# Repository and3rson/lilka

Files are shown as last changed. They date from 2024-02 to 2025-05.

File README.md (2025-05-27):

# Лілка






[][discord]

DIY-консоль, яку можна зібрати з дешевих готових модулів.

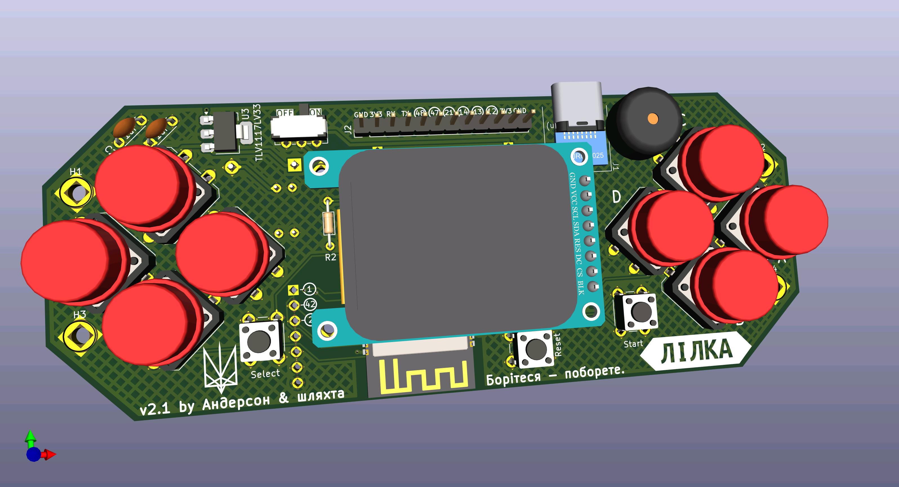
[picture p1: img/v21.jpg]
Лілка v2


## Де її можна купити?

Всі посилання та інструкції доступні [ось тут](https://lilka.dev/shop/)!

## Демо

Новини про проєкт Лілка V2:

Новини про проєкт "Лілка (https://www.youtube.com/watch?v=Xh49N__p2jE)

Перша версія Лілки:

Проєкт "Лілка" (https://www.youtube.com/watch?v=6Tz70vqRrs0)

## Документація

Повна документація проєкту буде доступна ось тут: <https://docs.lilka.dev>

## Спільнота

Приєднуйтесь до [нашого сервера в Discord][discord]!

## Я хочу допомогти писати код!

Ми будемо тільки раді! Є декілька варіантів:

- Хочете написати гру, програму, документацію чи щось таке? Звісно! Документація є [тут (C++)](https://docs.lilka.dev/uk/latest/keira/custom_apps/) і [тут (Lua)](https://docs.lilka.dev/uk/latest/keira/lua/intro/).
- Хочете допомогти з вдосконаленням коду? Виконайте команду `make todo` - вона відобразить всі TODO з коду, де потрібна допомога.
- Хочете допомогти ідейно? Знайшли баг або маєте ідею щодо покращення архітектури? Створіть новий тікет або пишіть в наш [Discord][discord] в форум `#лілка`.

[discord]: https://discord.gg/HU68TaKCu6

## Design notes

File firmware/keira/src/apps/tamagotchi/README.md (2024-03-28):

# ArduinoGotchi - A real Tamagotchi emulator for Arduino UNO

## Synopsis

**ArduinoGotchi** is a real [Tamagotchi P1](https://tamagotchi.fandom.com/wiki/Tamagotchi_(1996_Pet)) emulator running in Arduino UNO hardware. The emulation core is based on [TamaLib](https://github.com/jcrona/tamalib) with intensive optimization to make it fit into UNO's hardware that only comes with 32K Flash 2K RAM.

Tamagotchi P1 Actual Devices

## Fork notice

I did following changes after forking [original repo](https://github.com/GaryZ88/ArduinoGotchi)
- Created platformio project, so it is easy to target multiple platforms
- Created ports for ESP8266 and ESP32, mainly because speed on 8-bit AVR is just too slow
- Added long click on "back" button - if you press it for 5 seconds, it will reset memory back to egg state
- Added inverted Speaker connection setting. Mainly because Piezo modules that I have are active on Low. Another reason is mention below.

I personally assembled ESP8266 version with Wemos D1 Mini on perfboard, using built-in LED together with speaker, so when it sounds, led is blinking as well.

### Demo
Demo #1
Demo #2
Demo #3

## How to build and run

Use Platformio. Run `build` task to build for all platforms. Next run `Upload` task for specific platoform

### Additional notes
- To activate your pet, you have to configure the clock by pressing the middle button. Otherwise, your pet will not alive.
- The emulator will save the game status for every 5 mintues. You can change that by changing AUTO_SAVE_MINUTES setting
- The speed of the emulator is a bit slower than the actual Tamagotchi device on AVR, still, it is fun. On ESPs it runs smooth.
- There are a few consts in the `platformio.ini` that you can adjust to fit your need:
```
  -D DISPLAY_I2C_ADDRESS=0x3C
  -D SCREEN_WIDTH=128
  -D SCREEN_HEIGHT=64
  -D ENABLE_TAMA_SOUND
  -D ENABLE_TAMA_SOUND_ACTIVE_LOW
  -D ENABLE_AUTO_SAVE_STATUS
  -D ENABLE_LOAD_STATE_FROM_EEPROM
```

### Circuit Diagram
Circuit Diagram

### Wemos D1 Mini






### License
ArduinoGotchi is distributed under the GPLv2 license. See the LICENSE file for more information.

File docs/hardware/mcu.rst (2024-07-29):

.. _mcu:

Мікроконтролер
==============

Лілка використовує :term:`мікроконтролер` ``ESP32-S3-WROOM-1-N16R8``.
На відміну від ``ESP32-S3``, "WROOM" - це модуль, який містить в собі не лише сам мікроконтролер ``ESP32-S3``, а й флеш-пам'ять, додаткову оперативну пам'ять, кристал, антену та інші компоненти, необхідні для повноцінної роботи мікроконтролера.
Це дозволяє значно спростити розробку плати, оскільки вся "обв'язка" мікроконтролера вже виконана на модулі, а також полегшити збір, оскільки модуль можна встановити на плату за допомогою простого :term:`SMD`-монтажу звичайним паяльником.

.. list-table::
   :header-rows: 1
   :align: center

   * - ESP32-S3
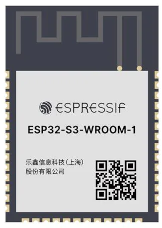
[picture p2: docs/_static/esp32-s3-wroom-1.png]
ESP32-S3-WROOM-1
     - 
   * - ESP32-S3
     - ESP32-S3-WROOM-1

Характеристики ESP32-S3 наступні:

- **Частота процесора: 240 МГц**
- **Кількість ядер: 2**
- **Оперативна пам'ять: 512 КБ**
- **Вбудований Wi-Fi (802.11 b/g/n)**
- **Вбудований Bluetooth (BLE)**
- **45 пінів** :term:`GPIO`
- ROM: 384 КБ (використовується внутрішньо, не доступний для користувача)
- 4 шини SPI (2 з них доступні для користувача)
- 2 шини I2S
- 2 шини I2C
- 3 шини UART
- 8-канальний :term:`ШІМ`-контролер
- 2 10-канальні 12-бітні :term:`АЦП`
- Апаратний криптографічний прискорювач (AES, RSA, RNG, HMAC)
- USB-контролер (з підтримкою USB-OTG та CDC, що дозволяє програмувати мікроконтролер через USB без додаткового UART-перетворювача)

Модуль ``ESP32-S3-WROOM-1-N16R8`` містить в собі деякі додаткові компоненти:

- Суфікс ``N16`` означає наявність **16 MB Flash-пам'яті типу NOR** (для зберігання прошивки та вбудованої файлової системи SPIFFS).
- Суфікс ``R8`` означає наявність **8 MB PSRAM** (додаткова оперативна пам'ять).
- **36 пінів** :term:`GPIO` (5 з них використовуються для USB та внутрішньої пам'яті)
- Кристал, необхідний для роботи мікроконтролера
- Антена
- Конденсатори та інші компоненти

.. tip:: Відмінною властивістю ESP32-S3 є наявність вбудованого мультиплексора GPIO, який дозволяє використовувати апаратний SPI, I2C, I2S, UART та інші шини на будь-яких GPIO-пінах.

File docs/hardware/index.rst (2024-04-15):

:octicon:`cpu` Технічні дані
============================

.. toctree::
    :maxdepth: 2
    :caption: Зміст

    mcu
    schematics

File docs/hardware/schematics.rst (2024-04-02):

Креслення (V2)
==============

Електронна схема (v2)
---------------------

  * Завантажити PDF: :download:`PDF <../_gen/v2_schematic.pdf>`
  * `Онлайн-перегляд схеми <https://kicanvas.org/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>`_

Креслення PCB (v2)
------------------

  * Завантажити PDF: :download:`PDF <../_gen/v2_pcb.pdf>`
  * `Онлайн-перегляд друкованої плати <https://kicanvas.org/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>`_

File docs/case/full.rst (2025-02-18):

Моделі корпусів
===============

    .. warning:: 

        Уважно читайте інструкцію до кожної моделі, перш ніж розпочинати її друк! Кожен корпус має свої особливості та розрахований на різні моделі акумуляторів. 
        Також збірка плати для конкретного корпусу може дещо відрізнятися від тієї, що описана в документації.

**Корпус з кришечкою на пінах, для легкого доступу до них**  

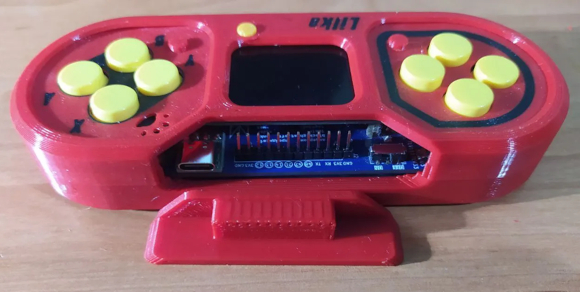
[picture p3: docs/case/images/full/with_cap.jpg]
З_кришечкою

   
Посилання:
https://www.printables.com/model/1173882-slim-case-for-lilka

**Мінімалістичний корпус без додаткових вставних частин**

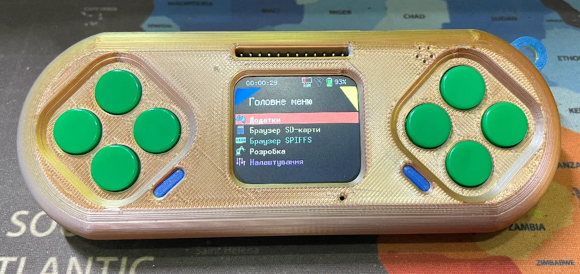
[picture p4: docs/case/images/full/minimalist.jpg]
Мінімалістичний


Посилання:
https://www.printables.com/model/1120079-lilcase  

**Корпус в стилі "Quadratisch.Praktisch.Gut"**

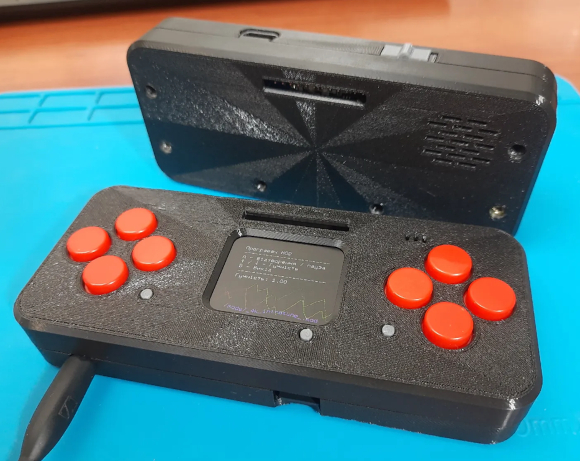
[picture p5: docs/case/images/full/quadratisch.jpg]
Квадратіш


Посилання:
https://www.printables.com/model/1181426-low-profile-case-for-lilka-dev-board

**Мінімалістичний корпус без заглиблень під кнопки**

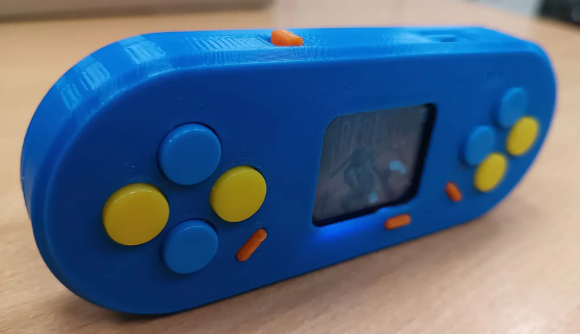
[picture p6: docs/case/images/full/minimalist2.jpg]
Мінімалістичний2


Посилання:
https://www.printables.com/model/1189054-case-for-lilka-dev-board

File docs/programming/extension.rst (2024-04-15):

.. _extension:

Роз'єм розширення
=================

.. contents:: Зміст
    :local:
    :depth: 1

Загальна інформація
-------------------

Роз'єм розширення (англ. *extension header*) - це роз'єм, який дозволяє підключати до основної плати додаткові модулі, наприклад датчики, дисплеї, сервоприводи тощо.

Лілка має 12-контактний роз'єм розширення.

Ці піни можна використовувати для будь-якої цілі. Саме тому вони і називаються GPIO (General Purpose Input/Output) - вхід/вихід загального призначення.



На роз'єм розширення Лілки виведені наступні піни:

- ``3.3V`` - живлення 3.3 Вольти
- ``GND`` - земля
- ``12``, ``13``, ``14``, ``21``, ``47``, ``48`` - GPIO
- ``TX``, ``RX`` - додатковий UART. Ці піни можна використати для з'єднання Лілки з комп'ютером через перетворювач USB-UART та навіть прошивати її через цей порт. Але ви також можете без проблем використовувати ці піни для будь-яких інших цілей в додачу до перелічених вище пінів, а для прошивання використовувати USB-порт Лілки.

Вони не використовуються Лілкою для жодних внутрішніх потреб, тому ви можете використовувати їх для будь-яких цілей.

Завдяки вбудованому мультиплексору, кожен пін можна використовувати для шин I2C, SPI, UART, або просто як вхід/вихід.

Крім того, піни ``12``, ``13`` та ``14`` під'єднані до АЦП (аналого-цифрового перетворювача, ADC):

- ``12`` - ADC2, канал 1
- ``13`` - ADC2, канал 2
- ``14`` - ADC2, канал 3

Приклад використання GPIO
-------------------------

Найпростіший приклад використання GPIO - це підключити до роз'єму розширення світлодіод та резистор, щоб світлодіод світився, коли на пін подаватиметься напруга.

Наприклад, пін ``12`` можна підключити до анода світлодіода (довший вивід), а катод світлодіода (коротший вивід) - через резистор до землі (наприклад, 100 Ом).

Обчислити значення резистора для світлодіода можна за `цим посиланням <https://www.digikey.com/en/resources/conversion-calculators/conversion-calculator-led-series-resistor>`_.



Після цього можна використати наступний код для того, щоб світлодіод блимав:

.. code-block:: cpp

    #include <lilka.h>

    void setup() {
        lilka::begin();
    }

    void loop() {
        digitalWrite(12, HIGH);
        delay(500);
        digitalWrite(12, LOW);
        delay(5000);
    }

Використання GPIO для шини I2C
------------------------------

Щоб використати піни розширення для шини I2C, використайте наступний код:

.. code-block:: cpp

    #include <lilka.h>
    #include <Wire.h>

    #define SDA_PIN 13
    #define SCL_PIN 14

    void setup() {
        lilka::begin();
        Wire.begin(SDA_PIN, SCL_PIN);
    }

    void loop() {
        // Почати передачу на адресу 0x42
        Wire.beginTransmission(0x42);
        // Надіслати байт 66
        Wire.write(0x42);
        // Завершити передачу
        Wire.endTransmission();
        delay(1000);
    }

Використання GPIO для шини SPI
------------------------------

Щоб використати піни розширення для шини SPI, використайте наступний код:

.. code-block:: cpp

    #include <lilka.h>

    #define SCK_PIN 12
    #define MISO_PIN 13
    #define MOSI_PIN 14
    #define SS_PIN 21

    void setup() {
        lilka::begin();

        // Ми використовуємо SPI2, тому що SPI1 використовується для внутрішніх потреб Лілки (для дисплея та SD-картки)
        lilka::SPI2.begin(SCK_PIN, MISO_PIN, MOSI_PIN, SS_PIN);
    }

    void loop() {
        // Починаємо транзакцію: швидкість - 1 МГц, порядок байтів - MSB, режим SPI - 0
        lilka::SPI2.beginTransaction(SPISettings(1000000, MSBFIRST, SPI_MODE0));
        // Активуємо пристрій
        digitalWrite(SS_PIN, LOW);
        // Надсилаємо байт 66
        lilka::SPI2.transfer(0x42);
        // Деактивуємо пристрій
        digitalWrite(SS_PIN, HIGH);
        // Завершуємо транзакцію
        lilka::SPI2.endTransaction();
        delay(1000);
    }

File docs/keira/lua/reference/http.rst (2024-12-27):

``http`` - Робота з HTTP запитами
---------------------------------

Функції для виконання HTTP запитів.

Приклад:

.. code-block:: lua
    :linenos:

    -- збереження результату в файл
    local request = {
        url = "https://a.tile.openstreetmap.org/12/2395/1381.png",
        file = "/12/2395/1381.png"
    }
    local response = http.execute(request)
    console.print("Result:", response.code)

    -- повернення результату у вигляді рядка
    request = {
        url = "https://api.appstoreconnect.apple.com/v1/devices"
    }
    local response = http.execute(request)
    console.print(response.code, response.response)

.. lua:autoclass:: http

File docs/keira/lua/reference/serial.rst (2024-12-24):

``serial`` - Робота з UART1
-------------------------------

Функції для читання/запису даних з UART1
Підключення до UART1 здійснюється через піни RX 47 та TX 48, які знаходяться на роз'ємі розширення.

Приклад:

.. code-block:: lua
    :linenos:

    local buffer = 'a'
    local up, down = false, false

    function lilka.init()
        serial.begin(115200);
    end

    function lilka.update(delta)
        while serial.available() > 0 do
            buffer = buffer .. serial.read(serial.available())
            if string.len(buffer) > 40 then
                console.print(buffer)
                buffer = 'a'
            end
        end

        local keyboard = controller.get_state()
        if keyboard.up.pressed or keyboard.down.pressed then
            serial.print("button: ")
            if keyboard.up.pressed then
                serial.println("up")
            elseif keyboard.down.pressed then
                serial.println("down")
            end
        end
        if keyboard.b.pressed then
            util.exit()
        end
    end

    function lilka.draw()
        display.fill_screen(display.color565(0, 0, 0))
        display.set_cursor(20, 20)
        display.print(buffer)
    end

.. lua:autoclass:: serial

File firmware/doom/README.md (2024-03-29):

# Doom для Лілки!

Це - порт Doom для Лілки.

[lib/doomgeneric](./lib/doomgeneric) містить модифікований код рушія Doom Generic для запуску на ESP32-S3.
Я додав динамічну алокацію пам'яті для деяких "товстих" масивів, щоб використовувати PSRAM. Таким чином весь основний код Doom тепер спокійно поміщається в 400 КБ основної RAM. Крім цього, є ще деякі зміни (див. [README](./lib/doomgeneric)).

[src/main.cpp](./src/main.cpp) містить код, специфічний для Лілки (малювання екрана, ініціалізація, etc).

Решта файлів в `src` - це звукові драйвери для I2S (з простим міксуванням звуку) та п'єзодинаміка.

Звісно, для того, щоб пограти в Doom, вам додатково потрібно мати файл `doom.wad`. Його можна купити або завантажити в інтернеті. Його потрібно покласти в корінь SD-карти.

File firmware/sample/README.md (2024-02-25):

Зразок прошивки для Лілки
=========================

Це - мінімальний зразок програми, яку ви можете використати як шаблон для створення власної прошивки для Лілки.

Вона використовує PlatformIO.

Інструкцію з прошивання Лілки з використанням Visual Studio та PlatformIO можна прочитати [ось тут](https://docs.lilka.dev/uk/latest/manual/environment.html).

Крім того, цю прошивку можна зібрати та записати в Лілку за допомогою консолі:

```sh
pio run -t upload
```

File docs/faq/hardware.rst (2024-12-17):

Апаратна частина
================

.. contents:: Зміст
   :local:

Я не можу завантажити прошивку на свій пристрій. Що робити?
-----------------------------------------------------------

Переконайтеся, що ви використовуєте саме так званий "data" кабель, а не "power" кабель. "Power" кабель призначений лише для заряджання пристрою, а "data" кабель - і для передачі даних, і для заряджання.

.. warning:: Зверніть увагу: Лілка не підтримує USB 3.0, тому ви не зможете прошивати її через кабель Type C - Type C. Використовуйте кабель Type C - Type A.

Чому Лілка не розпізнає карту пам’яті? Чому карта пам’яті працює нестабільно?
-----------------------------------------------------------------------------
Причин цьому може бути багато. Ось найпоширеніші із них:

1. У вас встановлено неактуальну версію платформи "Espressif 32". Видаліть та завантажте заново "Espressif 32" у менеджері платформ "Platformio". Після цього перекомпілюйте прошивку для Лілки.  

2. Карту пам’яті не було коректно форматовано перед використанням. Відформатуйте SD-карту на ПК у файлову систему FAT32. Якщо у вас немає картридера, для форматування можна використати Android-смартфон зі встановленим додатком "File Manager +" або будь-яким іншим, що має таку функцію. Також коректно форматувати карту можуть деякі кнопкові телефони з підтримкою microSD.  

3. Живлення плати Лілки нестабільне. Можливо, у вас на плату потрапляють електромагнітні завади або підключені модулі споживають більше струму, ніж може стабільно видавати лінійний стабілізатор напруги, що входить в комплект до плати. Спробуйте замінити С2 та С3 на платі на конденсатори з більшою ємністю. Наприклад, по 5 мкФ+.

4. Карта пам’яті працює нестабільно. Зазвичай таке буває, якщо вам не пощастило придбати дуже специфічну підробку. Спробуйте використати карту пам’яті від іншого виробника.

5. Неякісна пайка компонентів. Можливо, під час збірки ви погано припаяли мікроконтролер/роз’єм карти пам’яті або замкнули лінії, по яких карта керується.

6. Дефектний роз’єм microSD або проблеми з виводами мікроконтролера, які керують картою пам’яті. Якщо ви перевірили декілька карт пам’яті на своїй платі Лілки і жоден із перелічених пунктів вам не допоміг, варто задуматися про заміну роз’єму або модуля ESP32-S3.

.. warning::
    Лілка не підтримує функцію гарячої заміни карти пам'яті, тобто карта повинна бути встановлена в роз'єм до увімкнення пристрою.

Що це за цифри в кружечках на платі Лілки?
------------------------------------------

Цифри в кружечках на платі Лілки - це номери GPIO-пінів мікроконтролера, які позначають, до якого GPIO підключений той чи інший компонент Лілки.

.. warning::

    Не плутайте номери GPIO з номерами пінів! Наприклад, GPIO8 - це пін 12, а не 8. Радимо вам завжди користуватися номерами GPIO, а не номерами пінів - як в коді, так і в документації.

    Детальніше про піни ESP32-S3-WROOM-1 можна дізнатися в `офіційній документації ESP32-S3-WROOM-1 <https://www.espressif.com/sites/default/files/documentation/esp32-s3-wroom-1_wroom-1u_datasheet_en.pdf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>`_.

Якщо ви хочете підключити до Лілки якийсь сторонній модуль, ми рекомендуємо використовувати для цього :ref:`extension`, де жоден пін не зайнятий внутрішніми компонентами Лілки.

Але оскільки Лілка - це відкрита :term:`DIY`-консоль, ніхто не забороняє вам використовувати будь-які піни з нестандартною метою.
Проте майте на увазі, що в такому випадку :ref:`lilka-lib` не працюватиме належним чином, оскільки вона очікує, що до цих пінів будуть підключені конкретні відомі їй компоненти.
Тому вам доведеться самостійно писати власний код для роботи з цими пінами.

Моя програма взаємодіє одночасно з SD-картою та дисплеєм, але вона працює дуже повільно!
----------------------------------------------------------------------------------------

Для роботи з SD-картою та дисплеєм Лілка використовує одну шину SPI.

Це означає, що в будь-який момент часу шина може бути зайнятою або SD-картою, або дисплеєм, і спроба взаємодії з одним пристроєм, коли інший пристрій використовує шину, призведе до затримок і,
як наслідок, до зниження частоти кадрів та швидкості читання/запису файлів.

Для цього є декілька причин:

- Це дозволяє зменшити кількість пінів, задіяних для підключення SD-карти та дисплею.
- ESP32-S3 має всього дві шини SPI, тому використання однієї шини для обох пристроїв дозволяє звільнити іншу шину для потреб користувача (наприклад, для підключення зовнішньої камери чи акселерометра).

Щоб уникнути цих затримок, потрібно уникати роботи з SD-картою та дисплеєм одночасно.
Найпростіший спосіб - це читати дані з SD-карти в пам'ять PSRAM (в ESP32-S3 її достатньо багато - аж 8 МБ), і надалі працювати з цими даними, не взаємодіючи з SD-картою.

Враховуючи, що (станом на момент написання цього документу) SD-карта працює на частоті 25 МГц, читання файлу розміром 1 МБ з SD-карти за ідеальних умов займе менше однієї секунди!

Тому, якщо ви пишете гру, яка завантажує текстури чи звуки з SD-карти, просто завантажте їх у пам'ять PSRAM один раз при запуску гри і надалі працюйте з ними вже з пам'яті, не взаємодіючи з SD-картою.

Чому ви не вивели `GPIO35`, `GPIO36` та `GPIO37` на роз'єм розширення?
----------------------------------------------------------------------

Ці піни можна використовувати лише в деяких (менш потужних) варіантах ESP32-S3-WROOM.

В ESP32-S3-WROOM-N16R8, який використовується в Лілці, ці піни використовуються для внутрішіх потреб (а точніше - для спілкування мікроконтролера ESP32-S3 з пам'яттю PSRAM).

Тому використовувати їх для будь-яких інших цілей заборонено.

Чому ви не вивели `GPIO45` на роз'єм розширення?
------------------------------------------------

`GPIO45` - це один з так званих "strapping" пінів, які використовуються для вибору режиму завантаження мікроконтролера та інших налаштувань.

Використання цього піна небезпечне, оскільки він встановлює режим напруги SPI-шини. Тому ми вирішили не виводити його на роз'єм розширення, щоб уникнути можливих проблем та потенційних пошкоджень пристрою.

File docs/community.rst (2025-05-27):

:octicon:`people` Спільнота
===========================

``Rustilka``: Rust для Лілки
----------------------------

Автор: **imbir**

Rustilka - це мініпроєкт підтримки мови Rust для Лілки, який має таку саму мету, як і сама консоль - "полегшити" розробку.

Також цей проєкт чисто технічно незалежний від оригінального SDK: при наявності можливостей ми могли б мати IDF версію, але, на думку автора Rustilka, це не має сенсу.

`Хочете писати код для Лілки на Rust? Тоді вам сюди! <https://rust.lilka.dev>`_

``MeowUI``: Альтернативний UI-фреймворк для Лілки
-------------------------------------------------

Автор: **kolodieiev**

MeowUI - набір бібліотек, що спрощують створення графічного інтерфейсу користувача для електронних пристроїв на базі esp32 та esp32s3.

З самого початку даний проєкт створювався, як шаблон, для швидкої побудови багаторівневого графічного інтерфейсу в стилі “Quadratisch. Praktisch. Gut”.
Мета - управління різноманітними датчиками за допомогою мікроконтролера ESP32.

Після знайомства з проєктом "Лілка", автором MeowUI було прийнято рішення про розширення та доопрацювання функціоналу MeowUI.

`Детальніше про проєкт можна дізнатися тут. <https://github.com/Kolodieiev/MeowUI>`_

Спілкування
-----------

- Весь код проєкту доступний на `GitHub <https://github.com/lilka-dev/lilka>`_.
- Приєднуйтесь до нашого `Discord-сервера <https://discord.gg/HU68TaKCu6>`_!

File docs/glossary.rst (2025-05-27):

:octicon:`database` Словник термінів
====================================

.. glossary::

   DIY
    "Do It Yourself", тобто "зроби сам". Спосіб виготовлення чи збору різних речей своїми руками.

   Мікроконтролер
    Електронний пристрій, який містить в собі процесор, пам'ять та виводи для підключення до різних пристроїв.

    Використовується для автоматизації різних процесів, включаючи керування іншими пристроями, збір та обробку даних тощо.

   Прошивка
    Скомпільована програма, яка виконується на мікроконтролері.

    Переважно є бінарним файлом з розширенням ``.bin``, який записується в пам'ять мікроконтролера, але також може бути завантажена в мікроконтролер WiFi, SD-карту тощо.

    Компіляція та завантаження прошивки в мікроконтролер зазвичай виконується за допомогою спеціальних програм, наприклад, :term:`PlatformIO`.

   Прошивання
    Процес запису прошивки в пам'ять мікроконтролера. Переважно здійснюється через такі інтерфейси, як USB або WiFi.

   OTA
    "Over-The-Air", тобто "через мережу": прошивання без кабельного підключення до комп'ютера. Процес прошивання через мережу або з SD-карти.

   PlatformIO
    Крос-платформене середовище для розробки програмного забезпечення для вбудованих систем, яке базується на відкритому коді та підтримується спільнотою.

    Включає в себе відладчик, засоби для роботи з прошивками, бібліотеками, платами тощо.

   Visual Studio Code
    Відкритий та безкоштовний крос-платформений редактор коду.

    Має велику кількість розширень, які дозволяють розширити його функціонал, зокрема підтримку :term:`PlatformIO`.

   Git
    Система керування версіями файлів та спільної роботи над ними.

    Дозволяє зберігати кілька версій файлів, відслідковувати зміни, відновлювати втрачені версії тощо.

    Весь код Лілки та Doom, всі креслення та навіть вся ця документація зберігаються саме в Git в `репозиторії на GitHub <https://github.com/lilka-dev/lilka>`_ і доступні для всіх бажаючих абсолютно безкоштовно.

   Lua
    Легка скриптова мова програмування, яка використовується для написання скриптів та програм для вбудованих систем.

    Вона чудово підходить для :ref:`написання ігор <lua-intro>`!

   PCB
    "Printed Circuit Board", тобто "друкована плата". Плата, на якій розміщені електронні компоненти.

   THT
    "Through-Hole Technology", тобто "технологія з монтажем через отвори". Технологія монтажу електронних компонентів на плату через отвори.

   SMD
    "Surface-Mount Device", тобто "прилади з монтажем на поверхню". Технологія монтажу електронних компонентів на поверхню плати.

   GPIO
    "General Purpose Input/Output", тобто "вхід/вихід загального призначення". Виводи мікроконтролера, які можуть використовуватися як вхід або вихід.

   ЦАП
    Цифро-аналоговий перетворювач ("Digital-to-Analog Converter", або "DAC"). Електронний пристрій, який перетворює цифрові сигнали (конкретні числа) в аналогові (тобто напругу).

    Найчастіше використовується для відтворення звуку.

    **Розрядність (resolution)** визначає кількість можливих значень аналогового сигналу. Наприклад, ЦАП 8-бітний має розрядність 8 біт, тобто може відтворювати 2^8 = 256 різних значень.

   АЦП
    Аналого-цифровий перетворювач ("Analog-to-Digital Converter", або "ADC"). Електронний пристрій, який перетворює аналогові сигнали (тобто напругу) в цифрові (конкретні числа).

    Найчастіше використовується для зчитування значень з датчиків, потенціометрів та акумуляторів.

    **Розрядність** визначається так само, як і в :term:`ЦАП`.

   ШІМ
    Широтно-імпульсна модуляція ("Pulse-Width Modulation", або "PWM"). Підхід керування напругою або струмом, при якому відсутній постійний струм або напруга, але є швидкі зміни напруги або струму.

    Найчастіше використовується для керування яскравістю світлодіодів та обертання сервоприводів.

    Наприклад, щоб керувати яскравістю світлодіода, можна використовувати ШІМ: якщо швидко вмикати-вимикати світлодіод (наприклад, вмикати на 25% часу, а вимикати на 75% часу), то він буде світитись з яскравістю, яка відповідає 25% максимальної.

    **Частота (frequency)** визначається частотою вмикання-вимикання. Наприклад, якщо вмикати та вимикати світлодіод 1000 разів на секунду, то частота ШІМ буде 1000 Гц, або 1 кГц.

    **Прогальність (duty cycle)** визначається часом вмикання відносно часу вимикання. Наприклад, якщо вмикати світлодіод 25% часу, а решту часу - вимикати, то прогальність дорівнюватиме 25%.

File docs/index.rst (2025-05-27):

.. Lilka documentation master file, created by
   sphinx-quickstart on Tue Feb 20 21:34:30 2024.
   You can adapt this file completely to your liking, but it should at least
   contain the root `toctree` directive.

Вітаємо вас у документації проєкту Lilka!
=========================================

.. toctree::
    :maxdepth: 2
    :caption: Зміст:

    about/index
    hardware/index
    assembly/index
    programming/index
    keira/index
    library/index
    case/index
    faq/index
    glossary
    community
    contributing/index

.. .. sidebar-links::
..     :caption: Посилання:
..     :github:

.. toctree::
    :caption: Посилання

    GitHub <https://github.com/lilka-dev/lilka>
    Discord <https://discord.gg/HU68TaKCu6>

.. toctree::
    :caption: Проєкти нашої спільноти

    "Rustilka": Rust для Лілки <https://rust.lilka.dev>
    "Meowui": альтернативний UI для Лілки <https://github.com/Kolodieiev/lilka_v2_meowui>

Indices and tables
==================

* :ref:`genindex`

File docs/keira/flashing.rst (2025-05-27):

.. _keira-flashing:

Запуск
======

Лілка постачається з готовою прошивкою Keira, яка вміє багато різних речей. Ця прошивка використовується для :ref:`демонстрації можливостей Лілки, а також як приклад для розробки власних програм <keira-firmware-features>`.

В цьому розділі ми розглянемо, як завантажити операційну систему Keira в Лілку.

Клонування репозиторію та побудова прошивки
-------------------------------------------

1. Перейдіть на вкладку **Source Control** (``Ctrl`` + ``Shift`` + ``G``) та клонуйте репозиторій `Lilka <https://github.com/lilka-dev/lilka>`_:

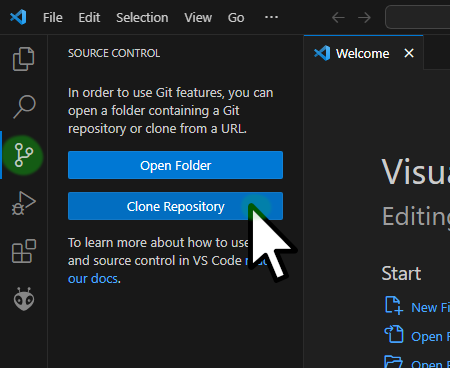
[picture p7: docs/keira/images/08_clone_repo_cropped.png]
   

   Для цього натисніть "**Clone Repository**" та введіть адресу репозиторію:

   ``https://github.com/lilka-dev/lilka``

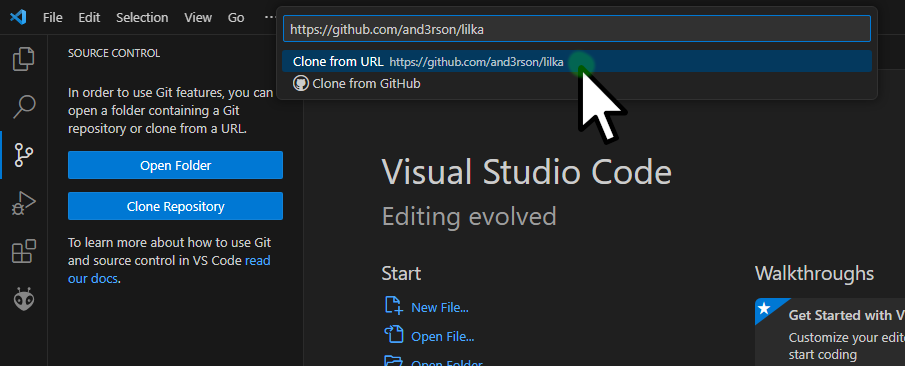
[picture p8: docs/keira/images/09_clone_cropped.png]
   

2. Після клонування репозиторію перейдіть на вкладку **PlatformIO** та імпортуйте проєкт прошивки Keira для Лілки. Для цього натисніть "**Open Project**" та виберіть директорію ``lilka/firmware/keira``.

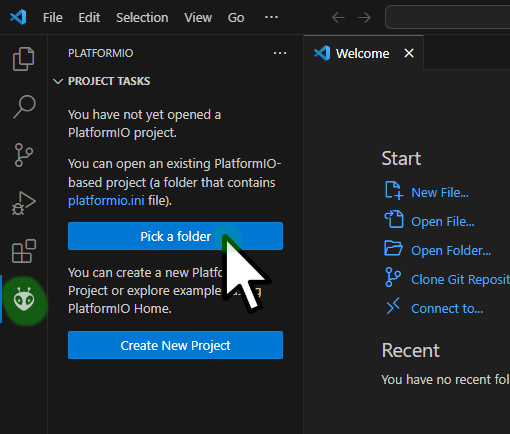
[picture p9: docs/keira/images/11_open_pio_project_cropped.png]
   

3. Тепер нам потрібно дочекатися налаштування середовища розробки.

   **PlatformIO** автоматично встановить необхідні залежності, такі як компілятори, бібліотеки та інші інструменти, що необхідні для написання програм для Лілки.

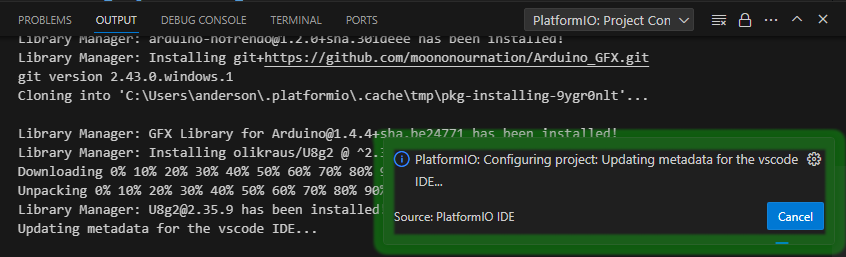
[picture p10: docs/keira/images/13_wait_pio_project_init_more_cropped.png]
   

4. Після налаштування середовища розробки перейдіть на вкладку **PlatformIO** та виберіть ``v2`` в якості цільової платформи. Потім натисніть "**Build**".

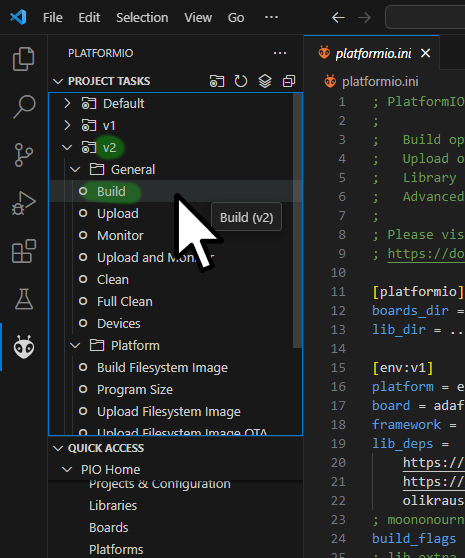
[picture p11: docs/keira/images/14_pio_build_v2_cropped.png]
   

   Тепер потрібно дочекатися завершення збірки. Перша збірка може зайняти деякий час.

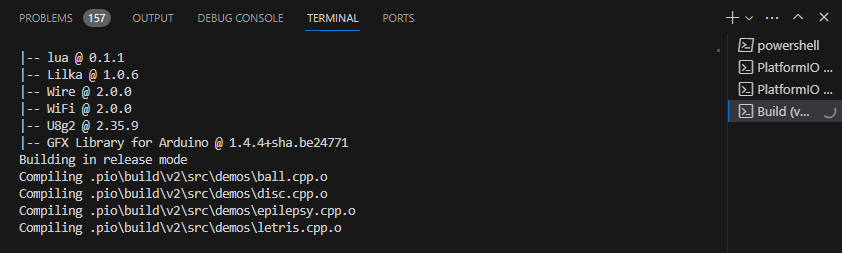
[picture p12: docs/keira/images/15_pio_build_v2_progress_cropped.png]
   

   Щойно збірка завершиться, ви побачите повідомлення про успішне завершення збірки:

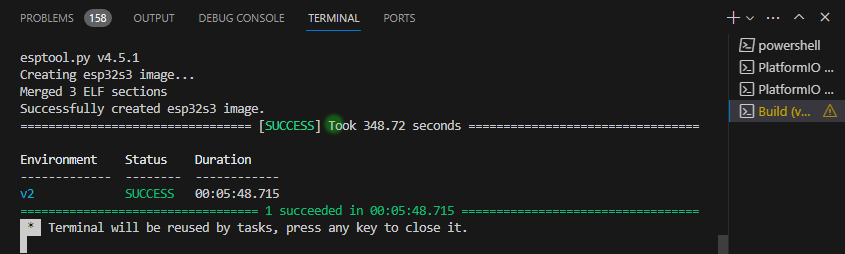
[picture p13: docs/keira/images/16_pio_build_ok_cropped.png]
   

Завантаження прошивки в Лілку
-----------------------------

1. Підключіть Лілку до комп'ютера за допомогою USB-кабеля та увімкніть її.

   .. warning:: Зверніть увагу: Лілка не підтримує USB 3.0, тому ви не зможете прошивати її через кабель Type C - Type C. Використовуйте кабель Type C - Type A.

   Windows може вимагати встановлення драйверів для Лілки. Якщо вам буде запропоновано встановити драйвери, встановіть їх.

   Після цього вимкніть Лілку.

   Тепер вам потрібно натиснути та утримувати кнопку ``SELECT`` і увімкнути Лілку. Після цього можна відпустити кнопку ``SELECT``.
   Це переведе Лілку в **режим завантаження** (**bootloader mode**): в цьому режимі ви можете завантажити в неї нову прошику.

2. Тепер перейдіть на вкладку **PlatformIO** та виберіть ``v2`` в якості цільової платформи. Потім натисніть "**Upload**".

   Спершу **PlatformIO** виконає підготовчі дії, а потім розпочне завантаження нашої свіжозібраної прошивки в Лілку.

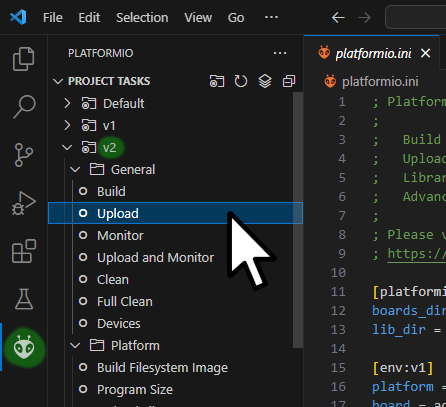
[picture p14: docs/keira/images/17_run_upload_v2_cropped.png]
   

   Початок завантаження виглядатиме ось так:

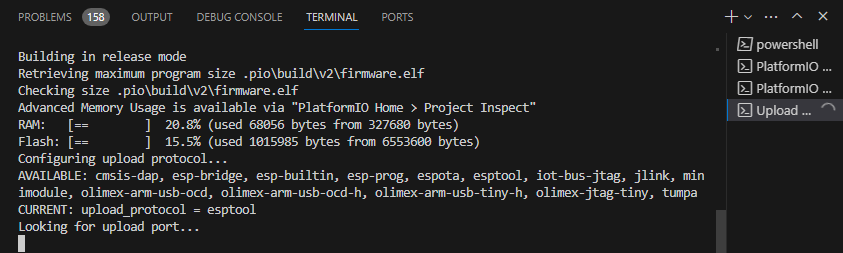
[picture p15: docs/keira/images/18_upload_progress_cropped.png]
   

   Тепер потрібно дочекатися завершення завантаження. Щойно завантаження завершиться, ви побачите повідомлення про успішне завершення завантаження:

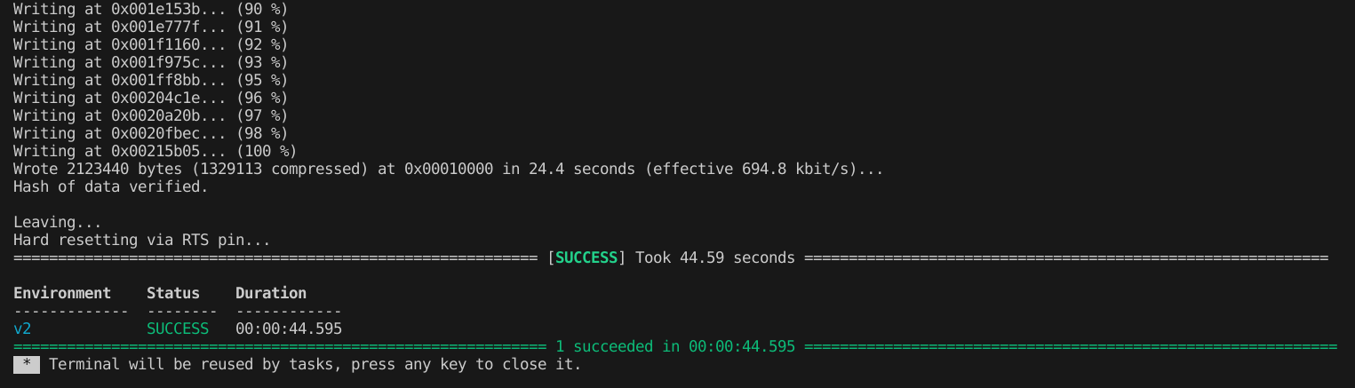
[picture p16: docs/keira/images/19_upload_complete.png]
   

3. Коли завантаження завершиться, натисніть кнопку ``RESET`` на Лілці та насолоджуйтесь новою прошивкою!

   .. tip::

        **Тепер вам не потрібно щоразу вручну переводити Лілку в режим завантаження, щоб завантажити нову прошивку!**

        Крім прошивки Keira, ви щойно завантажили в Лілку ще й програму-завантажувач (bootloader). Тепер ви можете завантажувати нові прошивки в Лілку безпосередньо з **PlatformIO**.

        Просто натисніть кнопку ``Upload`` в **PlatformIO** і вона автоматично переведе Лілку в режим завантаження та завантажить нову прошивку!

Вітаємо!
--------

Вітаємо, ви успішно налаштували середовище розробки та завантажили Keira в Лілку!

Ви можете потицяти Лілку та переконатися, що вона працює і спробувати різні демо. Також ви можете перейти на вкладку **Explorer** (``Ctrl`` + ``Shift`` + ``E``), відкрити файл ``src/main.cpp`` та поглянути, як виглядає код прошивки, яку ми щойно зібрали і запустили на Лілці.

Також ви можете запускати готові прошивки прямо з SD-карти, а також писати власні програми на Lua та запускати їх з SD-карти. Детальніше - в наступній частині документації: :doc:`features`.

**Лілка - це відкрита платформа**, тому ви можете змінювати код прошивки, додавати нові функції та вдосконалювати Лілку, або навіть створювати власні прошивки для неї. **Але перш ніж приступати до цього**, рекомендуємо ознайомитися з документацією бібліотеки ``lilka``, яка спрощує роботу з Лілкою, за :doc:`цим посиланням </library/index>`.

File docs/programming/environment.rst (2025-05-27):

Налаштування середовища розробки
================================

Отже, ви зібрали Лілку. Чи, можливо, якийсь інший пристрій на базі мікроконтролера ESP32. І ви хочете написати для нього програмне забезпечення. З чого почати?
(Саме так: багато що з цього документу може бути корисним і для інших пристроїв на базі ESP32, але ми будемо говорити здебільшого саме про Лілку.)

Для розробки програмного забезпечення для Лілки ми використовуємо середовище :term:`PlatformIO`, і дуже рекомендуємо вам теж спробувати його. До речі, **PlatformIO** - це український проект, і ми пишаємося тим, що він став таким популярним у всьому світі! 🇺🇦

**PlatformIO** - це набір інструментів для розробки вбудованого програмного забезпечення, який автоматизує процес збірки, завантаження та налагодження програмного забезпечення для мікроконтролерів.
Якщо ви колись працювали з Arduino IDE, то ви знаєте, що воно хоч і зручне, але має свої обмеження. **PlatformIO** - це таке собі "Arduino для дорослих".

**PlatformIO** автоматично встановлює необхідні залежності, такі як компілятори, бібліотеки та інші інструменти, що необхідні для написання програм.

В цьому документі описано процес налаштування середовища розробки для Лілки з використанням **PlatformIO** та **Visual Studio Code** для **ОС Windows**.

Якщо ви використовуєте **MacOS**, процес буде схожим, але можуть бути деякі відмінності в налаштуваннях. А якщо ви використовуєте **GNU/Linux**, то ви, скоріш за все, вже й так знаєте, що робити, і цей документ вам не потрібен. ;)

1. Встановіть **Visual Studio Code** з офіційного сайту: https://code.visualstudio.com/

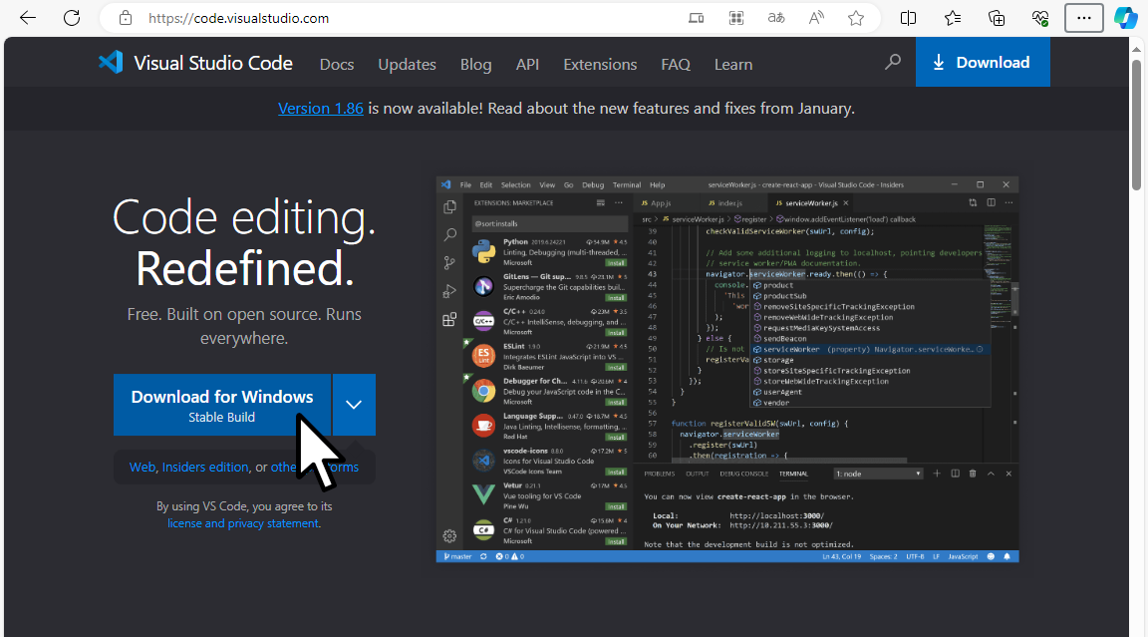
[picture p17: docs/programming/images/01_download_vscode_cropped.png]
   

2. Запустіть **Visual Studio Code** та встановіть плагін **PlatformIO IDE**.

   Для цього відкрийте вкладку **Extensions** (``Ctrl`` + ``Shift`` + ``X``), введіть "**PlatformIO**" в поле пошуку та встановіть плагін.

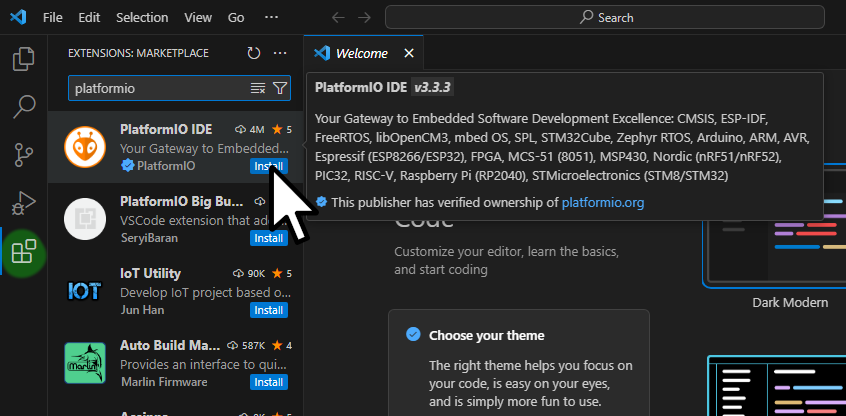
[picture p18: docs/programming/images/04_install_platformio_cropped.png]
   

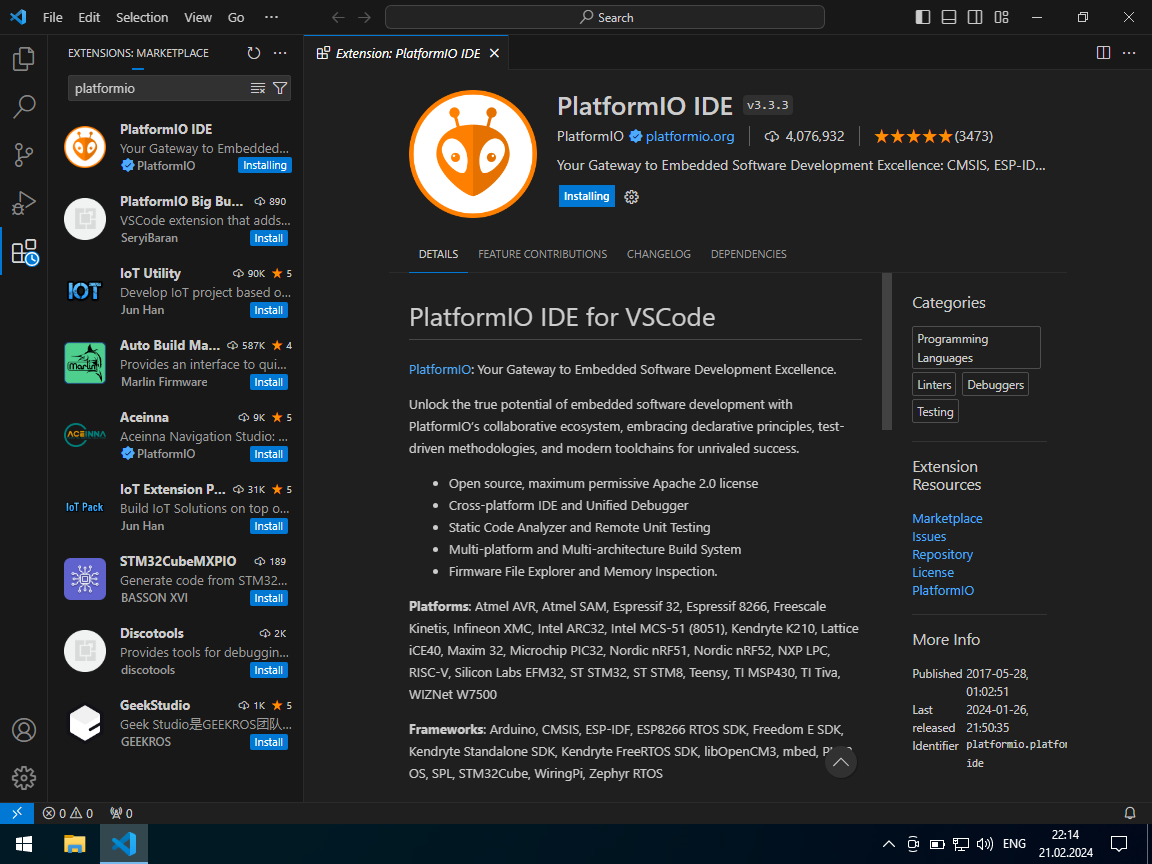
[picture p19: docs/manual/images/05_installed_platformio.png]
   .. 
   ..     :width: 80%

3. Тепер нам потрібно встановити **Git**.

   **Git** - це система керування версіями, яка дозволяє ділитися кодом з іншими розробниками та використовувати код з відкритих репозиторіїв.

   Весь код для Лілки, а також бібліотеки, які використовуються в проєкті, знаходяться на `GitHub <https://github.com/lilka-dev/lilka>`_, тому нам потрібно встановити **Git**, щоб здійснювати роботу з репозиторіями.

   Для встановлення **Git** перейдіть на вкладку **Source Control** (``Ctrl`` + ``Shift`` + ``G``) та натисніть "**Download Git for Windows**".

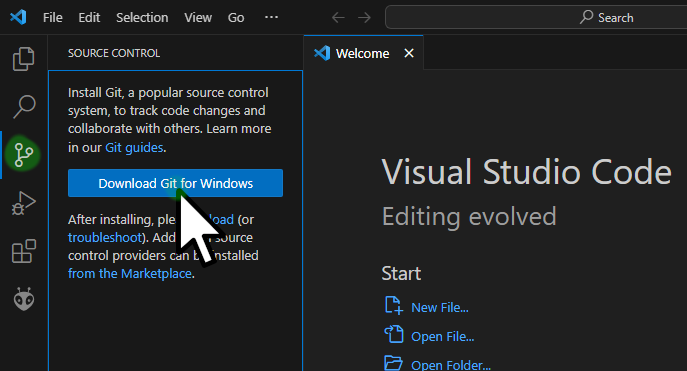
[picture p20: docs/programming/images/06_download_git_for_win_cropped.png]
   

   В процесі встановлення не змінюйте жодних параметрів, залиште все так, як є за замовчуванням, окрім кроку "**Choosing the default editor used by Git**".

   На цьому кроці виберіть "**Use Visual Studio Code as Git's default editor**".

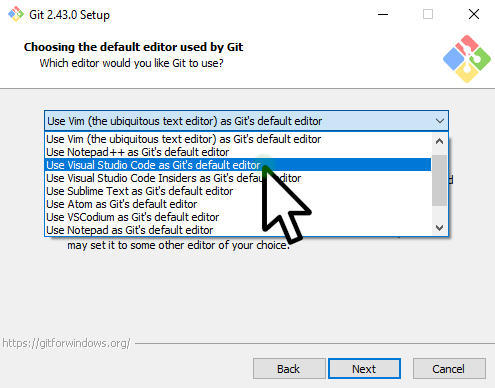
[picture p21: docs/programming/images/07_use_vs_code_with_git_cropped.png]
   

4. Після встановлення **Git** перезапустіть **Visual Studio Code**.

Тепер ви можете компілювати та завантажувати програми для Лілки, а також працювати з репозиторіями на **GitHub**.

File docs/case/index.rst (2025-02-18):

:octicon:`container` Виготовлення корпусу
=========================================

Наразі немає можливості придбати готовий корпус до Лілки в магазині. Тож, якщо ви хочете перетворити плату у повноцінний кишеньковий пристрій, 
вам доведеться самостійно надрукувати або замовити друк корпусу по 3D моделі.  

В цьому розділі зібрані посилання на моделі корпусів та компонентів до них, які розроблені учасниками спільноти. 
Ви можете безкоштовно використовувати та модифікувати їх для своїх потреб, але пам'ятайте про правила ліцензування!  
  
Поставити запитання щодо того чи іншого корпусу можна на Discord-каналі спільноти за посиланням: https://discord.com/channels/1202315568846213172/1209287458789793802.

.. toctree::
    :maxdepth: 1

    full
    parts

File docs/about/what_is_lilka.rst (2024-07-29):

Що таке Лілка?
--------------

Лілка - це консоль на базі :term:`мікроконтролера<Мікроконтролер>` ESP32-S3-WROOM-1-N16R8.

Її головна особливість - це те, що її можна легко зібрати з готових модулів, які продаються в магазинах.

Інший важливий фактор - це ціна: сумарна вартість всіх компонентів базового набору Лілки в Україні - близько 500-600 гривень.

Лілка

Мета цього пристрою - це насамперед навчання. Зібравши її, в вас в руках опиниться проста, але повноцінна залізяка з купою цікавих можливостей:

- :ref:`Емулятор NES <sd-card-feature>`, який дозволить вам грати в нінтендівські ігри
- Можливість :ref:`запускати DOOM <sd-card-feature>` з непоганим FPS
- Вбудований WiFi- та Bluetooth-передавач
- :ref:`Роз'єм розширення <extension>` для під'єднання власних модулів
- :ref:`Підтримка Lua <lua-intro>` для легкого створення власних ігор та програм
- Можливість запуску програм з SD-карти

.. warning::

   Слід зауважити, що Лілка не позиціонується як ігрова консоль.

   Вона - це :term:`DIY`-набір, який буде дуже легко зібрати навіть недосвідченим початківцям, і її мета - дати вам дешевий набір заліза, з яким можна погратись,
   а також готову бібліотеку взаємодії з дисплеєм, SD-картою, кнопками, звуком, батареєю та іншими компонентами.

   Звісно ж, ви зможете грати на ній в ігри! Але ігри - це не основне її призначення.

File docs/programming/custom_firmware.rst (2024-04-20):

Створення власної прошивки
==========================

1. Відкрийте Visual Studio Code, перейдіть на вкладку ``PlatformIO`` та виберіть ``Create New Project``.

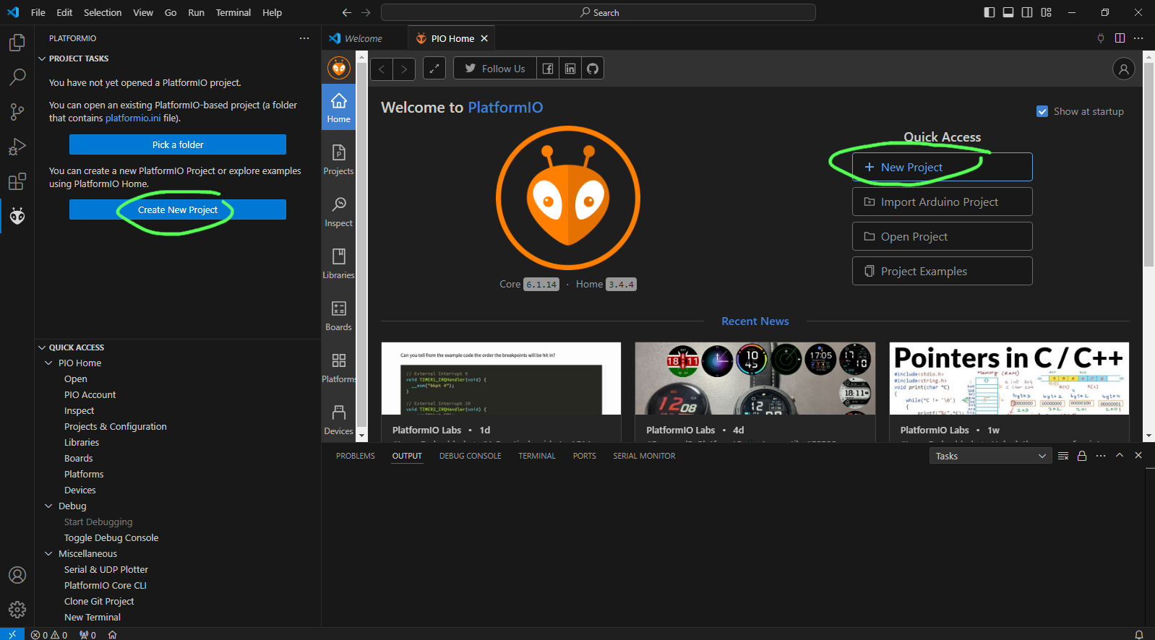
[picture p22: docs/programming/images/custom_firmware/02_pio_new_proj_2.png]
   

   У вікні, що відкриється, натисніть на кнопку ``New Project``.

2. Придумайте назву свого проєкту - наприклад, ``first_project``.

   У переліку boards оберіть ``Lilka v2 (Anderson & friends)``.

   У переліку frameworks оберіть ``Arduino``.

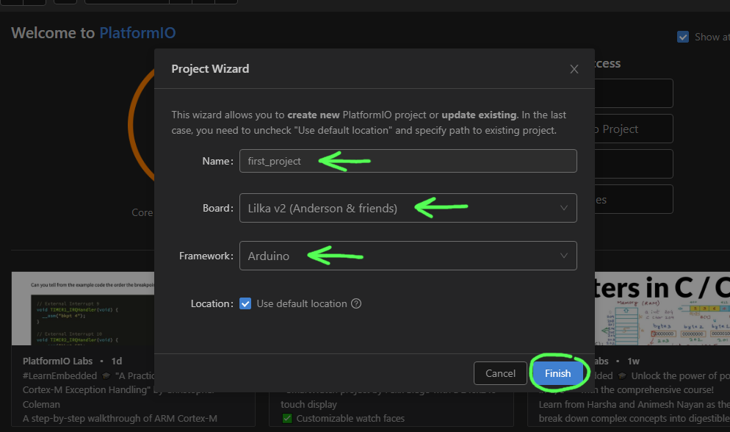
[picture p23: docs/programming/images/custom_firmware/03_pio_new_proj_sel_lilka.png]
   

   Після цього натисніть на кнопку ``Finish``.

   .. note::

      Якщо ви не бачите в переліку ``Lilka v2 (Anderson & friends)`` або у вас виникає помилка при створенні проєкту, вам потрібно оновити пакети PlatformIO.

      Для цього виконайте команду ``pio pkg update -g -p espressif32`` в терміналі Visual Studio Code.

      Щоб відкрити термінал, в панелі ``Quick Access`` виберіть ``Miscellaneous`` і тоді натисніть на ``PlatformIO Core CLI``.
      Консоль відкриється внизу вікна Visual Studio Code.

      Після цього вам слід перезапустити Visual Studio Code.

3. Ваш новий проєкт відкриється у новому вікні Visual Studio Code, і ви побачите файл ``platformio.ini``.

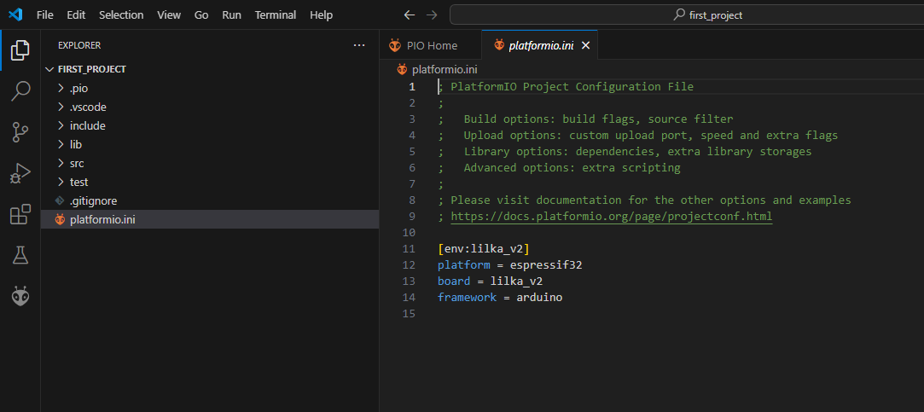
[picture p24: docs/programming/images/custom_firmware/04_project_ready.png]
   

   Це - конфігураційний файл проєкту, в якому вказані всі налаштування проєкту: платформа, фреймворк, бібліотеки тощо.

   Ми можете редагувати його вручну, а можете використовувати графічний інтерфейс PlatformIO.

4. Давайте додамо до проєкту бібліотеку :ref:`lilka <lilka-lib>`. Для цього відкрийте вкладку ``PlatformIO`` та в панелі ``Quick Access`` виберіть ``Libraries``.

   Після цього введіть у поле пошуку ``lilka``:

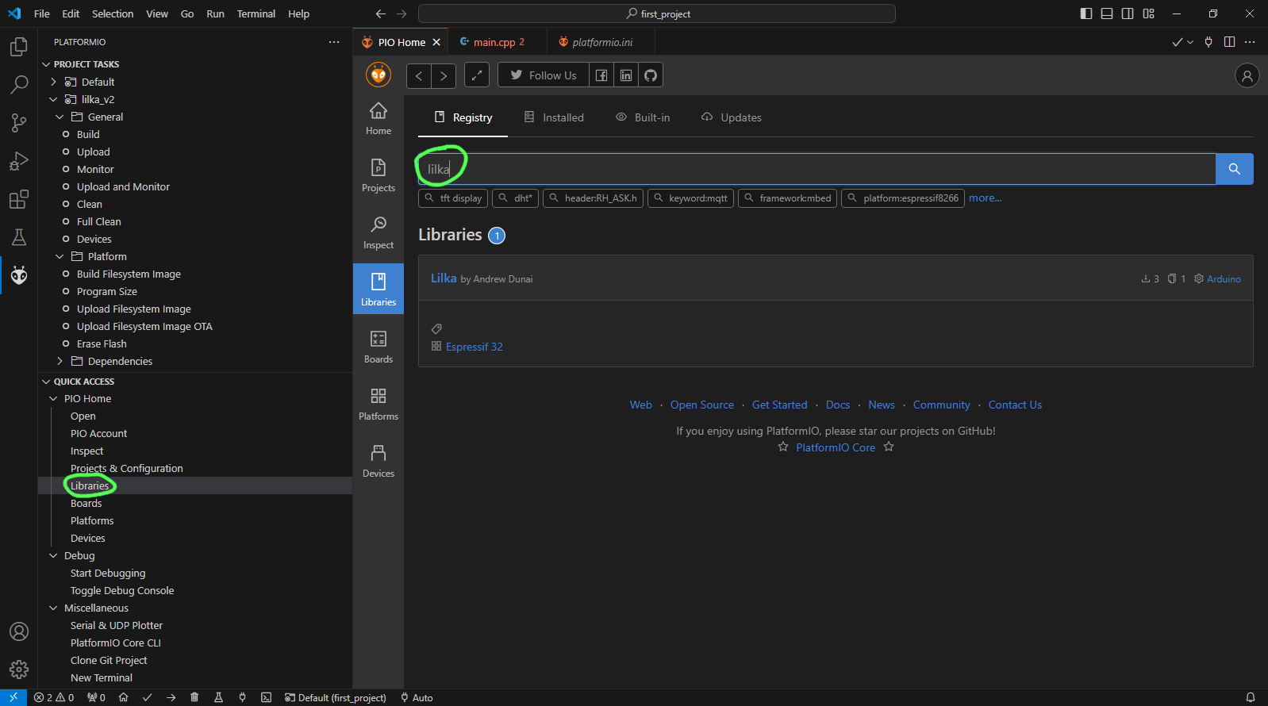
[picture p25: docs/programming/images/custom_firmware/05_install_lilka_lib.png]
   

   Тепер натисніть на кнопку ``Add to Project``.

   

   Після завершення завантаження бібліотеки ви побачите, що вона з'явилась у полі ``lib_deps`` файлу ``platformio.ini``.

   

   Це поле вказує на те, які бібліотеки використовуються у проєкті. PlatformIO автоматично завантажує та встановлює всі бібліотеки, вказані у цьому полі, а також їх залежності.

   Встановлення бібліотеки ``lilka`` автоматично встановлює різні бібліотеки для роботи з Лілкою, наприклад ``Arduino-GFX``, яка використовується для роботи з дисплеєм Лілки.

5. Напишемо простий код нашої прошивки. Відкрийте файл ``src/main.cpp`` та напишіть наступний код:

   .. code-block:: cpp

      #include <lilka.h>

      void setup() {
        // Ця функція виконається один раз при увімкненні

        // Ініціалізуємо дисплей, карту пам'яті, звук, кнопки і все на світі
        lilka::begin();

        // Заповнюємо екран білим кольором
        lilka::display.fillScreen(lilka::colors::White);
      }

      void loop() {
        // Ця функція буде виконуватись по колу

        // Читаємо стан кнопок
        lilka::State state = lilka::controller.getState();

        if (state.a.justPressed) {
          // Кнопка A щойно була натиснена
          lilka::display.fillScreen(lilka::colors::Red);
          lilka::buzzer.play(lilka::NOTE_C4);
        } else if (state.a.justReleased) {
          // Кнопка A щойно буда відпущена
          lilka::display.fillScreen(lilka::colors::Green);
          lilka::buzzer.stop();
        }  
      }

   Це - проста програма, яка при натисканні на кнопку A змінює колір екрану на червоний та відтворює звук, а при відпусканні - заповнює екран зеленим кольором та зупиняє звук.

   

6. Тепер ми можемо скомпілювати нашу прошивку та завантажити її в Лілку.

   Для цього під'єднайте Лілку до комп'ютера за допомогою USB-кабеля, відкрийте вкладку ``PlatformIO`` та натисніть на дію ``Upload``.

   

   Після завершення компіляції та завантаження прошивки ви побачите, як Лілка виконує вашу програму. Спробуйте натиснути та відпустити кнопку A та переконайтеся, що все працює!

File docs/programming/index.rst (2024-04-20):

.. _programming:

:octicon:`book` Програмування
=============================

Отже, ви зібрали Лілку!

В цьому розділі ви знайдете інструкції, як налаштувати робоче середовище, як її запрограмувати, як розширити функціонал, а також як розробляти власні розширення.

.. toctree::
    :maxdepth: 1

    environment
    keira
    custom_firmware
    extension

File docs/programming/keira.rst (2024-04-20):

Keira OS
========

Ми написали для Лілки власну прошивку, яка називається **"Keira OS"** (**Операційна Система "Кіра"**) і включає в себе основні функції для демонстрації можливостей пристрою.

**Keira** - це операційна система, що базується на проєкті FreeRTOS. Вона підтримує мультизадачність, мережу, запуск Lua-програм та сторонніх прошивок з SD-карти та багато іншого.

Більше інформації про **Keira OS** - на сторінці :ref:`keira-firmware-features`.

Якщо вам кортить якнайшвидше спробувати **Keira OS**, переходьте на сторінку :ref:`keira-flashing`.

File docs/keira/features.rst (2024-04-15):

.. _keira-firmware-features:

Можливості
==========

.. contents::
   :local:
   :depth: 2

.. _sd-card-feature:

Запуск прошивок з SD-картки
---------------------------

Keira підтримує запуск другорядних прошивок з SD-картки. Такі файли мають розширення ``.bin``. Це дозволяє вам скомпілювати (або завантажити з інтернету) нестандартну прошивку, скопіювати її на SD-картку, і запустити її на Лілці.

Це має деякі великі переваги:

- Ви можете використовувати більше пам'яті, ніж доступно в Keira.
- Вам не потрібно щоразу перепрошивати Лілку, щоб випробувати другорядні прошивки: просто скопіюйте їх на SD-картку.
- Ви можете ділитися своїми скомпільованими прошивками (у вигляді ``.bin``-файлів) з іншими користувачами Лілки, без необхідності відправляти їм весь код вашої власної прошивки.

Найяскравіший приклад використання цієї функції - запуск Doom. Достатньо скопіювати на SD-карту файли ``doom.bin`` і ``doom.wad`` (або ``doom1.wad``), і ви зможете грати в Doom!

.. note:: Щоб отримати ``doom.bin``, вам потрібно скомпілювати прошивку, що знаходиться в папці ``firmware/doom``, і тоді скопіювати файл ``doom.bin`` на SD-картку.

.. note::

    Щоб отримати ``doom.wad``, ви можете завантажити безкоштовну shareware-версію Doom `за цим посиланням <https://distro.ibiblio.org/slitaz/sources/packages/d/doom1.wad>`_,
    або ж мати повну ліцензійну копію Doom і витягти з неї файл ``doom.wad``.

Тепер ви можете вставити SD-картку в Лілку і вибрати ``doom.bin`` у браузері SD-картки. Лілка перезавантажиться, і ви зможете зіграти в Doom!

Після перезавантаження Лілки ви повернетеся до Keira.

.. _nes-emulator-feature:

Запуск ігор NES з SD-картки
---------------------------

Keira має вбудовану підтримку запуску ігор `NES <https://uk.wikipedia.org/wiki/Nintendo_Entertainment_System>`_ з SD-картки. Це означає, що ви можете скопіювати файли ігор NES (`.rom` або `.nes`) на SD-картку, і грати в них на Лілці.

Для емуляції NES Лілка використовує емулятор `Nofrendo <https://github.com/moononournation/arduino-nofrendo>`_. Він може мати деякі обмеження, але, наприклад, Super Mario Bros працює бездоганно.

.. _lua-scripting-feature:

Запуск Lua-скриптів з SD-картки
-------------------------------

Keira має вбудовану підтримку запуску `Lua <https://uk.wikipedia.org/wiki/Lua>`_-скриптів з SD-картки. Це означає, що ви можете скопіювати файли Lua (`.lua`) на SD-картку, і виконувати їх на Лілці.

Для виконання Lua-скриптів Лілка використовує вбудований інтерпретатор Lua, який базується на `Lua 5.4.6 <https://www.lua.org/manual/5.4/manual.html>`_.

Написати власний Lua-скрипт для Лілки дуже просто. Для цього вам потрібно знати основи Lua, а також використовувати Lua API  Лілки. Детальніше про це - в розділі :ref:`lua-intro`.

Детальніше про те, як писати Lua-скрипти для Лілки, ви можете прочитати в розділі :ref:`lua-intro`.

Запуск mJS-скриптів з SD-картки
-------------------------------

mJS - це `мінімалістичний двигун JavaScript <https://github.com/cesanta/mjs>`_, який використовується в Лілці для виконання скриптів.
Keira має вбудовану підтримку запуску mJS-скриптів з SD-картки. Це означає, що ви можете скопіювати файли, написані діалектом mJS (з розширенням ``.js``) на SD-картку і виконувати їх на Лілці.

Я не впевнений, наскільки корисною буде ця функція, і ми рекомендуємо використовувати для цього Lua, яка має значно більше можливостей, ніж mJS.
Проте така опція є і ви можете спробувати її, якщо вам цікаво.

.. warning::

    mJS - це діалект JavaScript, який має свої особливості. Наприклад, він не підтримує класи і має свої власні функції для роботи з рядками, масивами, об'єктами тощо.
    Тому, якщо ви вирішили використовувати mJS, будьте готові до того, що:

    * **Вам доведеться вивчати новий діалект JavaScript**.
    * **Ви не зможете використовувати майже жодну з бібліотек, які ви використовуєте в звичайному JavaScript**.
    * **Ми не володіємо жодною інформацією про стабільність проєкту mJS загалом**.

Додати mJS до Лілки було дуже просто і це дозволяє нам хизуватися тим, що "для Лілки можна писати код на JavaScript!" :)

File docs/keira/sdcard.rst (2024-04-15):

.. _sdcard:

Карта microSD
=============

Keira підтримує карти пам'яті microSD для запуску програм та зберігання даних.

Перш ніж використовувати карту пам'яті, вона повинна бути відформатована в файлову систему FAT32.
Це можна зробити за допомогою програми форматування в операційній системі Windows або за допомогою команди ``mkfs.vfat`` в операційній системі GNU/Linux.

Форматування карти пам'яті в GNU/Linux
--------------------------------------

.. code-block:: bash

    # Визначаємо пристрій, який відповідає карті пам'яті (наприклад, /dev/sdX)
    lsblk
    # Створюємо нову таблицю розділів MBR та один розділ FAT32, який займає всю карту пам'яті
    parted /dev/sdX --script -- mklabel msdos mkpart primary fat32 1MiB 100%
    # Форматуємо розділ FAT32 з міткою LILKA
    mkfs.vfat -F 32 -n LILKA /dev/sdX1

Форматування карти пам'яті в Windows
------------------------------------

1. Підключіть карту пам'яті до комп'ютера.

2. Відкрийте провідник Windows та знайдіть карту пам'яті в списку пристроїв.

3. Клацніть правою кнопкою миші на карті пам'яті та виберіть "Форматувати".

4. Виберіть файлову систему FAT32 та натисніть кнопку "Почати".

5. Після завершення форматування виберіть "Закрити".

Наповнення карти пам'яті демонстраційними програмами
----------------------------------------------------

Перш ніж використовувати карту пам'яті з Keira, ви можете записати на неї демонстраційні програми.

Вони знаходяться в директорії ``firmware/keira/sdcard`` в репозиторії проєкту на GitHub.

Підключіть карту пам'яті до комп'ютера та скопіюйте файли з директорії ``firmware/keira/sdcard`` на карту пам'яті. Після цього відключіть карту пам'яті від комп'ютера та вставте її в Лілку.

Коли Лілка запуститься, виберіть пункт "Браузер SD-карти" в головному меню і спробуйте запустити одну з Lua-програм! (Вони мають розширення ``.lua`` і синю іконку.

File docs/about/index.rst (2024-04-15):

:octicon:`package` Про проєкт
=============================

.. include:: what_is_lilka.rst

.. .. toctree::
..     :maxdepth: 2
..
..     what_is_lilka

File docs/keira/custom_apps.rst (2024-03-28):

Написання програм на C++
========================

.. contents:: Зміст
    :local:

Що таке програма в Keira?
-------------------------

Keira написана на C++, і вона містить ряд вбудованих програм. Програма в Keira - це клас, який наслідує клас :cpp:class:`App` та визначає метод :cpp:func:`App::run`. Цей метод викликається при запуску програми.

Всі програми є вбудованими, тобто вони мають бути частиною Keira. Це означає, що ви не можете додати свою програму до Keira, якщо не зміните код Keira і не перепрошиєте Лілку новим кодом.

Ви можете використовувати будь-які функції з :ref:`бібліотеки Lilka <lilka-lib>`.

.. note::

    *Чи можу я написати свою програму на C++ окремо від Keira, якось скомпілювати її і запустити в Keira з SD-карти?*

    Ні. Динамічне завантаження програм у вбудованих системах - це дуже складний процес. Keira наразі не підтримує цю функцію. Але це може змінитись в майбутньому.

    Якщо ви хочете писати програми, не перепрошиваючи Лілку, ми радимо спробувати вам Lua: :ref:`lua-intro`.

Клас :cpp:class:`App`
---------------------

Для створення власної програми вам потрібно наслідувати клас :cpp:class:`App` та визначити метод :cpp:func:`App::run`. Цей метод буде викликатися при запуску програми.

Ось перелік важливих методів та властивостей класу :cpp:class:`App`:

.. doxygenclass:: App
    :members:
    :protected-members:
    :private-members:

Приклад програми
----------------

Давайте створимо просту програму, яка буде малювати круг на екрані, який можна переміщувати за допомогою кнопок.

Для цього створіть два нові файли в директорії ``firmware/keira/src/apps``:

.. code-block:: cpp
    :caption: myapp.h

    #include <lilka.h>
    #include "app.h"

    class MyApp : public App {
    public:
        MyApp();
    private:
        void run() override;
    };

.. code-block:: cpp
    :caption: myapp.cpp

    #include "myapp.h"

    MyApp::MyApp() : App("Моя програма") {
    }

    void MyApp::run() {
        int16_t x = canvas->width() / 2;
        int16_t y = canvas->height() / 2;
        while (true) {
            // читаємо стан кнопок
            lilka::State state = lilka::controller.getState();

            if (state.up.pressed) {
                y--;
            } else if (state.down.pressed) {
                y++;
            }
            if (state.left.pressed) {
                x--;
            } else if (state.right.pressed) {
                x++;
            }
            if (state.a.pressed) {
                // Завершуємо програму
                return;
            }

            // заповнюємо екран чорним кольором
            canvas->fillScreen(canvas->color565(0, 0, 0));
            // малюємо білий круг
            canvas->fillCircle(x, y, 10, canvas->color565(255, 255, 255));

            // повідомляємо Keira, що буфер змінився і його потрібно перемалювати
            queueDraw();
        }
    }

Давайте розберемося з кодом.

1. Ми створили клас ``MyApp``, який наслідує клас ``App``.

    ``App`` містить в собі віртуальний метод ``run``, який викликається при запуску програми.

    Також ``App`` автоматично створює об'єкт ``canvas``, який представляє собою буфер для малювання. Ви повинні малювати саме на ньому, а не на екрані. Детальніше про це - згодом.

2. Весь код нашої програми знаходиться в методі ``run``. Він автоматично викликається при запуску програми.

    Програма виконується в циклі ``while (true)``. Це означає, що вона буде виконуватися постійно, поки ви не викличете ``return``.

3. Ми читаємо стан кнопок за допомогою ``lilka::controller.getState()``. Це повертає об'єкт ``lilka::State``, який містить в собі стан кожної кнопки.

    Наприклад, ``state.up.pressed`` - це ``true``, якщо кнопка ``up`` натиснута.

4. Ми щоразу заповнюємо екран чорним кольором, малюємо білий круг, а потім викликаємо ``queueDraw()``.

    Цей метод повідомляє Keira, що буфер змінився і його потрібно перемалювати.

    .. note::

        *Чому ми не малюємо безпосередньо на екрані, і чому щоразу заповнюємо його чорним кольором? І що таке** ``queueDraw()``?

        Це все пов'язано з тим, що Keira - це мультизадачна операційна система, і різні програми можуть намагатись одночасно малювати щось на екрані.

        Щоб уникнути конфліктів, Keira використовує `подвійну буферизацію <https://uk.wikipedia.org/wiki/%D0%91%D0%B0%D0%B3%D0%B0%D1%82%D0%BE%D0%BA%D1%80%D0%B0%D1%82%D0%BD%D0%B0_%D0%B1%D1%83%D1%84%D0%B5%D1%80%D0%B8%D0%B7%D0%B0%D1%86%D1%96%D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'%D1%8E%D1%82%D0%B5%D1%80%D0%BD%D1%96%D0%B9_%D0%B3%D1%80%D0%B0%D1%84%D1%96%D1%86%D1%96>`_.
        Це означає, що кожна програма має два власні буфери: один ("передній") для малювання, а інший ("задній") - для відображення на екрані.

        - ``canvas`` - це передній буфер. Саме на ньому ваша програма малює все, що ви хочете побачити на екрані.
        - ``backCanvas`` - це задній буфер. Вам не потрібно ним керувати.

        Коли ви викликаєте метод ``queueDraw()``, Keira міняє місцями передній і задній буфери і через деякий час починає малювати задній буфер на екрані в фоновому режимі.
        Таким чином ваша програма ніколи не малює безпосередньо на екрані: це робить Keira, а конкретніше - клас ``AppManager``.

        ``canvas`` завжди вказує на передній буфер, тому ви повинні малювати саме на ньому.
        Але оскільки ці буфери постійно міняються місцями, ваша програма не повинна робити жодних припущень про те, що було намальовано в попередній ітерації.

        Тому після кожного виклику ``queueDraw()`` кожна програма повинна знову малювати все, що ви хочете побачити на екрані,
        оскільки ``canvas`` буде містити "сміття", а не те, що ви малювали в попередній ітерації,
        і завжди відставатиме на одну ітерацію від того, що відображається на екрані.

        Це дає можливість не лише здійснювати конкурентне малювання на екрані з декількох програм, але й використовувати для цього обидва ядра процесора:
        одне ядро виконує вашу програму, а інше - перемальовує екран.
        Це збільшує FPS (кількість кадрів в секунду) і дозволяє досягнути максимальної утилізації процесора.

        Майте на увазі, що виклик ``queueDraw()`` може заблокувати вашу програму на деякий час.
        Це ставатиметься в ситуаціях, коли Кіра ще не завершила малювати на екрані попередній буфер, а ви вже викликаєте ``queueDraw()`` знову.
        Це - не проблема, але варто про це пам'ятати.

        В середньому, малювання займає близько 1/30 секунди. Це означає, що ви можете викликати ``queueDraw()`` близько 30 разів в секунду без блокування вашої програми.

Реєстрація програми в меню програм
----------------------------------

Основна програма, що запускається при завантаженні Кіри, називається ``Launcher``. Вона відповідає за відображення меню програм, налаштувань, інформації, а такоє запуск програм.

Щоб програма з'явилася в меню програм, вам потрібно зареєструвати її в одному з меню ``Launcher``. Найпростіший спосіб - це додати вашу програму в меню додатків.
Для цього знайдіть наступний код у файлі ``launcher.cpp`` та додайте вашу програму в список програм:

.. code-block:: cpp
    :linenos:
    :emphasize-lines: 1, 27
    :caption: launcher.cpp

    #include "myapp.h"  // <--- підключаємо вашу програму

    // ...

    ITEM_LIST app_items = {
        ITEM_SUBMENU(
            "Демо",
            {
                ITEM_APP("Лінії", DemoLines),
                ITEM_APP("Диск", DiskApp),
                ITEM_APP("Перетворення", TransformApp),
                ITEM_APP("М'ячик", BallApp),
                ITEM_APP("Куб", CubeApp),
                ITEM_APP("Епілепсія", EpilepsyApp),
            }
        ),
        ITEM_SUBMENU(
            "Тести",
            {
                ITEM_APP("Клавіатура", KeyboardApp),
                ITEM_APP("Тест SPI", UserSPIApp),
                ITEM_APP("I2C-сканер", ScanI2CApp),
            },
        ),
        ITEM_APP("Летріс", LetrisApp),
        ITEM_APP("Тамагочі", TamagotchiApp),
        ITEM_APP("Моя програма", MyApp),  // <--- додаємо вашу програму
    };

Після цього перепрошийте Лілку, і ваша програма з'явиться в меню програм.

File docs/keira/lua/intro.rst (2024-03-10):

.. _lua-intro:

Написання програм на Lua
========================

Keira має вбудовану віртуальну машину мови програмування Lua. Це дозволяє писати та виконувати програми на Lua прямо з SD-картки, без необхідності компіляції чи перепрошивання Лілки.

.. warning:: Якщо ви не знайомі з мовою Lua, рекомендуємо прочитати туторіал з Lua перед тим, як продовжувати: https://www.lua.org/pil/1.html

.. contents::
    :local:
    :depth: 1

.. _lua-example:

Приклад програми
----------------

Оскільки Lua сама по собі - це універсальна мова програмування, вона не має вбудованих функцій для роботи з дисплеєм, звуком тощо.
Тому для роботи з цими пристроями на Лілці в Keira доступні спеціальні вбудовані модулі, які надають доступ до функцій пристроїв.

Модулі завантажуються автоматично - не потрібно писати жодних ``require(...)``. Ось приклад простої програми на Lua, яка виводить текст "Hello, world!" на екран:

.. code-block:: lua
    :linenos:

    function lilka::update()
        if controller.get_state().a.just_pressed then
            -- Завершуємо програму при натисканні кнопки "A"
            util.exit()
        end
    end

    function lilka::draw()
        -- Заповнюємо екран чорним кольором:
        display.fill_screen(display.color565(0, 0, 0))

        -- Виводимо текст "Hello, world!" на екран:
        display.set_cursor(0, 32)
        display.print("Hello, world!")
    end

Ви можете зберегти цей код у файл з розширенням ``.lua`` на SD-картці, а потім виконати його, обравши його в браузері SD-картки.

Повний перелік доступних модулів та їх функцій можна знайти в розділі :doc:`reference/index`.

.. _lua-games:

``init``, ``update``, ``draw``
------------------------------

В іграх важливо, щоб гра була плавною та виконувалася з певною стабільною кількістю кадрів на секунду.

Імовірно, ви знайомі з функцією ``delay(...)`` з фреймворка Arduino, яка затримує виконання програми на певну кількість мілісекунд.
Це зручно для простих програм, що не використовують дисплей, але для ігор це не підходить, оскільки такі функції заблокують виконання програми на певну кількість мілісекунд,
незалежно від швидкості виконання програми, а також не дозволяють вам взаємодіяти з грою під час затримки.

Для цього існує можливість визначити функції :lua:func:`lilka.init()`, :lua:func:`lilka.update()` і :lua:func:`lilka.draw()`.
Якщо при запуску вашої програми Keira знайде цю функції, вона буде викликати їх автоматично.

* :lua:func:`lilka.init()` викликається один раз при запуску програми.

* :lua:func:`lilka.update()` викликається 30 разів на секунду, тому ви можете використовувати його для оновлення стану гри та обробки введення користувача.

* :lua:func:`lilka.draw()` викликається після :lua:func:`lilka.update()` та використовується для малювання графіки на екрані.

.. warning::
    Програма на Lua буде виконуватись доти, доки не буде викликано функцію :lua:func:`util.exit()`. Інакше для виходу вам доведеться перезавантажити Лілку.

.. warning::
    Не варто використовувати :lua:func:`util.sleep` всередині ваших функцій :lua:func:`lilka.update()` та :lua:func:`lilka.draw()`, оскільки це призведе до заповільнення виконання програми.

    Намагайтесь писати код, який не блокує виконання програми, а використовує функцію :lua:func:`lilka.update()` для оновлення стану гри та обробки введення користувача.

:lua:func:`lilka.update()` також отримує необов'язковий аргумент ``delta``, який вказує (в секундах), скільки часу пройшло з початку її попереднього виклику.
Це дозволяє вам робити рухи та анімації, які будуть відбуватись з однаковою швидкістю незалежно від швидкості виконання програми.

За ідеальних обставин, ``delta`` буде дорівнювати 1/30, або приблизно 0.0333 секунди, але якщо код гри дуже складний і його виконання займає більше часу, ніж 1/30 мекунди, то значення ``delta`` буде більшим.
Ваша програма може використовувати ``delta`` для того, щоб, наприклад, рухати об'єкти на екрані залежно від часу, а не від кількості кадрів на секунду.

Ці три функції повинні бути визначені у головному файлі програми, наприклад:

.. code-block:: lua
    :linenos:

    local ball_x
    local ball_y

    -- Завантажуємо зображення м'яча, яке знаходиться в корені SD-картки:
    local ball = resources.load_image("ball.bmp", display.color565(255, 255, 255))

    function lilka.init()
        -- Ця функція викликається один раз при запуску програми.
        -- Цей код можна було б виконати в глобальному контексті (поза цією функцією), як ми це зробили з "ball",
        -- але ініціалізація гри буде очевиднішою, якщо вона відбувається тут.
        ball_x = display.width / 2
        ball_y = display.height / 2
    end

    function lilka.update(delta)
        local dir_x = 0
        local dir_y = 0

        -- Обробляємо введення користувача:
        local state = controller.get_state()
        if state.up.pressed then
            dir_y = -1
        elseif state.down.pressed then
            dir_y = 1
        end
        if state.left.pressed then
            dir_x = -1
        elseif state.right.pressed then
            dir_x = 1
        end
        if state.a.pressed then
            -- Вихід з програми:
            util.exit()
        end

        -- Переміщуємо м'яч зі швидкістю 50 пікселів на секунду
        ball_x = ball_x + dir_x * 50 * delta
        ball_y = ball_y + dir_y * 50 * delta
    end

    function lilka.draw()
        -- Малюємо графіку:
        display.fill_screen(display.color565(0, 0, 0))
        display.draw_image(ball, ball_x, ball_y)

        -- Після виконання цієї функції Лілка автоматично відобразить все, що ми намалювали на екрані.
        -- Не потрібно викликати display.queue_draw() чи щось подібне.
    end

    -- Інші функції:
    -- ...

Цей код створить просту програму, в якій ви можете керувати м'ячем за допомогою стрілок на контролері.
Кожен кадр гри м'яч переміщується на певну відстань залежно від натиснутих кнопок, а потім малюється на екрані.

Завдяки аргументу ``delta`` м'яч завжди рухатиметься з однаковою швидкістю незалежно від того, як швидко виконується програма - чи це 30 кадрів на секунду, чи 10, чи 1000.

.. warning::

    Ваш код всередині функції ``lilka.draw()`` не повинен робити жодних припущень щодо того, що вже було намальовано раніше. Кожен кадр гри потрібно малювати повністю.

    Це потрібно тому, що Keira використовує
    `подвійну буферизацію <https://uk.wikipedia.org/wiki/%D0%91%D0%B0%D0%B3%D0%B0%D1%82%D0%BE%D0%BA%D1%80%D0%B0%D1%82%D0%BD%D0%B0_%D0%B1%D1%83%D1%84%D0%B5%D1%80%D0%B8%D0%B7%D0%B0%D1%86%D1%96%D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'%D1%8E%D1%82%D0%B5%D1%80%D0%BD%D1%96%D0%B9_%D0%B3%D1%80%D0%B0%D1%84%D1%96%D1%86%D1%96>`_
    екрану, тобто ваша гра малює на **передньому буфері**, а в цей час Keira відображає **задній буфер** на екрані.

    Тому радимо починати кожен кадр гри з виклику ``display.fill_screen(display.color565(0, 0, 0))``, щоб очистити передній буфер перед малюванням нового кадру,
    оскільки він може бути забруднений попереднім кадром.

.. _lua-fast-testing:

Швидке тестування програм
-------------------------

Звісно, ви можете зберегти вашу програму на SD-картці, а потім вибрати її в браузері SD-картки, але це може бути доволі незручно, особливо якщо ви працюєте над програмою, яка вимагає багато ітерацій.
Щоразу, коли ви зберігаєте програму на SD-картці, ви повинні виймати її з Лілки, вставляти в комп'ютер, зберігати файл, виймати з комп'ютера, вставляти в Лілку, вибирати файл в браузері SD-картки, запускати програму, перевіряти, 
в͟и̛п͜р͢а̵в̀л͟я̕т̴и͜ ̢п͟о̨м͘и̴л͢к͡и́,͝ ̕з́б͠е͞р͠і͞г͏а̢т͞и̧ ͘з̶н̛о̶в͢у̢,͡ ͡О НІ! Це - нестерпно і в нас немає часу на це!

Саме тому Keira має функцію, яка називається **Live Lua**. Вона дозволяє вам запускати Lua-код на Лілці через USB-кабель прямо з вашого комп'ютера, без необхідності зберігати його на SD-картці.

.. warning::

    Якщо ваша Lua-програма завантажує додаткові ресурси з SD-картки - наприклад, зображення, звуки тощо - ви спершу повинні вручну скопіювати ці ресурси на SD-картку,
    оскільки **Live Lua** не підтримує завантаження файлів на SD-картку через USB-кабель. Вона надсилає на Лілку лише код Lua.

.. warning::

    **Live Lua** підтримує запуск програм, які складаються лише з одного файлу. Якщо ваша програма складається з декількох файлів, які завантажуються через ``require()``,
    вам потрібно спершу скопіювати всі модулі на SD-картку, а потім використовувати **Live Lua** для запуску головного файлу програми.

Щоб використовувати **Live Lua**, вам потрібно встановити розширення для :term:`Visual Studio Code`, яке називається `Serial Monitor <https://marketplace.visualstudio.com/items?itemName=ms-vscode.vscode-serial-monitor>`_:



Після цього підключіть Лілку до комп'ютера за допомогою USB-кабеля та перейдіть в меню "Розробка" -> "Live Lua". Лілка перейде в режим "Live Lua" та очікуватиме код Lua через USB-порт.

Далі створіть новий файл з розширенням ``.lua`` - наприклад, ``test.lua``. Напишіть в ньому якийсь код:

.. code-block:: lua
    :linenos:

    display.fill_screen(display.color565(255, 0, 0))
    display.set_cursor(50, 50)
    display.print('Привіт, Лілка!')
    display.queue_draw() -- Потрібно викликати цю функцію, щоб відобразити зміни на екрані, оскільки цей код знаходиться поза функцією lilka.draw
    util.sleep(1)

Тепер перейдіть на вкладку "Serial Monitor" у VS Code, оберіть COM-порт, на якому підключена Лілка, та натисніть "Start Monitoring":



Після цього натисніть правою кнопкою будь-де в коді на вкладці з вашим файлом ``test.lua`` та оберіть "Send to Serial Monitor" -> "Send Entire File":



Вжух - і код миттєво запуститься на Лілці! Якщо ви зробите зміни в коді, ви можете просто натиснути "Send to Serial Monitor" -> "Send Entire File" знову, і новий код запуститься на Лілці. Слід лише переконатись, що попередня версія вашої програми завершилася, перш ніж ви надсилати нову версію.

.. _lua-repl:

Інтерактивна консоль Lua (REPL)
-------------------------------

`REPL <https://uk.wikipedia.org/wiki/REPL>`_ означає "Read-Eval-Print Loop".
Це - інтерактивне середовище, яка дозволяє вам друкувати код на клавіатурі та виконувати його на Лілці прямо з вашого комп'ютера через USB-кабель, по одному рядку коду за раз.

Це зручно для тестування функцій, вивчення API, відлагодження тощо.

Для запуску Lua REPL вам потрібно відкрити на Лілці меню "Розробка" -> "Lua REPL". Лілка перейде в режим "Lua REPL" та очікуватиме команди через USB-порт.

Для цього відкрийте вкладку "Serial Monitor" у VS Code, оберіть COM-порт, на якому підключена Лілка, натисніть "Start Monitoring" і почніть вводити код Lua.
Після кожної команди тисніть Enter. Вона виконається на Лілці, і ви побачите результат в консолі Visual Studio Code.

Спробуйте ввести, наприклад, ось такий код:

.. code-block:: lua
    :linenos:

    print(3 + 4)

Після введення цього рядка ви маєте побачити в консолі результат виразу 3 + 4, тобто число 7.

Тепер спробуйте ввести цей код:

.. code-block:: lua
    :linenos:

    display.fill_screen(display.color565(255, 0, 0))

Після введення другого рядка та натиску на клавішу ``Enter``, екран Лілки має забарвитися червоним кольором.

Щоб вийти з режиму REPL, натисніть на Лілці кнопку ``A``.

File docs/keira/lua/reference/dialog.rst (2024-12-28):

``UIs``: Діалоги
--------------------

Функції для створення та управління діалогами.

Приклад:

.. code-block:: lua
    :linenos:
    -- Створення діалогу для введення тексту
    local keyboard_test = keyboardUI("Скажи моє ім'я") 
    keyboard_test:setValue("TEST")
    while true do      
        keyboard_test:draw()      
        keyboard_test:update()  
        if keyboard_test:isFinished() then
            break
        end
    end

    -- Створення сповіщення
    local alert_test = alertUI("Хто ти?", keyboard_test:getValue()) 
    alert_test:draw()      
    while true do      
        alert_test:update()     
        if alert_test:isFinished() then
            break
        end
    end

    alert_test:setTitle("НІ!!! Ти є:")
    alert_test:setMessage("НАЙКРАЩИЙ У СВІТІ")

    -- Створення діалогу з кнопками
    local alert_test = alertUI("Бажаєш пограти?", "[A]ТАК\n[B]НІ") 
    alert_test:addActivationButton("a")
    alert_test:addActivationButton("b")
    alert_test:draw()      
    while true do   
        alert_test:update()     
        if alert_test:isFinished() then
            break
        end
    end

    which_key = alert_test:getButton()

    if which_key == "a" then
        alert_test:setTitle("ГАРАЗД")
        alert_test:setMessage("ПОГРАЙМО")
    elseif which_key == "b" then
        alert_test:setTitle("Добре")
        alert_test:setMessage("...")
    end

    -- Створення діалогу прогресу
    local progress_test = progressUI("Ракета", "Запуск") 
    for i = 0, 100 do
        progress_test:setProgress(i)
        progress_test:draw()
    end
.. lua:autoclass:: keyboardUI
.. lua:autoclass:: alertUI
.. lua:autoclass:: progressUI

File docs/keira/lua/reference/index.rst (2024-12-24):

Lua API
=======

Документація всіх функцій, які доступні при :ref:`написанні програм для Лілки мовою Lua <lua-intro>`.

.. toctree::
    :maxdepth: 5

    lilka
    display
    transform
    controller
    resources
    math
    geometry
    gpio
    util
    buzzer
    sdcard
    state
    wifi
    serial
    http

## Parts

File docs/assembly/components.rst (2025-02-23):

Перелік деталей
===============

.. contents:: Зміст







.. raw:: html

    <script>
    function calculateTotal(el, colNumber) {
        var tbody = el.closest('tbody');
        var total = Array.prototype.slice.call(tbody.querySelectorAll('td:nth-child(' + colNumber + ')')).slice(0, -1).map(x => (parseFloat(x.innerText) || 0)).reduce((a, b) => a + b, 0);
        el.innerText = total;
    }
    </script>

.. _base:

Базовий комплект
----------------

.. list-table:: Базовий комплект
   :widths: 5 10 15 10 15 10 10 10 15 1
   :header-rows: 1

   * - К-сть
     - ID
     - Значення
     - Назва
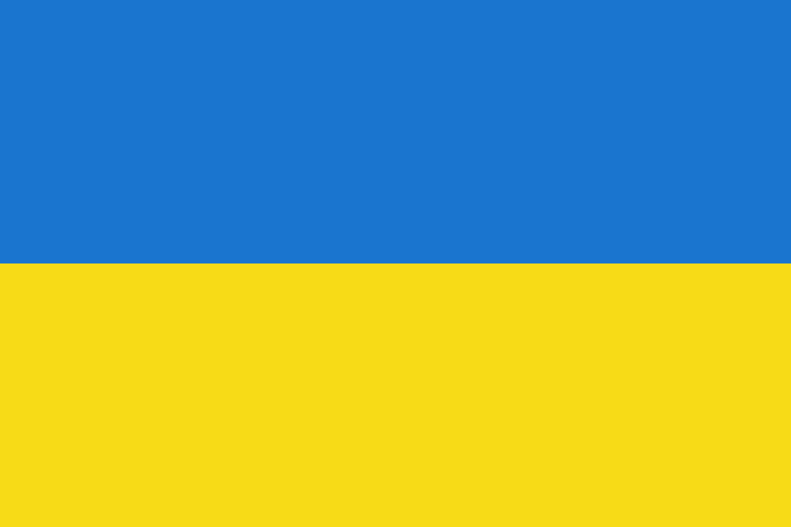
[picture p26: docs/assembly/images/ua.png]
Україна
     -  В Україні
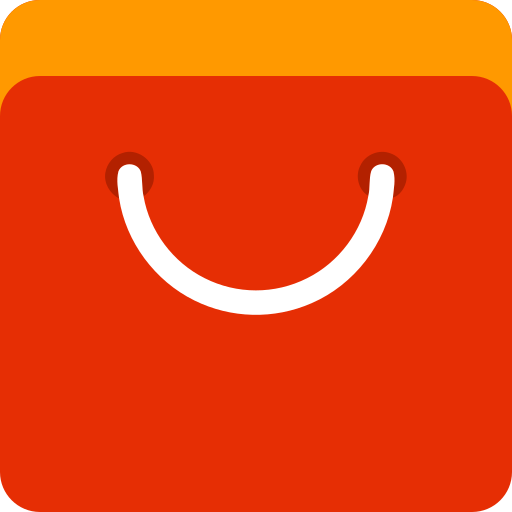
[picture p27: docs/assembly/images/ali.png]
AliExpress
     -  AliExpress
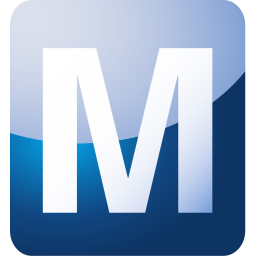
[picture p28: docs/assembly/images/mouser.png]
Mouser
     -  Mouser
     - Ціна в Україна
     - Примітка
     - Зображення

   * - 1
     - BZ1
     - Buzzer (2.54-7.62mm між контактами)
     - Passive Buzzer 
     - `mini-tech.com.ua <https://www.mini-tech.com.ua/ua/passivnyj-zummer>`__
     - `Посилання <https://www.aliexpress.com/item/1005005626151673.html>`__
     -
     - 5
     -
     - .. thumbnail:: ./images/parts/buzzer.jpg
          :group: base

   * - 1
     - C1
     - 1uF
     - 1uF Capacitor 
     - `m-teh.com.ua <https://m-teh.com.ua/kondensator-ct4-1uf-50v-x7r-10/>`__
     - `Посилання <https://www.aliexpress.com/item/1005004787479555.html>`__
     -
     - 9
     - Можна комплектувати `з цього набору <https://arduino.ua/prod2798-nabor-mnogosloinih-keramicheskih-kondensatorov-180-sht>`__
     - .. thumbnail:: ./images/parts/cap.jpg
          :group: base

   * - 2
     - C2, C3
     - 1uF-10uF
     - 1uF-10uF Capacitor 
     - `prom.ua <https://prom.ua/ua/p2221701868-kondensator-106-10uf.html/>`__
     - `Посилання <https://www.aliexpress.com/item/32973259342.html>`__
     -
     - 9
     -
     - .. thumbnail:: ./images/parts/cap.jpg
          :group: base

   * - 1
     - J1
     - ~
     - USB Type-C to DIP Adapter 
     - `arduino.ua <https://arduino.ua/prod2783-plata-perehodnik-usb-type-c-na-dip-2-54>`__
     - `Посилання <https://www.aliexpress.com/item/1005006023156245.html>`__
     -
     - 12
     -
     - .. thumbnail:: ./images/parts/usb.jpg
          :group: base

   * - 1
     - J2
     - Ext
     - Pin Header
     - `arduino.ua <https://arduino.ua/prod332-konnektor-40-pin-papa>`__
     - `Посилання <https://www.aliexpress.com/item/4000873858801.html>`__
     -
     - 5
     - Варіант з AliExpress містить пари тато+мама, тому задовольняє ``J2`` та ``U2J1``
     - .. thumbnail:: ./images/parts/header.jpg
          :group: base

   * - 1
     - J3
     - uSD
     - SD Card Interface Module
     - `prom.ua <https://prom.ua/ua/p2148810072-modul-plata-mini.html>`__
     - `Посилання <https://www.aliexpress.com/item/1005005302035188.html>`__
     -
     - 24
     -
     - .. thumbnail:: ./images/parts/sd.jpg
          :group: base

   * - 1
     - R1
     - 10K
     - 10K Resistor
     - `arduino.ua <https://arduino.ua/prod1970-rezistor-10-kom-5-shtyk>`__
     - `Посилання <https://www.aliexpress.com/item/1005001627995396.html>`__
     -
     - 3
     -
     - .. thumbnail:: ./images/parts/r10k.jpg
          :group: base

   * - 1
     - R2
     - 100K
     - 100K Resistor
     - `arduino.ua <https://arduino.ua/prod1549-rezistor-100-kom-5-shtyk>`__
     - `Посилання <https://www.aliexpress.com/item/1005001627995396.html>`__
     -
     - 2
     -
     - .. thumbnail:: ./images/parts/r100k.jpg
          :group: base

   * - 8
     - SW1-SW8
     - Arrows + A/B/C/D
     - Button Kit (12mm)
     - - `arduino.ua <https://arduino.ua/prod2506-komplekt-knopok-12mm-s-kolpachkom-5-cvetov>`__
       - `imrad.com.ua (кнопки) <https://imrad.com.ua/ua/kfc-012-7-3f-9>`__
       - `imrad.com.ua (ковпачки) <https://imrad.com.ua/ua/mec12pr-9>`__
     - `Посилання <https://www.aliexpress.com/item/1005005315348507.html>`__
     -
     - 36
     - В комплекті від arduino.ua лише 6 шт
     - .. thumbnail:: ./images/parts/12mm.jpg
          :group: base

   * - 3
     - SW9, SW10, SW12
     - Select/Start/Reset
     - SMD Tactile Button
     - `imrad.com.ua <https://imrad.com.ua/ua/kfc-a06-6-knopka-taktovaya-6x6x6-6>`__
     - `Посилання <https://www.aliexpress.com/item/32912263133.html>`__
     -
     - 6
     -
     - .. thumbnail:: ./images/parts/6mm.jpg
          :group: base

   * - 1
     - SW11
     - Power
     - Toggle Switch
     - `imrad.com.ua <https://imrad.com.ua/ua/msk-05g2-0-6>`__
     - `Посилання <https://www.aliexpress.com/item/4000030382277.html>`__
     -
     - 10
     - Кнопка має бути кутова
     - .. thumbnail:: ./images/parts/toggle.jpg
          :group: base

   * - 1
     - U1
     - ESP32-S3-WROOM-1-N16R8
     - Мікроконтролер
     - - `prom.ua <https://prom.ua/ua/p2051994816-esp32-dualcore-240mhz.html>`__
       - `rcscomponents.kiev.ua (проблеми з постачанням) <https://www.rcscomponents.kiev.ua/product/esp32-s3-wroom-1-n16r8_184448.html>`__
     - `Посилання <https://www.aliexpress.com/item/32901557709.html>`__
     - `Посилання <https://eu.mouser.com/ProductDetail/Espressif-Systems/ESP32-S3-WROOM-1-N16R8>`__
     - 200
     -
     - .. thumbnail:: ./images/parts/mcu.jpg
          :group: base

   * - 1
     - U2
     - 280x240 1.69\" TFT
     - 1.7\" IPS TFT Display (ST7789)
     - `arduino.ua <https://arduino.ua/prod6568-tft-displei-1-7-spi-240x280-rgb>`__
     - `Посилання <https://www.aliexpress.com/item/1005005933484586.html>`__
     -
     - 176
     -
     - .. thumbnail:: ./images/parts/display.jpg
          :group: base

   * - 1
     - U2J1
     - TFT_Socket
     - 40-pin Connector
     - `arduino.ua <https://arduino.ua/prod315-konnektor-40-pin-mama>`__
     - `Посилання <https://www.aliexpress.com/item/4000873858801.html>`__
     -
     - 7
     - Варіант з AliExpress містить пари тато+мама, тому задовольняє ``J2`` та ``U2J1``
     - .. thumbnail:: ./images/parts/socket.jpg
          :group: base

   * - 1
     - U3
     - TLV1117LV33DCYR (не плутати з TLV1117-33!)
     - TLV1117LV33DCYR Voltage Regulator
     - `kosmodrom.ua <https://kosmodrom.ua/ru/stabilizator-napryazheniya/tlv1117lv33dcyr.html>`__
     - `Посилання <https://www.aliexpress.com/item/1005006197085527.html>`__
     - `Посилання <https://eu.mouser.com/ProductDetail/Texas-Instruments/TLV1117LV33DCYR>`__
     - 26
     -
     - .. thumbnail:: ./images/parts/reg.jpg
          :group: base

   * - Разом
     -
     -
     -
     -
     -
     -
     - .. raw:: html

            <script>calculateTotal(document.querySelector('#total-base'), 8);
            </script>
     -
     -

.. _battery:

Компоненти для батареї
----------------------

.. list-table:: Компоненти для батареї
   :widths: 5 10 15 10 15 10 10 10 15 1
   :header-rows: 1

   * - К-сть
     - ID
     - Значення
     - Назва
     - Україна В Україні
     - AliExpress AliExpress
     - Mouser Mouser
     - Ціна в Україна
     - Примітка
     - Зображення

   * - 1
     - D1
     - 1N4001
     - 1N4001 Diode
     - `voron.ua <https://voron.ua/uk/catalog/029199--diod_1n4001_v_lente_mic_master_instrument_corporation_do41_do41>`__
     - `Посилання <https://www.aliexpress.com/item/1005005945645677.html>`__
     -
     - 6
     -
     - .. thumbnail:: ./images/parts/1n4001.jpg
          :group: battery

   * - 1
     - J4
     - TP4056
     - TP4056 Charging Module
     - `arduino.ua <https://arduino.ua/prod1486-zaryadnii-modyl-tp4056-micro-usb-s-fynkciei-zashhiti-akkymylyatora>`__
     - `Посилання <https://www.aliexpress.com/item/4001196732254.html>`__
     -
     - 16
     - Бажано брати варіант з micro USB (займає менше місця, а гніздо USB Type-C вже є на платі Лілки)
     - .. thumbnail:: ./images/parts/tp4056.jpg
          :group: battery

   * - 1
     - Q1
     - IRLML6401 (SOT-23)
     - IRLML6401 MOSFET
     - - `rcscomponents.kiev.ua <https://www.rcscomponents.kiev.ua/product/irlml6401trpbf_34344.html>`__
       - `imrad.com.ua <https://imrad.com.ua/ua/irlml6401trpbf-1>`__
     - `Посилання <https://www.aliexpress.com/item/1005003078624760.html>`__
     - `Посилання <https://eu.mouser.com/ProductDetail/Infineon-Technologies/IRLML6401TRPBF>`__
     - 4
     -
     - .. thumbnail:: ./images/parts/irlml6401.jpg
          :group: battery

   * - 1
     - R3
     - 100K
     - 100K Resistor
     - `arduino.ua <https://arduino.ua/prod1549-rezistor-100-kom-5-shtyk>`__
     - `Посилання <https://www.aliexpress.com/item/1005001627995396.html>`__
     -
     - 2
     -
     - .. thumbnail:: ./images/parts/r100k.jpg
          :group: battery

   * - 1
     - R4
     - 33K
     - 33K Resistor
     - `justas-electronics.com.ua <https://justas-electronics.com.ua/rss0125w-33kOm/>`__
     - `Посилання <https://www.aliexpress.com/item/1005001627995396.html>`__
     -
     - 2.1
     -
     - .. thumbnail:: ./images/parts/r33k.jpg
          :group: battery

   * - 1
     - \-
     - Bat
     - Будь-який (3.7V 1000 mAh +) LiPo на ваш розсуд  
     - `m-teh.com.ua <https://m-teh.com.ua/li-pol-akumuliator-603048p-1000-ma-hod-3.7v-z-plato%D1%96u-zakhystu/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>`__
     -
     -
     - 116
     - Рекомендуємо брати невелику батарею (6x30x48), щоб вона помістилась в корпус
     - .. thumbnail:: ./images/parts/lipo.jpg
          :group: battery

   * - Разом
     -
     -
     -
     -
     -
     -
     - .. raw:: html

            <script>calculateTotal(document.querySelector('#total-battery'), 8);
            </script>
     -
     -

.. _audio:

Компоненти для звуку
--------------------

.. list-table:: Компоненти для звуку
   :widths: 5 10 15 10 15 10 10 10 15 1
   :header-rows: 1

   * - К-сть
     - ID
     - Значення
     - Назва
     - Україна В Україні
     - AliExpress AliExpress
     - Mouser Mouser
     - Ціна в Україна
     - Примітка
     - Зображення

   * - 1
     - J5
     - MAX98357
     - Mono Audio Amplifier Module
     - `arduino.ua <https://arduino.ua/prod4112-modyl-aydioysilitelya-mono-3vt-klassa-d-na-max98357>`__
     - `Посилання <https://www.aliexpress.com/item/1005006711010527.html>`__
     - `Посилання <https://eu.mouser.com/ProductDetail/Adafruit/3006>`__
     - 92
     -
     - .. thumbnail:: ./images/parts/max98357.jpg
          :group: audio

   * - 1
     - \-
     - Speaker
     - 8 Ohm 1 W Speaker
     - `arduino.ua <https://arduino.ua/prod4280-dinamik-miniaturnii-8om-1-vt-30x20x4-2mm>`__
     - `Посилання <https://www.aliexpress.com/item/1005006461351585.html>`__
     -
     - 17
     - Або гніздо (див. наст. пункт), або будь-який інший динамік на ваш розсуд
     - .. thumbnail:: ./images/parts/speaker.jpg
          :group: audio

   * - 1
     - \-
     - Audio Jack (mono)
     - 3.5mm Audio Jack
     - `imrad.com.ua <https://imrad.com.ua/ua/pj3013d-144736>`__
     - `Посилання <https://www.aliexpress.com/item/1005006181883514.html>`__
     -
     - 8
     - Лише якщо ви вирішили використовувати навушники замість динаміка
     - .. thumbnail:: ./images/parts/jack.jpg
          :group: audio

   * - Разом
     -
     -
     -
     -
     -
     -
     - .. raw:: html

            <script>calculateTotal(document.querySelector('#total-audio'), 8);
            </script>
     -
     -

.. _other:

Не входять в жодний комплект
----------------------------

- MicroSD карта
- USB Type-C кабель

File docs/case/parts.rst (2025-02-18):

Моделі частин до корпусу
========================

**Моделі кастомних ковпачків на кнопки**

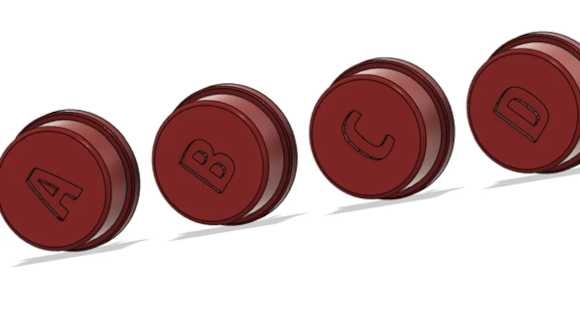
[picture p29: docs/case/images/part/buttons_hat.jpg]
Ковпачки

  
Посилання:
https://makerworld.com/en/models/1098567

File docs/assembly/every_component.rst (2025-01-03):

Що робить кожен компонент?
==========================

Якщо ви не знайомі з радіоелектронікою, вам, можливо, цікаво: навіщо потрібен кожен компонент Лілки?

Давайте розглянемо всі компоненти, з яких складається Лілка, і їхні основні функції.

Мікроконтролер ESP32-S3-WROOM-N16R8 (``U1``)
--------------------------------------------

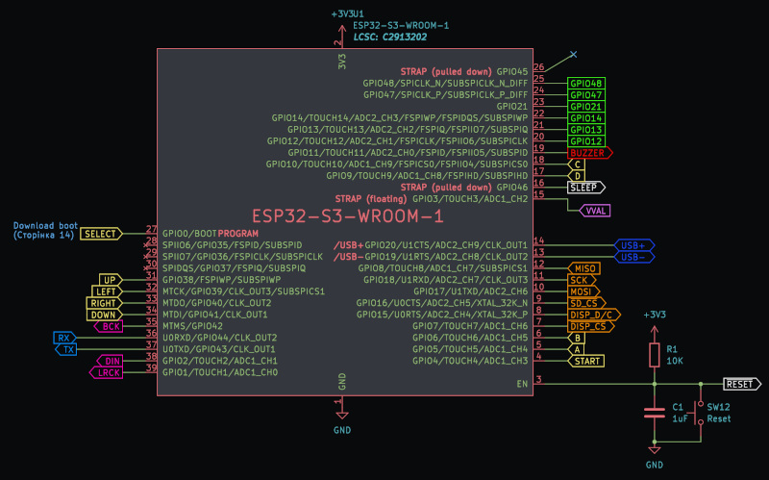
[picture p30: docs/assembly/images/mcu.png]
ESP32-S3-WROOM-N16R8


Мікроконтролер :ref:`ESP32-S3-WROOM-N16R8 <mcu>` від компанії Espressif - це мозок Лілки.

Він відповідає за управління всіма іншими компонентами, зчитування даних з датчиків, керування виводами, роботу з Wi-Fi і Bluetooth, і багато іншого.

Саме він місить флеш-пам'ять, в яку записується прошивка Лілки, і вбудовану пам'ять RAM.

Детальніше про мікроконтролер можна прочитати тут: :ref:`mcu`.

Конденсатор ``C1``, резистор ``R1`` та кнопка ``SW12`` ("Reset")
----------------------------------------------------------------

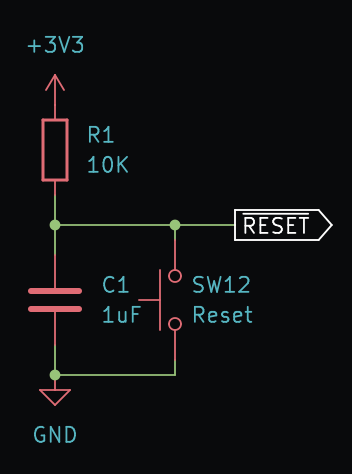
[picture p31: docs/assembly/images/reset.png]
Reset circuit


Ці компоненти відповідають за увімкнення мікроконтролера та його перезавантаження.

Річ у тім, що при під'єднанні живлення до Лілки, мікроконтролер не буде працювати коректно, доки не відбудеться процедура скидання (reset).

Уявіть собі, що сигнал скидання (reset) - це наче кава: коли на мікроконтролер подається живлення, він "прокидається" і починає спросоння робити неадекватні речі. Сигнал reset - це як кава: він "продупляє" мікроконтролер, і той починає працювати коректно.

Тобто скидання - це процес, який переводить мікроконтролер у початковий стан, в якому він може розпочати виконання програми з самого початку.

Резистор ``R1`` і конденсатор ``C1`` утворюють так зване RC-коло, або "коливальний контур", який відповідає за затримку сигналу скидання.
Це означає, що при підключенні живлення до Лілки, мікроконтролер розпочне роботу не відразу, а через деякий час (долю мікросекунди).

Цей коливальний контур є абсолютно необхідним і його потребують майже всі мікроконтролери: без нього мікроконтролер може працювати некоректно або взагалі не запускатися.

Регулятор напруги ``U3`` та конденсатори ``C2`` і ``C3``
--------------------------------------------------------

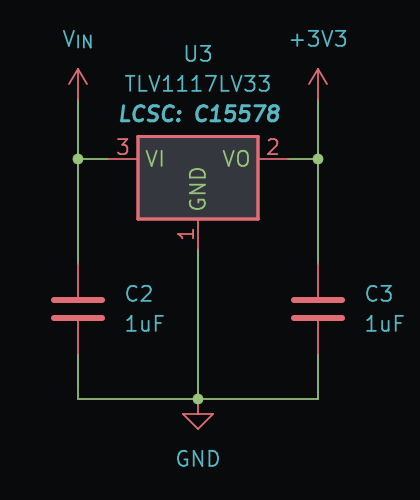
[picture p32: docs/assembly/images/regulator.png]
Voltage regulator


Ці компоненти відповідають за стабілізацію напруги живлення Лілки.

Мікроконтролер ESP32-S3-WROOM-N16R8 працює при напрузі від 3.0V до 3.6V. Але:

- Живлення від USB-порту комп'ютера може бути від 4.75V до 5.25V.
- Живлення від акумулятора може бути від 2.4V до 4.2V.

Обидві з цих напруг майже стовідсотково спалять мікроконтролер! Для цього і потрібен регулятор напруги ``U3``: він перетворює вхідну напругу в напругу 3.3V, яка потрібна мікроконтролеру.

Конденсатори ``C2`` і ``C3`` відповідають за стабілізацію напруги: вони зберігають енергію, яка потрібна компонентам Лілки, коли напруга від живлення змінюється.
Рекомендовані омінали цих конденсаторів переважно вказані в документації регулятора напруги.

Роз'єм USB (``J1``)
-------------------

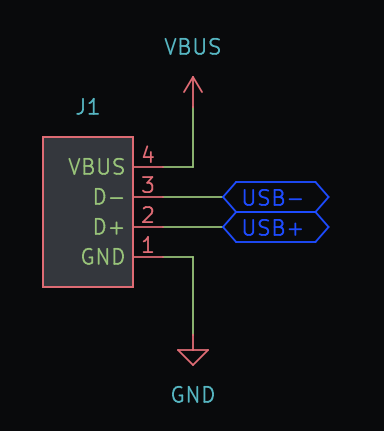
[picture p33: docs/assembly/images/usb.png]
USB Type C connector


Модуль ``J1`` - це всього лиш плата з припаяним роз'ємом USB Type C. Вона не містить жодних інших компонентів - лише роз'єм.

Паяти роз'єм USB Type C безпосередньо на головну плату Лілки було б дуже складно: роз'єм має дуже маленькі контакти, які важко паяти.
Саме тому ми і використовуємо модуль ``J1``: він має великі контакти, які можна легко паяти на основну плату Лілки.

Модуль заряду-розряду LiPo-акумулятора (``J4``)
-----------------------------------------------

Якщо ви збираєте комплект Лілки з акумулятором, цей модуль відповідає за зарядку акумулятора від USB-порту, а також забезпечує захист від перезаряду та перерозряду акумулятора при роботі Лілки від акумулятора.

Він працює на основі мікросхеми ``TP4056``, тому його часто так і називають - "модуль TP4056".

На виході цей модуль дає напругу, яка дорівнює напрузі акумулятора, тобто від 2.4V до 4.2V. Ця напруга подається на регулятор напруги ``U3``, який перетворює її в 3.3V для живлення мікроконтролера.

Польовий транзистор P-типу ``Q1``, резистор ``R3`` та діод ``D1``
-----------------------------------------------------------------

USB & battery power management

Ці компоненти потрібні для коректної роботи Лілки, коли ви одночасно заряджаєте акумулятор і живите Лілку від USB-порту.

Річ у тім, що одночасно заряджати акумулятор від USB і в той же час живити Лілку від цього ж акумулятора - небезпечно:
модуль TP4056 (``J4``) не вміє коректно відслідковувати стан заряду акумулятора, якщо той використовується Лілкою, і може подати на нього невідповідну напругу.

Тому ми використовуємо польовий транзистор P-типу (``Q1``), який "вимикається" при підключенні живлення від USB, і таким чином при під'єднаному USB-живленні Лілка живиться від USB, а не від акумулятора.

Резистор ``R3`` - це слабка підтяжка польового транзистора ``Q1`` до землі, щоб при відсутності напруги від USB цей транзистор не вимикався сам по собі, а за замовчуванням був увімкнений,
щоб Лілка живилася від акумулятора.

Діод ``D1`` не дозволяє напрузі від акумулятора подаватися на завтор транзистора ``Q1`` і тим самим призакривати його, коли USB-живлення від'єднане. 
Крім цього, як бонус - він частоково знижує напругу (на ~0.7V), і тому регулятор напруги ``U3`` при живленні Лілки від USB буде трохи менше нагріватися.

Резистори ``R2`` і ``R4``
-------------------------

Voltage divider

Ці резистори здійснюють ділення напруги для вимірювання напруги акумулятора.

Напруга акумулятора може бути в діапазоні від 2.4V до 4.2V, але :term:`АЦП` (аналого-цифровий перетворювач) мікроконтролера ESP32-S3-WROOM-N16R8 вміє вимірювати напругу лише від 0V до 3.1V.

Тому ми використовуємо резистори ``R2`` і ``R4``, які здійснюють ділення напруги, використовуючи формулу:

.. math::

    V_{\text{вихід}} = V_{\text{батарея}} \times \left(\frac{R_4}{R_2 + R_4}\right)

Номінали резисторів ``R2`` і ``R4`` вибираються так, щоб напруга на виході ділення була 3.1V при вхідній напрузі 4.2V.

В нашому випадку ми використовуємо резистори ``R2`` = 100 кОм і ``R4`` = 33 кОм.

Ми могли б використати і резистори менших номіналів - скажімо, 10 кОм і 3.3 кОм, але вони б витрачали в 100 разів більше енергії та швидше розряджали акумулятор.

Роз'єм розширення (``J2``)
--------------------------

Extension connector

Лілка - це набір для розробки, і ви, можливо, захочете підключити до неї додаткові датчики, дисплеї, камери, акселеометри, сервоприводи чи ще щось.

Для цього і потрібен роз'єм розширення ``J2``: він має виводи для живлення сторонніх компонентів, а також декілька :term:`GPIO`-ліній мікроконтролера, які можна використовувати для підключення додаткових пристроїв.

Детальніше про роз'єм розширення можна прочитати в розділі :ref:`extension`.

Модуль SD-карти (``J3``)
------------------------

SD card module

Цей модуль дозволяє Лілці читати та зберігати дані на SD-карті, а також запускати з неї сторонні прошивки.

SD-карти дозволяють працювати з ними через шину SPI, яка підтримується мікроконтролером ESP32-S3-WROOM-N16R8.

Більше інформації є тут: :ref:`sdcard`.

ЦАП (DAC) - Цифро-аналоговий перетворювач (``J5``)
--------------------------------------------------

DAC

Цей компонент відповідає за генерацію аналогових сигналів.

Найпоширеніше використання ЦАП - генерація звуків: відтворення мелодій, голосів, звуків природи, і т.д.

Лілка використовує модуль ЦАП на базі мікросхеми ``MAX98357A`` від компанії Maxim Integrated.

Це дозволяє Лілці відтворювати звуки високої якості, а також підключати до неї аудіо-пристрої виведення звуку - наприклад, колонки, навушники, аудіо-підсилювачі тощо.

Для роботи з ЦАПом використовується шина I2S.

П'єзо-динамік (``BZ1``)
------------------------

Buzzer

П'єзо-динамік - це простий динамік, який може відтворювати звуки. Його можна під'єднувати безпосередньо до :term:`GPIO`-виводів мікроконтролера.

Основні плюсі п'єзо-динаміка - його простота та ціна. Він не потребує жодних додаткових компонентів: просто підключіть його до :term:`GPIO`-виводів мікроконтролера і відтворюйте звуки.

Головний мінус - обмежені можливості. П'єзо-динамік може відтворювати лише прості звуки і не здатний відтворювати музику високої якості.
Крім того, ESP32-S3 не має вбудованого цифро-аналогового перетворювача, тому звукова хвиля може мати лише форму меандру (т. зв. "прямокутна" звукова хвиля).

Якщо ви хочете відтворювати музику високої якості, вам краще використати додатковий модуль ЦАП (див. вище).

IPS TFT дисплей (``U2``)
------------------------

Display

Дисплей. Куди ж без нього? ;)

Цей дисплей використовує IPS-матрицю, яка забезпечує високу якість зображення, широкі кути огляду, яскравість та насиченість кольорів.

Лілка використовує дисплей на базі мікросхеми ``ST7789`` від компанії Sitronix.

Кнопки
------

Думаю, тут все зрозуміло: кнопки використовуються для керування Лілкою.

Кожна кнопка підключена до свого :term:`GPIO`-виводу мікроконтролера і відповідає за певну функцію.

.. note::

    "Але чому ви не використали, скажімо, регістр зсуву для підключення кнопок, чи розширювачі I/O?" - запитаєте ви. "Ви могли б підключити до мікроконтролера 8 кнопок, використовуючи всього 3 :term:`GPIO`-виводи!"

    Відповідь проста: мета Лілки - бути простою у збірці. Регістри зсуву - це додаткові компоненти, які вам потрібно паяти і які займають місце на і так невеликій платі Лілки,
    тому ми вирішили обійтися без них.

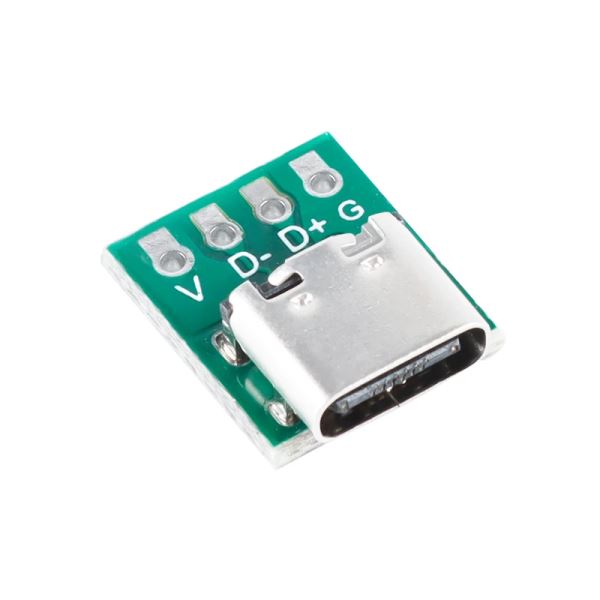
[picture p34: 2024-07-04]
docs/assembly/images/parts/usb.jpg

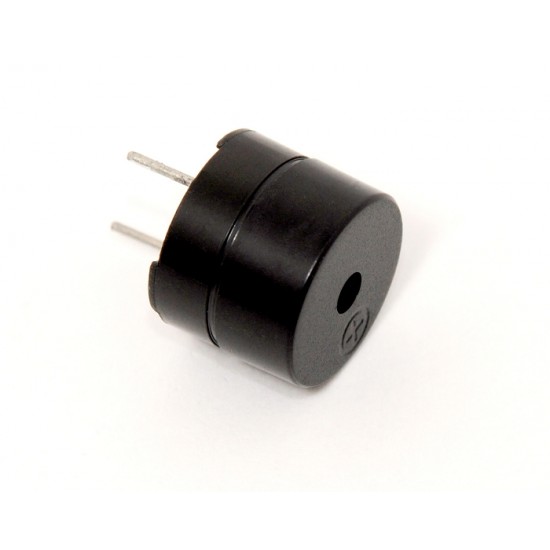
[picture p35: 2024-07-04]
docs/assembly/images/parts/buzzer.jpg

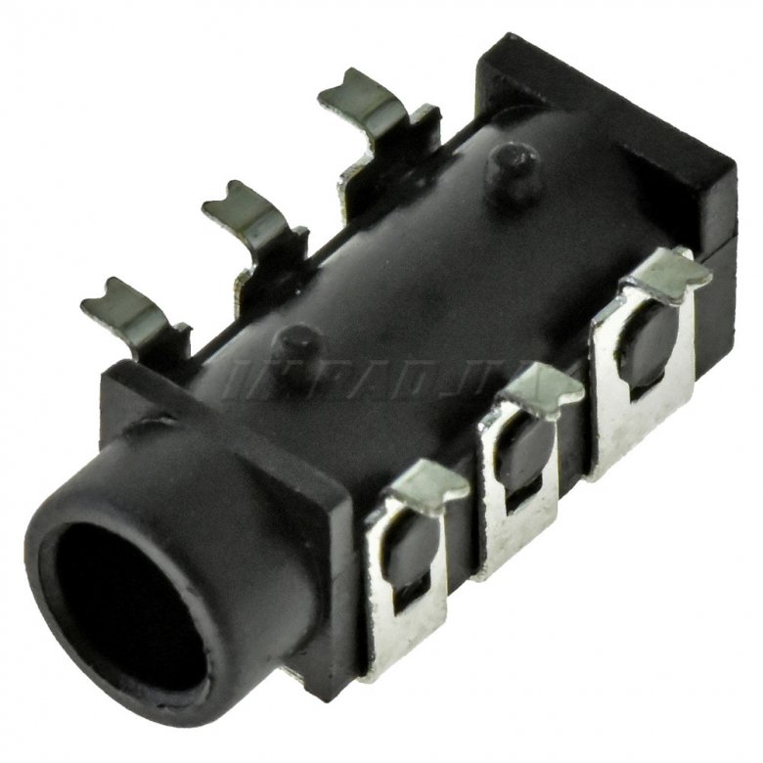
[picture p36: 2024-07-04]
docs/assembly/images/parts/jack.jpg

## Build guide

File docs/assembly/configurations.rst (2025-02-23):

Комплектації
============

Лілка - це модульний пристрій.

Комплектація залежить від обраного вами варіанту збірки. Перелік компонентів для кожного варіанту збірки вказаний в наступному розділі.

.. contents::
    :local:

----

1. **Базова** (мінімальна) комплектація
---------------------------------------

Існує основний варіант збірки, який включає в себе:

- Друкована плата "Лілка"
- Мікроконтролер ESP32-S3-WROOM-1-N16R8
- Дисплей 1.69\" IPS 240x280 ST7789
- Модуль microSD-карти
- Модуль роз'єму USB Type C
- П'єзо-динамік
- Резистори, конденсатори та регулятор напруги(LDO)
- Вимикач живлення

    .. warning::

        Для використання **БАЗОВОЇ** комплектації вам **ПОТРІБНО ЗАМКНУТИ** джампер ``JP1`` на друкованій платі, з'єднавши його контакти між собою за допомогою припою.

----

2. Базова + **Батарея**
-----------------------

Додатково можна встановити батарею. Для цього потрібно додаткові компоненти:

- Літій-полімерна батарея 3.7 В (на ваш вибір)
- Зарядний модуль TP4056
- Діод 1N4001
- Транзистор IRLML6401 (корпус - SOT-23)
- Декілька додаткових резисторів

    .. warning::

        Для використання комплектації **З БАТАРЕЄЮ** вам **ПОТРІБНО НЕ ЗАМИКАТИ** джампер ``JP1`` на друкованій платі. Якщо ви вже замкнули його, вам потрібно його розімкнути, нагрівши контакти паяльником і відокремивши їх один від одного.

    .. warning::

        Перші партії наборів з **Imrad** йдуть з хибним LDO, замість ``TLV1117LV33DCYR`` йде ``LD1117AS33TR``, для коректної роботи від батареї бажано використати **TLV**

----

3. Базова + **Аудіо**
---------------------

- Звуковий модуль на ваш вибір
- Динамік або гніздо для навушників

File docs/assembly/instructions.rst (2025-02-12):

Збір пристрою
=============

:term:`PCB` Лілки спроєктована для максимально простого збору зі збереженням її мінімального розміру.

Більшість компонентів - це :term:`THT`-компоненти, тобто компоненти, які вставляються в отвори плати і паяються з задньої сторони. Це дозволяє збирати плату без використання спеціального обладнання.

Декілька компонентів - це :term:`SMD`-компоненти, які паяються зверху. Серед них - мікроконтролер ESP32-S3-WROOM-1-N16R8, регулятор напруги TLV1117LV-33DCYR та транзистор IRLML6401.

Порядок збору
-------------

1. **Перш за все, припаяйте SMD-компоненти.**

   Вони займають найменше місця та не заважатимуть вам при пайці решти компонентів.**

   * ``U1`` (мікроконтролер ESP32-S3-WROOM-1-N16R8)
   * ``U3`` (регулятор TLV1117LV-33DCYR)
   * ``Q1`` IRLML6401 (якщо ви використовуєте комплектацію з батареєю)

2. **Припаяйте модуль USB-C** (``J1``).

   Переконайтесь, що ви вставили модуль USB-C вірно. Він має бути вирівняний з краєм плати.

   Є два способи паяти такі модулі на плату:

   - **Спосіб 1**: Ви можете прикласти його до плати та вставити штирьові контакти крізь нього та плату, утворивши таким чином "сендвіч". Після цього вам потрібно припаяти штирьові контакти з обох сторін.
     Таким чином модуль щільно прилягатиме до плати та не буде провисати.

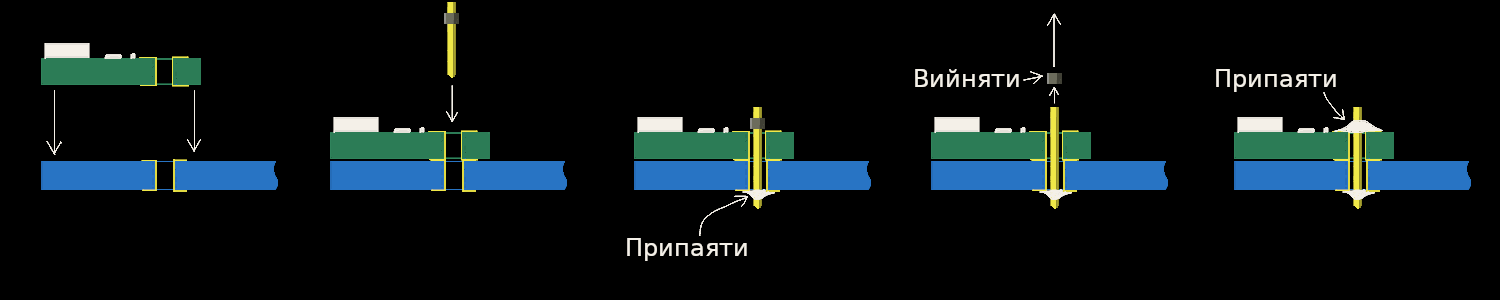
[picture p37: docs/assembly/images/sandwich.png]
     

   - **Спосіб 2**: Ви можете спершу припаяти штирьові контакти на модуль USB-C, а потім припаяти модуль на плату. Цей спосіб простіший, але модуль буде провисати, оскільки між
     ним та платою буде вільний простір, утворений пластиковим тримачем штирьових контактів.

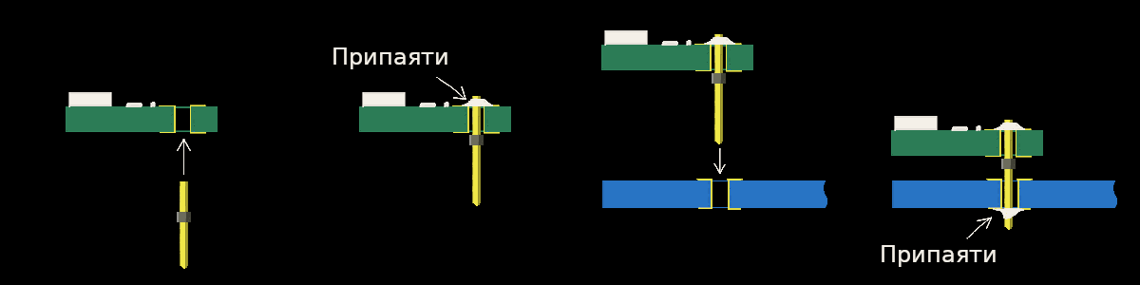
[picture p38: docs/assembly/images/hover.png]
     

   Є й інші способи - не бійтесь проявляти креативність!

3. **Якщо ви збираєте комплектацію з батареєю, припаяйте наступні компоненти (вони всі позначені пунктирними лініями на задній стороні плати)**

   * ``Q1`` IRLML6401
   * ``D1`` (діод 1N4001)
   * Резистори ``R3`` (100 кОм) та ``R4`` (33 кОм)
   * ``J4`` (модуль заряду/розряду батареї на базі TP4056)
   * LiPo батарея на ваш вибір (припаюється безпосередньо до пінів модуля заряду/розряду, позначених як B+ та B-)

   .. note::
      Обов'язково перевірте максимальний допустимий струм заряду вашого акумулятора! Модуль TP4056 по замовчуванню заряджає акумулятор струмом 1А. 
      Струм заряду можна корегувати заміною резистора R3(R_PROG) на платі модуля TP4056. 
   
   .. list-table:: **Таблиця зарядного струму**
      :widths: 25 25
      :header-rows: 1

      * - **Резистор (R_PROG)**
        - **Струм заряджання (I_charge)**
      * - 30 кОм
        - 40 мА
      * - 10 кОм
        - 120 мА
      * - 5 кОм
        - 240 мА
      * - 4 кОм
        - 300 мА
      * - 3 кОм
        - 400 мА
      * - 2 кОм
        - 600 мА
      * - 1.5 кОм
        - 800 мА
      * - 1.2 кОм
        - 1000 мА
      * - 1 кОм
        - 1200 мА  

   **Якщо ви збираєте комплектацію без батареї, не паяйте ці компоненти!**

   Натомість **замкніть** джампер ``JP1``, який знаходиться всередині посадкового місця діода ``D1``. Для цього використайте паяльник та припій, щоб замкнути контакти джампера.

4. **Припаяйте наступні компоненти:**

   * Резистори ``R1`` (10 кОм) ``R2`` (100 кОм)
   * Конденсатори ``C1`` (1 мкФ, маркування "105"), ``C2`` та ``C3`` (10 мкФ, маркування "106")

5. **Припаяйте 6-мм тактильні кнопки**:

   * ``SW9`` (Select)
   * ``SW10`` (Start)
   * ``SW12`` (Start)

6. **Припаяйте модуль SD-карти** ``J3``.

   Як і модуль USB-C, модуль SD-карти можна припаяти двома способами.

   **Переконайтесь, що ви вставили модуль SD-карти вірно!** Металеве гніздо для SD-карти повинне знаходитися **зовні** плати!

7. **Припаяйте 8 12-мм кнопок**:
   
   * ``SW1`` (Up)
   * ``SW2`` (Down)
   * ``SW3`` (Left)
   * ``SW4`` (Right)
   * ``SW5`` (A)
   * ``SW6`` (B)
   * ``SW7`` (C)
   * ``SW8`` (D)

8. **Якщо ви збираєте комплектацію зі звуком, припаяйте** :term:`ЦАП`-модуль ``U4`` (MAX98357A).

   * **Якщо ви плануєте використовувати навушники,** спершу припаяйте роз'єм для навушників ``J6`` до плати. Після цього обов'язково припаяйте всі 9 контактів модуля MAX98357A.
   * **Якщо ж ви хочете використовувати власний динамік,** вам достатньо припаяти лише 7 основних контактів, а контакти динаміка припаяти безпосередньо до пінів (+) та (-) модуля.

9. **Припаяйте п'єзоелектричний динамік** ``BZ1``.

   Він дозволяє відтворювати примітивні звуки. Він працює окремо від :term:`ЦАП`-модуля, тому ви можете використовувати його навіть якщо не паяєте :term:`ЦАП`-модуль.

10. **Припаяйте роз'єм дисплея та роз'єм розширення:**

   * ``U2`` (роз'єм дисплея типу "мама")
   * ``J2`` (роз'єм розширення типу "тато")

11. **Припаяйте вимикач живлення** ``SW11``.

Вітаємо, ваша плата готова до використання! Тепер вам залишається лише завантажити програмне забезпечення на ESP32-S3. Для цього читайте наступний розділ - :ref:`programming`.

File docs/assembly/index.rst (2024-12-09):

:octicon:`tools` Як зібрати Лілку
=================================

.. warning::

    Будь ласка, уважно прочитайте статті у цьому розділі, перш ніж почати збирати Лілку.

.. toctree::
    :maxdepth: 2

    configurations
    components
    every_component
    instructions

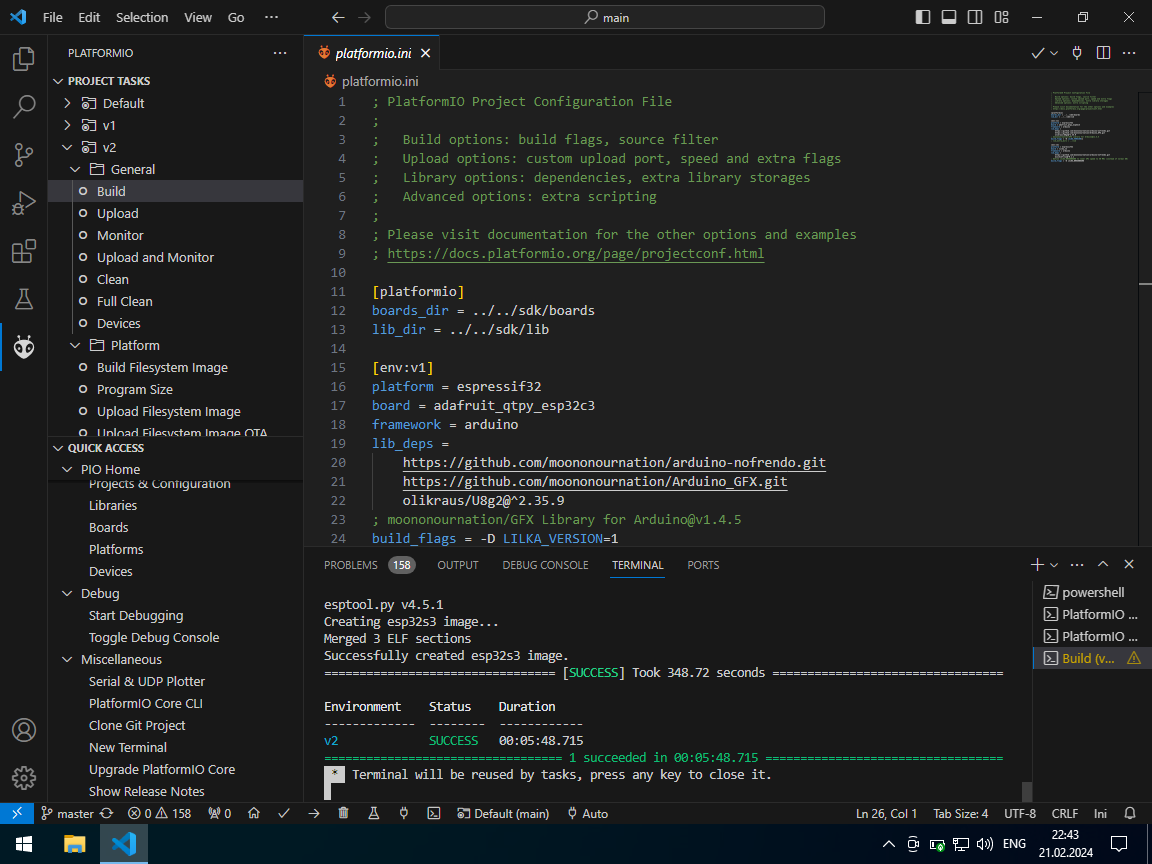
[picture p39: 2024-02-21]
docs/keira/images/16_pio_build_ok.png

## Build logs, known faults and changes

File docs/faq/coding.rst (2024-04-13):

Програмування
=============

.. contents:: Зміст
   :local:

Що таке "Arduino", "ESP-IDF" і ця ваша "бібліотека lilka"?
--------------------------------------------------------------

- **Arduino** - це фреймворк, яка дозволяє швидко і просто створювати програми для мікроконтролерів.

  Основна перевага Arduino - це стандартизований і простий інтерфейс програмування, який дозволяє швидко створювати програми для мікроконтролерів.
  Неважливо, чи ви пишете код для ESP32, чи для STM32, чи для ATmega: ви можете використовувати однаковий інтерфейс програмування, однакові функції та навіть однакові бібліотеки.

  Тобто Arduino - це своєрідна абстракція, яка дозволяє вам писати код для мікроконтролерів, не замислюючись про те, який саме мікроконтролер ви використовуєте.

- **ESP-IDF** - це офіційний фреймворк для програмування мікроконтролерів сімейства ESP32 від компанії Espressif.

  ESP-IDF - це більш низькорівневий фреймворк, який дозволяє вам працювати з ESP32 на більш низькому рівні, ніж Arduino.
  Код, написаний на ESP-IDF, може бути більш швидким і ефективним, ніж код, написаний на Arduino, але він також буде складнішим і працюватиме тільки на мікроконтролерах сімействі ESP32.

- **Бібліотека lilka** - це бібліотека, яку ми написали для роботи з ESP32-S3 на платформі Arduino.

  Це - спроба поєднати простоту Arduino з ефективністю ESP-IDF саме для написання програм для Лілки, а також надати додаткові функції, які допоможуть вам створити програми для Лілки швидше і простіше.

Але не лякайтесь: **ви можете одночасно використовувати і Arduino, і ESP-IDF, і бібліотеку lilka**!

Річ у тім, що бібліотека ``lilka`` написана на основі ESP32-Arduino, а ESP32-Arduino, в свою чергу, використовує ESP-IDF.
Це означає, що ви можете використовувати в своєму коді і функції ESP-IDF, і функції Arduino, і функції бібліотеки ``lilka``.

.. graphviz::

    digraph G {
        rankdir=LR;
        node[shape=box];
        "Ваш код" [style=filled, fillcolor="#aaffaa"];

        subgraph cluster_0 {
            style=filled;
            color=lightgrey;
            node [style=filled,color=white];
            "Бібліотека lilka";
            "ESP32 Arduino";
            "ESP-IDF";
        }

        "Ваш код" -> "Бібліотека lilka" [minlen=5];
        "Ваш код" -> "ESP32 Arduino";
        "Ваш код" -> "ESP-IDF";
        "Бібліотека lilka" -> "ESP32 Arduino" -> "ESP-IDF" [minlen=2];
        "Бібліотека lilka" -> "ESP-IDF";

        { rank=max; "Ваш код" }
    }

Що таке "паніка"?
-----------------

"Паніка" ("panic") - це загальна назва критичних ситуацій, які виникають, коли програма не може продовжувати свою роботу через критичну помилку або через потенційну можливість пошкодження даних.

Класична паніка - це дереференсія нульового вказівника:

.. code-block:: c

    int *p = NULL;
    *p = 42; // Паніка!

Проте паніка може бути викликана іншими причинами, такими як переповнення стеку, помилки вводу-виводу, помилки пам'яті, помилки в програмному коді, помилки в апаратурі, і так далі.

В більшості випадків при паніці ESP32 виводить в консоль не лише повідомлення про помилку, але і стек викликів, який привів до паніки.

Цей стек можна розкодувати, щоб побачити, які функції були викликані перед панікою і в якому порядку.

В KeiraOS для цього є "команда" ``decode_backtrace``, який використовує утиліту ``addr2line`` з комплекту ESP-IDF для розкодування стеку викликів. Ось як його використовувати:

.. code-block:: bash

    pio run -e v2 -t decode_backtrace -a '0x42013efa:0x3fcbbc10 0x4200894d:0x3fcbbcd0 0x4201962e:0x3fcbbd10 0x4201987b:0x3fcbbd30 0x4202724c:0x3fcbbd60'

Це виведе розкодовані функції та рядки, які викликалися перед панікою, від "найглибшої" до "найповерхневішої". Тобто перший рядок - це момент, де відбулася паніка.

Детальнішу інформацію про паніки можна знайти в `документації ESP-IDF <https://docs.espressif.com/projects/esp-idf/en/latest/esp32s3/api-guides/fatal-errors.html>`_.

Я отримую паніку ``Stack canary watchpoint triggered``
------------------------------------------------------

В ESP32 є спеціальний механізм, який дозволяє виявити переповнення стеку. Цей механізм називається "стекова канарка" (stack canary).
Він слідкує за переповненням стеку задачі.

Оскільки в FreeRTOS кожна задача при створенні отримує свою власну область стеку, яка визначається параметром ``stack_depth`` функцій ``xTaskCreate...``,
найчастіше ця помилка виникає через недостатньо велику область стеку вашої задачі. Ви можете збільшити розмір її стеку, визначивши більший розмір стеку при виклику ``xTaskCreate...``.

.. warning::

    Збільшення розміру стеку означає, що ваша програма буде використовувати більше пам'яті.

    Лілка використовує мікроконтролер ESP32-S3, який має всього декілька сотень кілобайт внутрішньої оперативної пам'яті (RAM), але крім неї вона має зовнішню оперативну пам'ять, яка називається PSRAM.

    Стек задачі зберігається у внутрішній RAM.

    Якщо вам потрібно зберігати великі обсяги даних в пам'яті, то можливо замість збільшення стеку вам краще варто використовувати динамічне виділення пам'яті в "купі",
    використовуючи функцію ``ps_malloc``, яка виділяє пам'ять у PSRAM (якої в Лілці аж 8 МБ).

    PSRAM дещо повільніша за внутрішню RAM, але вона дозволяє зберігати в десятки разів більше даних. В більшості випадків різниця в швидкості взагалі не буде помітною.

Я отримую паніку ``IllegalInstruction``
---------------------------------------

Ця помилка найчастіше трапляється, коли задача FreeRTOS, створена за допомогою одної з функцій ``xTaskCreate...``,
доходить до кінця (або робить ``return``) без виклику ``vTaskDelete(NULL)``.

Переконайтеся, що ваша задача завершується викликом ``vTaskDelete(NULL)``: іншими словами, викликайте ``vTaskDelete(NULL)`` замість ``return``.

Я отримую паніку ``Task watchdog got triggered``
------------------------------------------------

Ця помилка виникає, коли задача не викликає ``vTaskDelay`` або ``vTaskDelayUntil`` протягом певного часу.

В ESP32 є механізм "сторожового таймера" (watchdog timer), який слідкує за тим, щоб задачі виконувалися вчасно.
Якщо задача не викликає ``vTaskDelay`` або ``vTaskDelayUntil`` протягом певного часу (зазвичай 10 секунд), ви отримаєте помилку ``Task watchdog got triggered``.
Це робиться для того, щоб уникнути "зависання" задачі, яка не виконується.

Переконайтеся, що ваша задача час від часу викликає ``taskYIELD()`` чи ``vTaskDelay(1)``.

Якщо це неможливо - наприклад, якщо ви використовуєте сторонню бібліотеку, яка робить довгі і складні обчислення - ви можете збільшити таймаут сторожового таймера,
викликавши `esp_task_wdt_init <https://docs.espressif.com/projects/esp-idf/en/v4.4/esp32/api-reference/system/wdts.html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>`_ з більшим значенням таймауту.

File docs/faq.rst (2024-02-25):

Поширені запитання
==================

.. contents:: Зміст
   :local:

Навіщо мені Лілка?
------------------

Лілка - це маленький, легкий і мобільний пристрій, який може бути використаний для різних цілей, таких як навчання, розробка програмного забезпечення, робототехніка, IoT, медіацентр, проста ігрова консоль і багато іншого.

Вона відносно проста і дешева, а також використовує доволі потужний мікроконтролер ESP32-S3-WROOM-1-N16R8, який має вбудований Wi-Fi та Bluetooth, а також 16 МБ зовнішньої RAM.

Основна мета Лілки - це бути дешевою, легкою в навчанні та сумісною з різними додатками, які були розроблені для неї іншими користувачами.

Якщо ви шукаєте потужну ігрову консоль, то Лілка, можливо, не найкращий вибір для вас.
(Хоча на ній можна без проблем грати в досить популярні старі ігри, такі як Doom чи Wolfenstein, а також запускати на ній емулятори NES, SNES та інших консолей.)

Я не можу завантажити прошивку на свій пристрій. Що робити?
-----------------------------------------------------------

Переконайтеся, що ви використовуєте саме так званий "data" кабель, а не "power" кабель. "Power" кабель призначений лише для заряджання пристрою, а "data" кабель - і для передачі даних, і для заряджання.

.. warning:: Зверніть увагу: Лілка не підтримує USB 3.0, тому ви не зможете прошивати її через кабель Type C - Type C. Використовуйте кабель Type C - Type A.

Я хочу більший дисплей!
-----------------------

Лілка - це бюджетний пристрій, тому вона має досить маленький дисплей.

Крім того, кожен дисплей має власний контролер, який відповідає за відображення зображення. Це означає, що ви не зможете просто підключити більший дисплей до Лілки.
Таких контролерів є **багато** і вони **не сумісні** між собою, а наша команда не має можливості тестувати та підтримувати кожен з них.

Однак, якщо ви знайдете дисплей з таким же контролером (і таким самим розташуванням контактів), як у Лілки, ви можете спробувати підключити його до Лілки, але це буде на ваш власний ризик.

Але не забувайте, що мета Лілки - це не лише бути маленьким, легким і мобільним пристроєм, а й бути сумісною з різними додатками, які були розроблені для неї іншими користувачами.
Якщо ви підключите більший дисплей, деякі додатки можуть відображатися некоректно або взагалі не працювати.

Якщо вам потрібен більший дисплей, можливо, вам варто розглянути інші пристрої.

Чому Лілка називається Лілкою?
------------------------------

Я назвав цей пристрій на честь однієї з моїх кішок, яку звати Ліла, яку, в свою чергу, я назвав на честь Ліли з Футурами.
Цей пристрій досить маленький та простий і асоціюється мені з англійським словом "little", тобто "маленький". Звідси і виникла ідея для назви. :)

.. list-table::
   :widths: 50 50
   :header-rows: 1

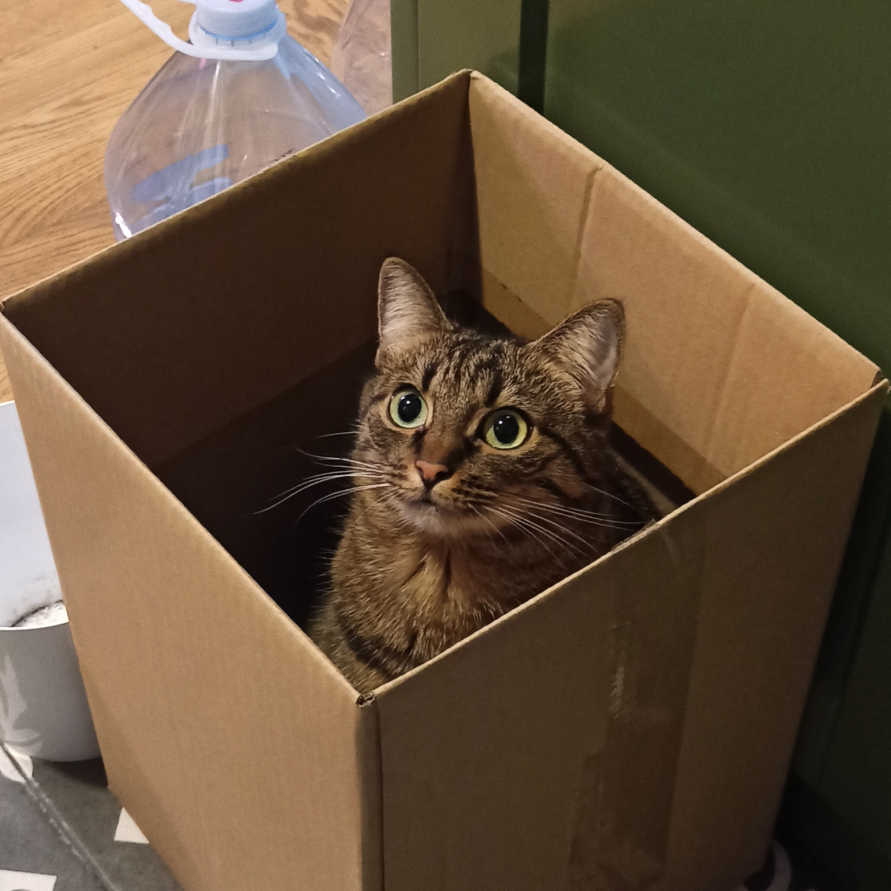
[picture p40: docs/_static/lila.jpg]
Ліла
   * - 
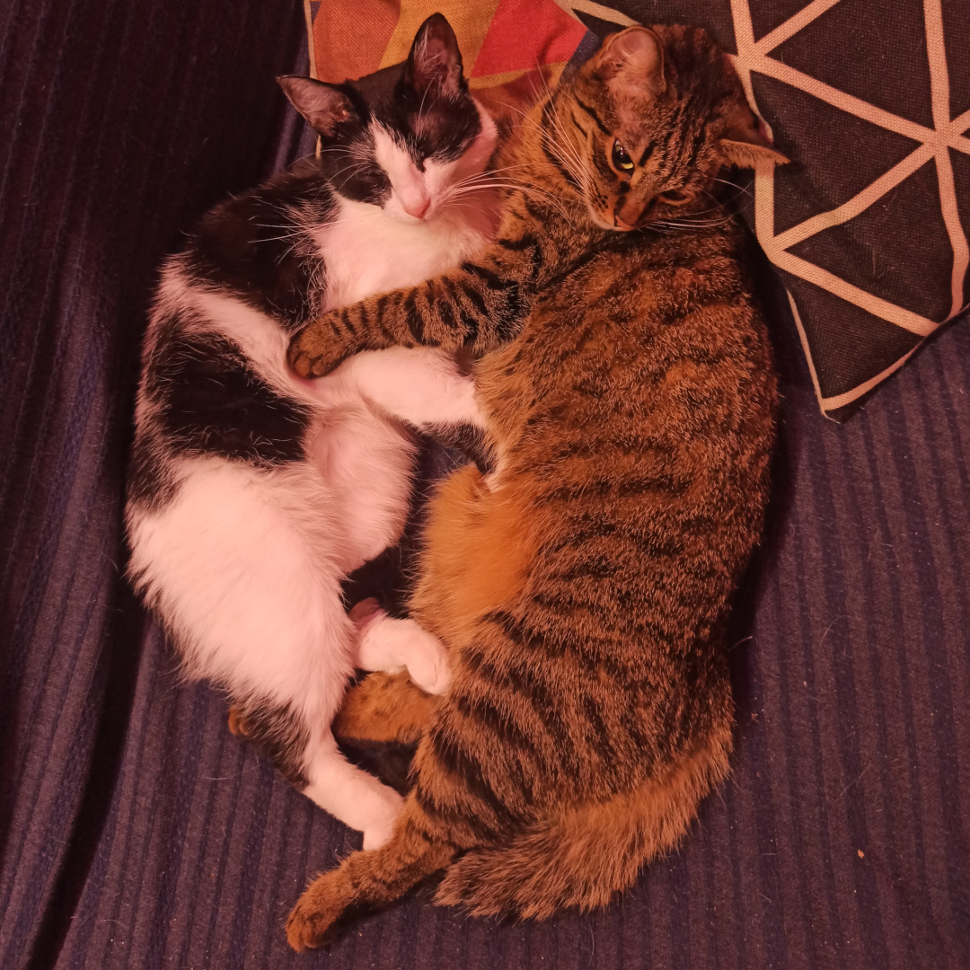
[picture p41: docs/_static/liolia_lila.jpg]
Льоля та Ліла
     - 
   * - Ліла
     - Льоля та Ліла

Крім того, Лілка - це українське жіноче ім'я, яке походить від слова "лілея". Лілея - це квітка, яка символізує чистоту, вірність, вічність, а також відновлення і відродження.

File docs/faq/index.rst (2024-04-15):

:octicon:`question` Поширені запитання
=======================================

.. toctree::
    :maxdepth: 1

    general
    hardware
    coding

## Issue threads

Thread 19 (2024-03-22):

Fix potential short-circuit of MAX98357 with button

and3rson, 2024-03-22:

Closed 2024-03-23.

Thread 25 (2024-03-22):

Add jumper for buzzer to bypass resistor (normally closed)

and3rson, 2024-03-22:

Closed 2024-03-23.

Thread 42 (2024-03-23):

Build main branch for v1 lilka board broken

frostmorn, 2024-03-23:
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

Closed 2024-03-25.

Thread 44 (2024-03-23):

Update buzzer footprint for more flexibility

and3rson, 2024-03-23:

Closed 2024-03-23.

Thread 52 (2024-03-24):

keira os works wrong way with file extensions which consists from upper and lower case characters

frostmorn, 2024-03-24:
Only lowercase extensions supported

Closed 2024-03-25.

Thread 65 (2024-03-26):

Lilka freezes after disconnecting the serial monitor

black-ghost-off, 2024-03-26:
Lilka freezes after disconnecting the serial monitor

;USB CDC
;USB3.0 port pc
;Without battery components
;Serial Monitor VSCode plugin(ms-vscode.vscode-serial-monitor) OR Serial Monitor VSCode platformio same
;Branch main, commit aa3de2a

and3rson, 2024-04-10:
Проблема все ще існує з найсвіжішим кодом?

Closed 2025-01-07.

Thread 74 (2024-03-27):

Select button not working in DOOM when I2S driver is installed

and3rson, 2024-03-27:

Closed 2024-03-28.

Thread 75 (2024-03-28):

After load NES ROM Screenshot will work via single button Start

frostmorn, 2024-03-28:
Select seems to be always pressed and never released

osd_getinput never recieve lilka::State with [lilka::Button::SELECT].justPressed

Could or not be related to https://github.com/and3rson/lilka/issues/74

and3rson, 2024-03-28:
Fixed in #78

Closed 2024-03-28.

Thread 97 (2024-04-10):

[TRACKER] V2 public release: documentation improvements

and3rson, 2024-04-10:
* [x] Інфо про нюанси спільної шини SPI для дисплея і SD-карти
* [x] Інфо про компромісні рішення в дизайні Лілки V2
* [x] #23
* [x] Ієрархія фреймворків/бібліотек: lilka -> arduino -> idf
* [x] #107

Closed 2024-07-26.

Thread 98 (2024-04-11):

Upcoming deadlock in `FileUtils::createSDPartTable`

and3rson, 2024-04-11:
Ми додавали `beginTransaction`, оскільки `sdcard_uninit` цього не робив:

https://github.com/and3rson/lilka/blob/e69204240aa8d05004d9b5a05b4515cbd0dfa045/sdk/lib/lilka/src/lilka/fileutils.cpp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
...але цю проблему вже пофіксили: https://github.com/espressif/arduino-esp32/issues/9438
Тому цей `beginTransaction` потрібно забрати або принаймні додати якийсь `#ifdef`, який дивиться на версію `arduino-esp32`.

Крім того, потрібно затестити, чи все ще потрібен `beginTransaction` для `sdcard_init`:
https://github.com/and3rson/lilka/blob/e69204240aa8d05004d9b5a05b4515cbd0dfa045/sdk/lib/lilka/src/lilka/fileutils.cpp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
...тобто чи мерехтить екран, якщо забрати ще й цей `beginTransaction`.

@frostmorn

Closed 2024-04-13.

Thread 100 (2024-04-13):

Add auto-repeat to `Controller`, possibly as `Controller::setAutoRepeat(Button button, bool enable, uint32_t delayMs = 250, uint32_t repeatMs = 50)`

and3rson, 2024-04-13:

frostmorn, 2024-04-13:
я вже пробував щось подібне, можна поряд з перевіркою на debounce чистити state

and3rson, 2024-04-13:
> я вже пробував щось подібне, можна поряд з перевіркою на debounce чистити state

@frostmorn Так, десь там поруч і думав це додати. В структурі стану кожнох кнопки вже є поле `time`, тому можна просто всередині `inputTask` перевіряти, чи вже минуло `delayMs` і тоді робити `justPressed = true` кожні repeatMs.

Потрібно буде ще додати в цю структуру поле `lastRepeat` (щоб мати змогу міряти інтервал повторення), а також додати туди поля `delay` і `repeat`, які за замовчуванням 0 (не повторювати).

Closed 2024-04-14.

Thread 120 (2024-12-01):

SD card bug

black-ghost-off, 2024-12-01:
Після гри в ігри Zelda, mario, batman, на nofrendo, після закінчиння гри і перезавантаженні лілки(без відключення живлення) через кнопку reset перестає працювати sd карта, допомогає перезавантаження.

SD карта Patriot 16GB HC I, Class 10

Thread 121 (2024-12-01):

SD card bug(menu -> bmp, txt files)

black-ghost-off, 2024-12-01:
При натску в sd карті на файли TXT, BMP лілка зависає до скидання, нічого на екранні не відображається, повторний натиск A повертає в нормальний стан меню.

frostmorn, 2024-12-03:
В нас немає коду який би оброблював BMP\TXT формат, в цьому випадку має з'явитися на екрані інформація про розмір файла в байтах.

Closed 2024-12-14.

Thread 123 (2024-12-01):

Long start, exit button from apps and games.

black-ghost-off, 2024-12-01:
Довге завантаження і противний звук з бузером при кожному завантаження(додати можливість вимкнути).
Вихід з додатків скрізь різний, а інколи буває що треба повністью перезавантажити лілку.

black-ghost-off, 2024-12-01:
Можливо як варіант подумати з приводу кнопки додаткової десь зліва зверху від ABCD коло бузера, яка буде дозволяти нам покидати додатки.

Ще як ідея додати в прошивку ділянку ОЗУ в яку зберігати якісь стейти(в якій папці був останній раз користувач наприклад)  і можна налаштувати щоб RESET не стирав цю ділянку.

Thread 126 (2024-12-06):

Rework Serial Interface

frostmorn, 2024-12-06:
Current implementation of serial_log and serial_err isn't suitable for multi-threading. Data sent in a same time from different RTOS tasks interfere, so user receive wrong output.

black-ghost-off, 2024-12-06:
Не критично, можливо внести рівні дебагу?
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

frostmorn, 2024-12-06:
я думаю ми просто збережемо абсолютно все на сд карту, тоді в тому всьому буде простіше орієнтуватись :smile:

black-ghost-off, 2024-12-06:
Та не треба, це месіво буде

frostmorn, 2024-12-06:
cat |grep -i <TAG>
суть в тому аби зберегти хронологічний порядок і можливо записувати час з моменту запуску

Closed 2025-01-07.

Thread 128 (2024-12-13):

APP_FLAG_FULLSCREEN ignored by panel

noisedsn, 2024-12-13:
Не зникає панель під час роботи додатків, в яких встановлено APP_FLAG_FULLSCREEN та НЕ встановлено APP_FLAG_INTERLACED, таких як NesApp, ModPlayerApp, AbstractLuaRunnerApp та інші. В результаті, вгорі екрана відображається панель, а додаток рендериться зміщеним на 24 пікселі вниз і верхні рядки 24...48 займають артефакти від накладання нижньої частини кадру додатка на верхню.

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

Відчуваю, що це, можливо, якось пов'язано зі змінами щодо інтерлейсу. Якщо примусово малювати все через інтерлейс, то баг зникає в усіх додатках. Для цього я спробував замінити в файлі appmanager.cpp
                    lilka::display.drawCanvas(app->backCanvas);
на
                    lilka::display.drawCanvasInterlaced(app->backCanvas, app->frame % 2);

На жаль, докопатися до суті і пофіксити коректно моїх скромних знань не вистачило...

frostmorn, 2024-12-13:
can't reproduce

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

noisedsn, 2024-12-13:
> can't reproduce

А скріншоти і у мене красиві. У фреймбуфері дані коректні. здається, а на екрані мерехтять 24-48 рядки і панель стирчить у повноекранних додатках (крім лілтрекера, до речі). Може якісь таймінги в залізі, чи глюки компілятора - хтозна, я не справжній програміст. Поки що вдалося некрасиво пофіксити, додавши у display.cpp ще одну функцію аналогічну тій що відмальовує інтерлейс:

void Display::drawCanvasBad(Canvas* canvas) {
    this->startWrite();
    for (int y = 0; y < canvas->height(); y ++ ) {
        this->writeAddrWindow(canvas->x(), canvas->y() + y, canvas->width(), 1);
        this->writePixels(canvas->getFramebuffer() + y * canvas->width(), canvas->width());
    }
    this->endWrite();
}

ну і в display.h:
    void drawCanvasBad(Canvas* canvas);

Після чого в appmanager.cpp:
lilka::display.drawCanvas(app->backCanvas);
на
lilka::display.drawCanvasBad(app->backCanvas);

noisedsn, 2024-12-14:
Тим не менш, зі штатною функцією глюк є, з моїм костилем - немає. Не одразу помітив, що панель не відображається як звичайно, то просто "слід" від неї, на якому не йде годинник і нічого не міняється.

https://github.com/user-attachments/assets/2ec24964-374b-4f5c-b61f-900b69038e58

Таке враження наче десь якась команда на зміну координат губиться, а моя тормозна функція трохи все сповільнила. Пробував потикати в різні місця delay - не допомагає.  Замовив другий дисплей, приїде - спробую з ним, може мені глючний попався.

noisedsn, 2024-12-19:
Мені дико соромно, в мене був не найновіший зріз репозиторію. В останній прошивці все коректно.

Closed 2024-12-19.

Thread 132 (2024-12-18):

Пошук на docs.lilka.dev працює некоректно

frostmorn, 2024-12-18:
При переході на будь яку сторніку в результатах отримуємо 404

suckordie, 2025-02-10:
фікситься в наступному релізі sphinx-rtd-theme==2.0
не впевнений тільки, як провалідувати, що цей апгрейд нічого не ламає =)

Closed 2025-02-12.

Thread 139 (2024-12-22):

Репозиторій з користувацькими скриптами

frostmorn, 2024-12-22:
Створити репозиторій з користувацькими скриптами та ресурсами до них. Додати можливість їх завантаження з лілки.

black-ghost-off, 2024-12-24:
https://github.com/and3rson/lilka/pull/147

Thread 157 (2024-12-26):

MODPlayerApp: causes reboot

frostmorn, 2024-12-26:
RTOS task MODPlayer could still work, when MODPlayer destructor called.
Which results in accessing non existent value which ends in undefined behavior.

UART DATA:
```
assert failed: xQueueSemaphoreTake queue.c:1545 (( pxQueue ))
```

Backtrace:
```
/home/runner/work/esp32-arduino-lib-builder/esp32-arduino-lib-builder/esp-idf/components/esp_system/panic.c:408
/home/runner/work/esp32-arduino-lib-builder/esp32-arduino-lib-builder/esp-idf/components/esp_system/esp_system.c:137
/home/runner/work/esp32-arduino-lib-builder/esp32-arduino-lib-builder/esp-idf/components/newlib/assert.c:85
/home/runner/work/esp32-arduino-lib-builder/esp32-arduino-lib-builder/esp-idf/components/freertos/queue.c:1549 (discriminator 1)
/home/orphey/Programming/lilka/firmware/keira/src/apps/modplayer/modplayer.cpp:188
/home/orphey/Programming/lilka/firmware/keira/src/apps/modplayer/modplayer.cpp:34
```

frostmorn, 2024-12-27:
File descriptors problem
UART:
```
E (50484) vfs_fat: open: no free file descriptors
[ 50410][E][vfs_api.cpp:301] VFSFileImpl(): fopen(/sd/sdcard/mods/beyond_music.mod) failed

assert failed: heap_caps_free heap_caps.c:381 (heap != NULL && "free() target pointer is outside heap areas")
```
Backtrace:
```
Decoding backtrace for /home/orphey/Programming/lilka/firmware/keira/.pio/build/v2/firmware.elf
/home/runner/work/esp32-arduino-lib-builder/esp32-arduino-lib-builder/esp-idf/components/esp_system/panic.c:408
/home/runner/work/esp32-arduino-lib-builder/esp32-arduino-lib-builder/esp-idf/components/esp_system/esp_system.c:137
/home/runner/work/esp32-arduino-lib-builder/esp32-arduino-lib-builder/esp-idf/components/newlib/assert.c:85
/home/runner/work/esp32-arduino-lib-builder/esp32-arduino-lib-builder/esp-idf/components/heap/heap_caps.c:381
/home/runner/work/esp32-arduino-lib-builder/esp32-arduino-lib-builder/esp-idf/components/newlib/heap.c:39
/home/orphey/Programming/lilka/firmware/keira/.pio/libdeps/v2/ESP8266Audio/src/AudioGeneratorMOD.cpp:69 (discriminator 2)
/home/orphey/Programming/lilka/firmware/keira/src/apps/modplayer/modplayer.cpp:231
/home/orphey/Programming/lilka/firmware/keira/src/apps/modplayer/modplayer.cpp:34
```

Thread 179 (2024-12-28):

Create some page in docs about possible build flags

frostmorn, 2024-12-28:
Currently added only by me are:

``USE_EXT_SPI_FOR_SD`` maps sdcard on spi1, and uses extension header pins :
SPI2_SCK     12
SPI2_MISO    13
SPI2_MOSI    14
SPI2_DEV1_CS 21

``FMANAGER_DEBUG`` enables logging for FileManagerApp

these two would work after merging https://github.com/and3rson/lilka/pull/178 pull request

also already exist

``NESAPP_INTERLACED`` to render half of frame in NesApp, odd/even rows of pixels so half per frame.
render full frame(default)

``KEIRA_SCREENSHOT_BMP`` to make screenshots in BMP format. PNG(default)

``LILKA_BREADBOARD`` reduces display spi speed to 40 mHz, 80mHz (default)

``KEIRA_RAM_ICON`` should show ram usage on panel in an icon format instead of numbers(default)

Probably some others, I've zero idea about, anyways, cause their number rise we should create doc for them

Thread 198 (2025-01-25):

DOOM freezes on startup

noisedsn, 2025-01-25:
Last message: "InitGraphics: Auto-scaling factor: 1".
This occurs after commit 3fffb33c09edd7e846803e11df69fe1cc03118da

doom.HEAD.bin - freezes
doom.3fffb33.bin - freezes
doom.54b6c86.bin - runs OK

[doom..zip](https://github.com/user-attachments/files/18547624/doom.zip)

Closed 2025-01-26.

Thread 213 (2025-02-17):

Поганий приклад в документації

lagemeet, 2025-02-17:
Поганий приклад в документації
https://docs.lilka.dev/uk/latest/library/ui/#_CPPv4N5lilka4MenuE
Без використання буферу дисплей буде миготіти.

Приклад який я пропоную:
```
#include <lilka.h>

void setup() {
    lilka::begin();
}

void loop() {
    lilka::Menu dreams("Оберіть щось");
    dreams.addItem("Смерть русні");
    dreams.addItem("Ядерка на червону площу");
    dreams.addItem("Повернення Криму");
    lilka::Canvas canvas;
    while (!dreams.isFinished()) {
      dreams.update();
      dreams.draw(&canvas);
      lilka::display.drawCanvas(&canvas);
    }
    int index = dreams.getCursor();
    lilka::MenuItem item;
    dreams.getItem(index, &item);
    Serial.println(String("Ви обрали пункт ") + item.title);
}
```

frostmorn, 2025-02-19:
+
не забудь додати що це не розповсюджується на кейру

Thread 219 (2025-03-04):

Reboot on Tamagochi launch

frostmorn, 2025-03-04:
UART:
assert failed: xQueueTakeMutexRecursive queue.c:717 (pxMutex)

Backtrace:
```
/home/runner/work/esp32-arduino-lib-builder/esp32-arduino-lib-builder/esp-idf/components/esp_system/panic.c:408
/home/runner/work/esp32-arduino-lib-builder/esp32-arduino-lib-builder/esp-idf/components/esp_system/esp_system.c:137
/home/runner/work/esp32-arduino-lib-builder/esp32-arduino-lib-builder/esp-idf/components/newlib/assert.c:85
/home/runner/work/esp32-arduino-lib-builder/esp32-arduino-lib-builder/esp-idf/components/freertos/queue.c:717 (discriminator 1)
/home/orphey/Programming/lilka/sdk/lib/lilka/src/lilka/controller.cpp:14
/home/orphey/Programming/lilka/sdk/lib/lilka/src/lilka/controller.cpp:145
/home/orphey/Programming/lilka/firmware/keira/src/apps/tamagotchi/tamagotchi.cpp:100
/home/orphey/Programming/lilka/firmware/keira/src/app.cpp:41
```

frostmorn, 2025-06-22:
can't reproduce anymore -___-

Closed 2025-06-22.

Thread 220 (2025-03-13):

[FileManager] Store last past in NVS storage, after reset try to restore

frostmorn, 2025-03-13:

black-ghost-off, 2025-03-13:
Flash(NVS) limited up to 100000 rewrites.

Read about __NOINIT_ATTR , RTC_NOINIT_ATTR , and RTC memory, it can store values between resets.

frostmorn, 2025-03-16:
I see, rtc memory could be even better. it won't persist on a full power off(which is okay) at same time would allow to restore needed values on rest. could use it

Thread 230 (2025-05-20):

Keira Localization

frostmorn, 2025-05-20:
# Option 1 (A bit slower in runtime, but more universal)

## Localization file
Each locale should have own .lilka_loc file or something similar. As a format could be used ini (I think this one would be better).

## Storage
Potential place for storing localization files is our /spiffs filesystem, which isn't really utilized for now and could be used even without sdcard present.

## Load
On boot Keira loads parameter from NVS storage, which refers to path of localization file to load.
Firmware should have a fallback translation strings, in case language file don't have all values, or redefine only part of them, those fallback strings loaded first, then rewritten.

## Persistence in memory
Cause amount of strings/keys gonna be huge, and all the time comparing those key_names would be really problematic, while seeking needed value,  suggest using some hashing function, make it work only in compile time, mb some minimal preprocessing of language file before actual feeding it to lilka, this would make all faster.

# Option 2 (Fast, less universal, controllable by maintainers in future)

Store all language files as headers, provide LANG parameter on compile, this won't allow
changing language in runtime, which is maybe not that bad mentioning this wouldn't take any space in memory at all :)
## Headers example
```cpp
// file:ukrainian.h
#ifdef LANG_UA
#define LANG_OP_SUCCESS "Операцію успішно виконано."

#endif

// file:english.h
#ifdef LANG_EN
#define LANG_OP_SUCCESS "Operation success"

#endif
```

Closed 2025-07-12.

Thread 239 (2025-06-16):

Issue with online watch schematics/pcb

frostmorn, 2025-06-16:
Need to update links here cause of moving hardware to another repository.
Probably move docs to another repo as well, so, made it in a new repo?

== > https://docs.lilka.dev/uk/latest/hardware/schematics/

Closed 2025-06-18.

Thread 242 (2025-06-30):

Capture Screenshot via START + SELECT Shortcut

bossly, 2025-06-30:
With a press of **START** + **SELECT** buttons simultaneously to take a screenshot of the current display. The screenshot should be saved automatically to the SD card (if available) in either .png or .bmp format, so that I can easily capture and review the current UI or machine state.

**Notes:**

- If an SD card is present, the screenshot is saved to a predefined folder (e.g., /screenshots/).
- If no SD card is available, the action should either be ignored silently or notify the user (based on available UI/UX design patterns)
- Filenames should be unique (e.g., timestamped or sequential) to prevent overwriting.
- Format selection (.png or .bmp) can be determined by system settings or hardcoded based on library support.
- Ensure non-blocking operation to avoid freezing the UI.

frostmorn, 2025-06-30:
well, it's kind a already implemented feature, and should work from the box, so what's your point 👀

bossly, 2025-07-01:
oh, it was just an idea. i'm sorry, did realize it there already.

Closed 2025-07-01.

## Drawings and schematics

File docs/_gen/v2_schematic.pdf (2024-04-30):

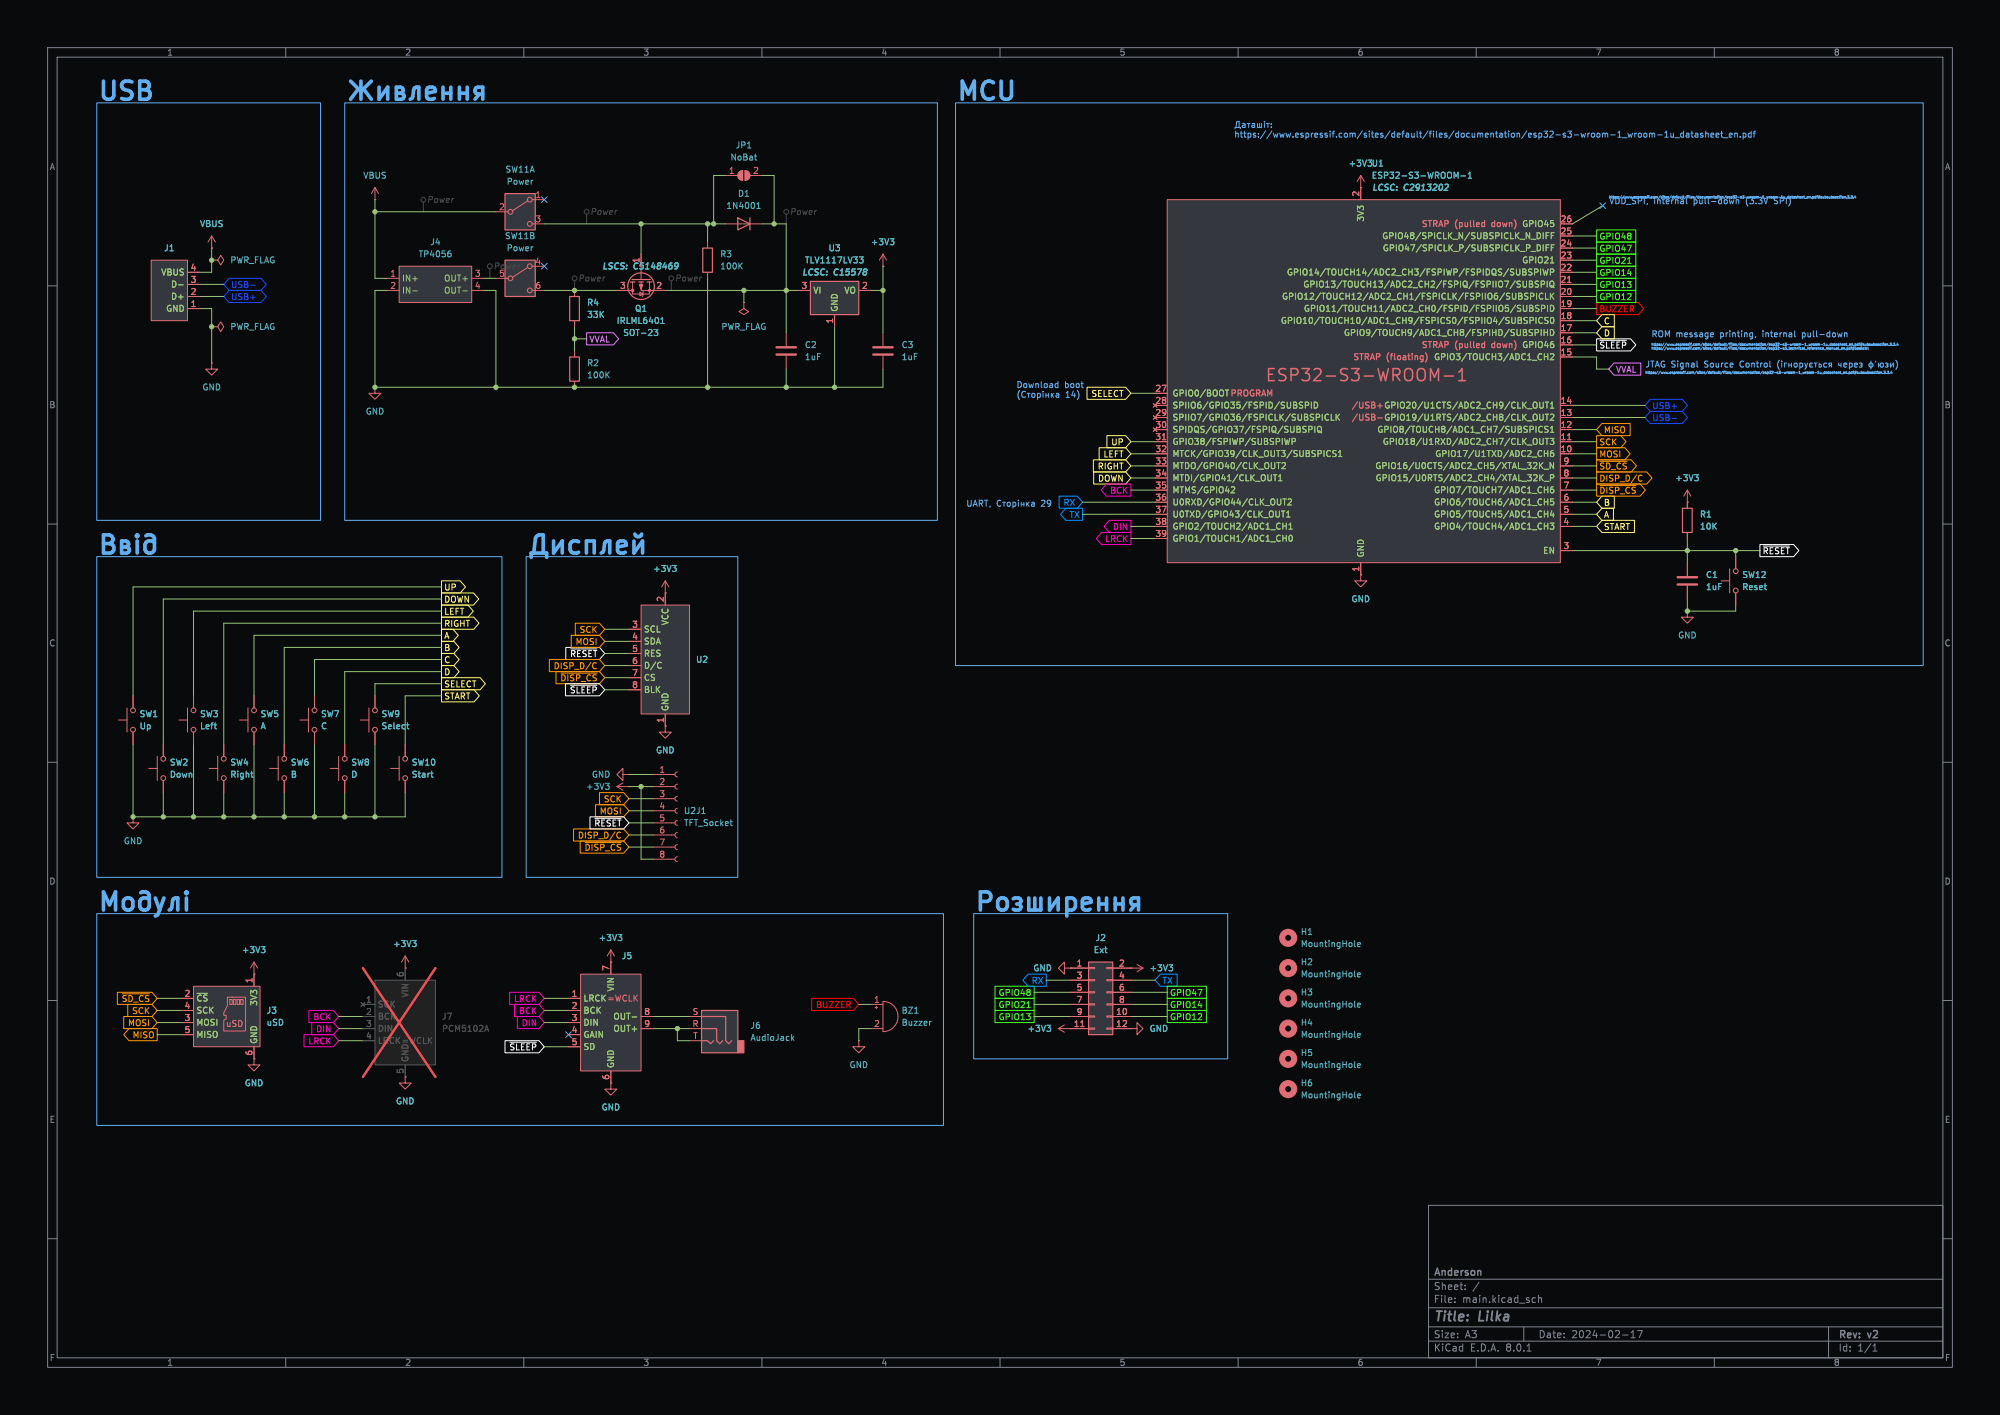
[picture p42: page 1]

MCU
STRAP (floating)STRAP (pulled down) STRAP (pulled down) GND

https://www.espressif.com/sites/default/files/documentation/esp32-s3-wroom-1_wroom-1u_datasheet_en.pdf
U1ESP32-S3-WROOM-1 LCSC: C2913202 GND

2 GPIO12/TOUCH12/ADC2_CH1/FSPICLK/FSPIIO6/SUBSPICLK 20 GPIO13/TOUCH13/ADC2_CH2/FSPIQ/FSPIIO7/SUBSPIQ 21 GPIO14/TOUCH14/ADC2_CH3/FSPIWP/FSPIDQS/SUBSPIWP 22 GPIO21 23 GPIO47/SPICLK_P/SUBSPICLK_P_DIFF 24 GPIO48/SPICLK_N/SUBSPICLK_N_DIFF 25 GPIO45 26 GPIO0/BOOT 27 EN 3 GPIO38/FSPIWP/SUBSPIWP 31 MTCK/GPIO39/CLK_OUT3/SUBSPICS1 32 MTDO/GPIO40/CLK_OUT2 33 MTDI/GPIO41/CLK_OUT1 34 MTMS/GPIO42 35 U0RXD/GPIO44/CLK_OUT2 36 U0TXD/GPIO43/CLK_OUT1 37 GPIO2/TOUCH2/ADC1_CH1 38 GPIO1/TOUCH1/ADC1_CH0 39 GPIO4/TOUCH4/ADC1_CH3 4 GPIO5/TOUCH5/ADC1_CH4 5 GPIO6/TOUCH6/ADC1_CH5 6 GPIO7/TOUCH7/ADC1_CH6 7 GPIO15/U0RTS/ADC2_CH4/XTAL_32K_P 8 GPIO16/U0CTS/ADC2_CH5/XTAL_32K_N 9 GPIO19/U1RTS/ADC2_CH8/CLK_OUT2 13 GPIO20/U1CTS/ADC2_CH9/CLK_OUT1 14 SPIIO6/GPIO35/FSPID/SUBSPID 28 SPIIO7/GPIO36/FSPICLK/SUBSPICLK 29 SPIDQS/GPIO37/FSPIQ/SUBSPIQ 30 U1ESP32-S3-WROOM-1 LCSC: C2913202 D1

2 GPIO12/TOUCH12/ADC2_CH1/FSPICLK/FSPIIO6/SUBSPICLK 20 GPIO13/TOUCH13/ADC2_CH2/FSPIQ/FSPIIO7/SUBSPIQ 21 GPIO14/TOUCH14/ADC2_CH3/FSPIWP/FSPIDQS/SUBSPIWP 22 GPIO21 23 GPIO47/SPICLK_P/SUBSPICLK_P_DIFF 24 GPIO48/SPICLK_N/SUBSPICLK_N_DIFF 25 GPIO45 26 GPIO0/BOOT 27 EN 3 GPIO38/FSPIWP/SUBSPIWP 31 MTCK/GPIO39/CLK_OUT3/SUBSPICS1 32 MTDO/GPIO40/CLK_OUT2 33 MTDI/GPIO41/CLK_OUT1 34 MTMS/GPIO42 35 U0RXD/GPIO44/CLK_OUT2 36 U0TXD/GPIO43/CLK_OUT1 37 GPIO2/TOUCH2/ADC1_CH1 38 GPIO1/TOUCH1/ADC1_CH0 39 GPIO4/TOUCH4/ADC1_CH3 4 GPIO5/TOUCH5/ADC1_CH4 5 GPIO6/TOUCH6/ADC1_CH5 6 GPIO7/TOUCH7/ADC1_CH6 7 GPIO15/U0RTS/ADC2_CH4/XTAL_32K_P 8 GPIO16/U0CTS/ADC2_CH5/XTAL_32K_N 9 GPIO19/U1RTS/ADC2_CH8/CLK_OUT2 13 GPIO20/U1CTS/ADC2_CH9/CLK_OUT1 14 SPIIO6/GPIO35/FSPID/SUBSPID 28 SPIIO7/GPIO36/FSPICLK/SUBSPICLK 29 SPIDQS/GPIO37/FSPIQ/SUBSPIQ 30 GND

1 GPIO17/U1TXD/ADC2_CH6 10 GPIO18/U1RXD/ADC2_CH7/CLK_OUT3 11 GPIO8/TOUCH8/ADC1_CH7/SUBSPICS1 12 GPIO3/TOUCH3/ADC1_CH2 15 GPIO46 16 GPIO9/TOUCH9/ADC1_CH8/FSPIHD/SUBSPIHD 17 GPIO10/TOUCH10/ADC1_CH9/FSPICS0/FSPIIO4/SUBSPICS0 18 GPIO11/TOUCH11/ADC2_CH0/FSPID/FSPIIO5/SUBSPID 19 3V3

https://www.espressif.com/sites/default/files/documentation/esp32-s3-wroom-1_wroom-1u_datasheet_en.pdf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 JTAG Signal Source Control þÿ(V3=>@CTBLAO þÿG5@57 þÿD'N78)

1 VO 2 VI 3 U3 TLV1117LV33 LCSC: C15578 GND

File: main.kicad_sch Sheet: / Anderson GND

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

https://www.espressif.com/sites/default/files/documentation/esp32-s3_technical_reference_manual_en.pdf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 UART, þÿ!B>@V=:0 29 Download boot þÿ(!B>@V=:0 14)

2 SCL 3 SDA 4 RES 5 D/C 6 CS 7 BLK 8 U2 +3V3 GND

2 SCL 3 SDA 4 RES 5 D/C 6 CS 7 BLK 8 +3V3 GND

H4 MountingHole H1 MountingHole H3 MountingHole H2 MountingHole GND GND
+3V3 GND

1 ~{CS} 2 MOSI 3 SCK 4 MISO 5 GND

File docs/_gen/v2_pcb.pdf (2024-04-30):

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

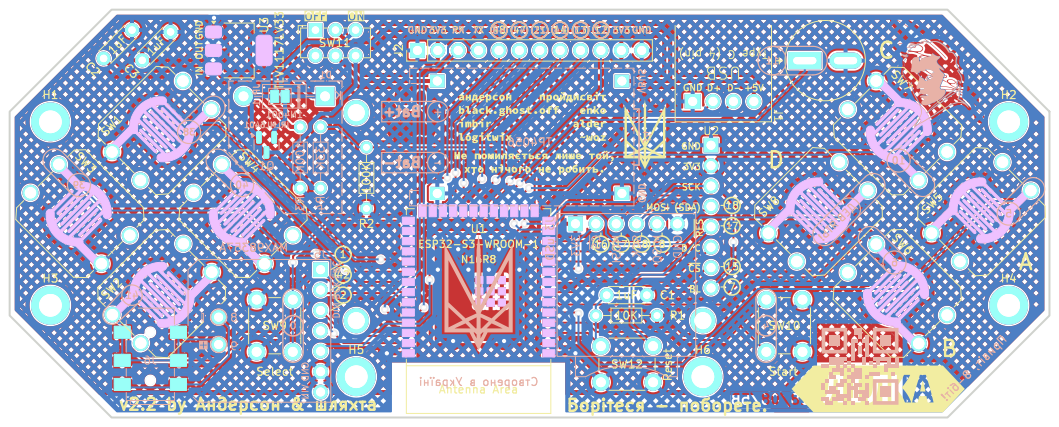
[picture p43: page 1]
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

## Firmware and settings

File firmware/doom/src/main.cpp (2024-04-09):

#include <Arduino.h>
#include "lilka.h"
#include "doom_splash.h"

extern "C" {
#include "i_sound.h"
#include "doomkeys.h"
#include "doomgeneric.h"
#include "d_alloc.h"
#include "doomstat.h"
}

extern void doomgeneric_Create(int argc, char** argv);
extern void doomgeneric_Tick();

typedef struct {
    uint8_t key;
    bool pressed;
} doomkey_t;

doomkey_t keyqueue[16];
uint16_t keyqueueRead = 0;
uint16_t keyqueueWrite = 0;
uint64_t lastRender = 0;

SemaphoreHandle_t inputMutex;
SemaphoreHandle_t backBufferMutex;
EventGroupHandle_t backBufferEvent;
TaskHandle_t gameTaskHandle;
TaskHandle_t drawTaskHandle;

uint32_t* backBuffer = NULL;

sound_module_t DG_sound_module;
extern sound_module_t sound_module_I2S;
extern sound_module_t sound_module_Buzzer;
extern sound_module_t sound_module_NoSound;
int use_libsamplerate = 0;
float libsamplerate_scale = 0.65f;

void gameTask(void* arg);
void drawTask(void* arg);

char nextWeaponKey = '2';

void buttonHandler(lilka::Button button, bool pressed) {
    xSemaphoreTake(inputMutex, portMAX_DELAY);
    doomkey_t* key = &keyqueue[keyqueueWrite];
    switch (button) {
        case lilka::Button::UP:
            key->key = KEY_UPARROW;
            break;
        case lilka::Button::DOWN:
            key->key = KEY_DOWNARROW;
            break;
        case lilka::Button::LEFT:
            key->key = KEY_LEFTARROW;
            break;
        case lilka::Button::RIGHT:
            key->key = KEY_RIGHTARROW;
            break;
        // No strafing
        case lilka::Button::A:
            key->key = KEY_FIRE;
            break;
        case lilka::Button::B:
            key->key = KEY_USE;
            break;
        case lilka::Button::C:
            key->key = KEY_TAB;
            break;
        case lilka::Button::D:
            // Cycle weapons
            key->key = nextWeaponKey;
            break;
        // Strafing experiment
        // case lilka::Button::A:
        //     key->key = KEY_STRAFE_R;
        //     break;
        // case lilka::Button::B:
        //     key->key = KEY_FIRE;
        //     break;
        // case lilka::Button::C:
        //     key->key = KEY_USE;
        //     break;
        // case lilka::Button::D:
        //     key->key = KEY_STRAFE_L;
        //     break;
        case lilka::Button::SELECT:
            key->key = KEY_ESCAPE;
            break;
        case lilka::Button::START:
            key->key = KEY_ENTER;
            break;
        default:
            // TODO: Log warning?
            xSemaphoreGive(inputMutex);
            return;
    }

    key->pressed = pressed;
    keyqueueWrite = (keyqueueWrite + 1) % 16;
    xSemaphoreGive(inputMutex);
}

void setup() {
    lilka::display.setSplash(doom_splash);
    lilka::begin();

    inputMutex = xSemaphoreCreateMutex();
    xSemaphoreGive(inputMutex);
    backBufferMutex = xSemaphoreCreateMutex();
    xSemaphoreGive(backBufferMutex);
    backBufferEvent = xEventGroupCreate();
    xEventGroupClearBits(backBufferEvent, 1);

    int argc = 3;
    char arg[] = "doomgeneric";
    char arg2[] = "-iwad";
    char arg3[64];

    // Get firmware arg
    String firmwareFile = lilka::multiboot.getFirmwarePath();
    lilka::serial_log("Firmware file: %s", firmwareFile.c_str());
    String firmwareDir;
    if (firmwareFile.length()) {
        // Get directory from firmware file
        int lastSlash = firmwareFile.lastIndexOf('/');
        firmwareDir = firmwareFile.substring(0, lastSlash);
        if (firmwareDir.length() == 0) {
            firmwareDir = "/";
        }
    } else {
        firmwareDir = "/";
    }

    bool found = false;
    // Find the WAD file
    File root = SD.open(firmwareDir.c_str());
    File file;
    while ((file = root.openNextFile())) {
        if (file.isDirectory()) {
            file.close();
            continue;
        }
        String name(file.name());
        name.toLowerCase();
        lilka::serial_log("Checking file: %s", name.c_str());
        if (name.startsWith("doom") && name.endsWith(".wad")) {
            if (firmwareDir.endsWith("/")) {
                firmwareDir = firmwareDir.substring(0, firmwareDir.length() - 1);
            }
            strcpy(arg3, (lilka::fileutils.getSDRoot() + firmwareDir + "/" + file.name()).c_str());
            lilka::serial_log("Found .WAD file: %s\n", arg3);
            found = true;
            file.close();
            break;
        }
        file.close();
    }
    root.close();
    if (!found) {
        lilka::Alert alert("Doom", "Не знайдено .WAD-файлу на картці пам'яті");
        alert.draw(&lilka::display);
        while (!alert.isFinished()) {
            alert.update();
        }
        esp_restart();
    }
    char* argv[3] = {arg, arg2, arg3};

    // Select sound device
    lilka::Menu soundMenu("Звуковий пристрій");
    soundMenu.addItem("I2S DAC");
    soundMenu.addItem("П'єзо-динамік");
    soundMenu.addItem("Без звуку");
    lilka::Canvas canvas;
    while (!soundMenu.isFinished()) {
        soundMenu.update();
        soundMenu.draw(&canvas);
        lilka::display.drawCanvas(&canvas);
    }
    int soundDevice = soundMenu.getCursor();

    if (soundDevice == 0) {
        // I2S DAC
        DG_sound_module = sound_module_I2S;
    } else if (soundDevice == 1) {
        // Buzzer
        DG_sound_module = sound_module_Buzzer;
    } else {
        // No sound
        DG_sound_module = sound_module_NoSound;
    }

    lilka::display.fillScreen(lilka::colors::Black);

    DG_printf("Doomgeneric starting, WAD file: %s", arg3);

    D_AllocBuffers();
    // Back buffer must be allocated before doomgeneric_Create since it calls DG_DrawFrame
    backBuffer = static_cast<uint32_t*>(malloc(DOOMGENERIC_RESX * DOOMGENERIC_RESY * 4));
    doomgeneric_Create(argc, argv);
    if (backBuffer == NULL) {
        DG_printf("Failed to allocate back buffer\n");
        esp_restart();
    }

    lilka::controller.setGlobalHandler(buttonHandler);

    // while (1) {
    //     doomgeneric_Tick();
    // }

    Serial.println("Ready, starting tasks");

    xTaskCreatePinnedToCore(gameTask, "gameTask", 32768, NULL, 1, &gameTaskHandle, 0);
    xTaskCreatePinnedToCore(drawTask, "drawTask", 32768, NULL, 1, &drawTaskHandle, 1);

    while (1) {
        vTaskDelay(1000 / portTICK_PERIOD_MS);
    }
    // D_FreeBuffers(); // TODO - never reached
}

void gameTask(void* arg) {
    while (1) {
        doomgeneric_Tick();

        // Print free memory
        // Serial.print("Free heap: ");
        // Serial.print(ESP.getFreeHeap());

        // Print free stack
        // Serial.print("  |  Game task free stack: ");
        // Serial.println(uxTaskGetStackHighWaterMark(NULL));

        if (playeringame[consoleplayer]) {
            // We have a player (TODO: might be demo)
            const player_t* plyr = &players[consoleplayer];
            const weapontype_t weapons[NUMWEAPONS] = {
                wp_fist,
                wp_chainsaw,
                wp_pistol,
                wp_shotgun,
                wp_supershotgun,
                wp_chaingun,
                wp_missile,
                wp_plasma,
                wp_bfg,
            };
            const int weaponKeys[NUMWEAPONS] = {'1', '1', '2', '3', '3', '4', '5', '6', '7'};
            int currentWeaponIndex;
            for (int i = 0; i < NUMWEAPONS; i++) {
                if (plyr->readyweapon == weapons[i]) {
                    currentWeaponIndex = i;
                    break;
                }
            }
            nextWeaponKey = weaponKeys[plyr->readyweapon];
            for (int i = 1; i < NUMWEAPONS; i++) {
                int candidate = (currentWeaponIndex + i) % NUMWEAPONS;
                if (plyr->weaponowned[weapons[candidate]] && plyr->ammo[weaponinfo[weapons[candidate]].ammo]) {
                    nextWeaponKey = weaponKeys[candidate];
                    break;
                }
            }
            // Print player position
            // Serial.printf(
            //     "Player health: %d, armor: %d, ammo: %d\r\n",
            //     plyr->health,
            //     plyr->armorpoints,
            //     plyr->ammo[weaponinfo[plyr->readyweapon].ammo]
            // );
            // if (plyr->mo) {
            //     Serial.printf("Player position: %d, %d, %d\r\n", plyr->mo->x, plyr->mo->y, plyr->mo->z);
            // }
        }

        taskYIELD();
    }
}

void drawTask(void* arg) {
    while (1) {
        // Wait for buffer to be ready
        xEventGroupWaitBits(backBufferEvent, 1, pdTRUE, pdTRUE, portMAX_DELAY);
        xSemaphoreTake(backBufferMutex, portMAX_DELAY);

        // Calculate FPS
        uint64_t now = millis();
        uint64_t delta = now - lastRender;
        lastRender = now;
        lilka::display.startWrite();
        lilka::display.writeAddrWindow(0, 20, 280, 175);
        uint16_t row[280];
        for (int y = 0; y < 175; y++) {
            for (int x = 0; x < 280; x++) {
                int yy = y * 8 / 7;
                int xx = x * 8 / 7;
                uint32_t pixel = backBuffer[yy * 320 + xx];
                uint8_t r = (pixel >> 16) & 0xff;
                uint8_t g = (pixel >> 8) & 0xff;
                uint8_t b = pixel & 0xff;
                row[x] = lilka::display.color565(r, g, b);
            }
            lilka::display.writePixels(row, 280);
        }
        lilka::display.endWrite();
        lilka::display.setTextBound(0, 0, LILKA_DISPLAY_WIDTH, LILKA_DISPLAY_HEIGHT);
        lilka::display.setCursor(32, 16);
        lilka::display.setTextColor(lilka::colors::White, lilka::colors::Black);
        lilka::display.fillRect(32, 0, 64, 20, lilka::colors::Black);
        lilka::display.setFont(FONT_6x12);
        lilka::display.print(" FPS: ");
        lilka::display.print(1000 / delta);
        lilka::display.print(" ");

        xSemaphoreGive(backBufferMutex);
        taskYIELD();
    }
}

extern "C" void DG_Init() {
}

extern "C" void DG_DrawFrame() {
    // Frame is ready.
    // Acquire back buffer, swap buffers and set event
    xSemaphoreTake(backBufferMutex, portMAX_DELAY);
    uint32_t* temp = backBuffer;
    backBuffer = DG_ScreenBuffer;
    DG_ScreenBuffer = temp;
    xEventGroupSetBits(backBufferEvent, 1);
    xSemaphoreGive(backBufferMutex);
}

extern "C" void DG_SetWindowTitle(const char* title) {
    Serial.print("DG: window title: ");
    Serial.println(title);
}

extern "C" void DG_SleepMs(uint32_t ms) {
    delay(ms);
}

extern "C" uint32_t DG_GetTicksMs() {
    return millis();
}

extern "C" int DG_GetKey(int* pressed, unsigned char* doomKey) {
    xSemaphoreTake(inputMutex, portMAX_DELAY);
    int ret;
    if (keyqueueRead != keyqueueWrite) {
        const doomkey_t* key = &keyqueue[keyqueueRead];
        printf("Got key: %d, pressed: %d\n", key->key, key->pressed);
        *pressed = key->pressed;
        *doomKey = key->key;
        keyqueueRead = (keyqueueRead + 1) % 16;
        ret = 1;
    } else {
        ret = 0;
    }
    xSemaphoreGive(inputMutex);
    return ret;
}

bool hadNewLine = true;

extern "C" void DG_printf(const char* format, ...) {
    // Save string to buffer
    xSemaphoreTake(backBufferMutex, portMAX_DELAY);
    char buffer[256];
    va_list args;
    va_start(args, format);
    vsnprintf(buffer, sizeof(buffer), format, args);
    va_end(args);
    printf("[DG log] %s", buffer);
    int bottom = 280 / 2 + 150 / 2;
    lilka::display.setFont(u8g2_font_6x12_t_cyrillic);
    if (hadNewLine) {
        hadNewLine = false;
        lilka::display.fillRect(0, bottom, 240, 280 - bottom, lilka::colors::Black);
        lilka::display.setCursor(0, bottom + 10);
    }
    lilka::display.setTextBound(0, bottom, 240, 280 - bottom);
    lilka::display.print(buffer);
    for (int i = 0; i < strlen(buffer); i++) {
        if (buffer[i] == '\n') {
            hadNewLine = true;
        }
    }
    xSemaphoreGive(backBufferMutex);
}

void loop() {
}

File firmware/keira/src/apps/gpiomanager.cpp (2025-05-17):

#include "gpiomanager.h"
#include "icons/input.h"
#include "icons/output.h"

GPIOManagerApp::GPIOManagerApp() : App("GPIOManager") {
    menu.setTitle("GPIO");
    // Set default pin mode
    for (int i = 0; i < PIN_COUNT; i++) {
        pinMode(pinNo[i], pinM[i]);
    }
    // Change pin mode (cycle through INPUT/OUTPUT/PWM)
    menu.addActivationButton(lilka::Button::D);
    // Change pin value/duty cycle
    menu.addActivationButton(lilka::Button::A);
    // Change PWM frequency
    menu.addActivationButton(lilka::Button::C);
    // Back
    menu.addActivationButton(lilka::Button::B);

    // For testing purposes
    //readSpeedCompare();
}

void GPIOManagerApp::updatePWM(uint8_t pinIndex) {
    if (pinM[pinIndex] != PIN_MODE_PWM) return;

    // Configure timer and channel for this pin
    uint32_t freq = ledcSetup(ledcConfigs[pinIndex].channel, pwmFrequency[pinIndex], LEDC_TIMER_RESOLUTION);

    // update frequency for pins with same timer
    for (int i = 0; i < PIN_COUNT; i++) {
        if (ledcConfigs[i].timer == ledcConfigs[pinIndex].timer) {
            pwmFrequency[i] = pwmFrequency[pinIndex];
        }
    }

    if (freq == 0) {
        lilka::serial_log("Failed to set PWM frequency %d Hz for pin %d", pwmFrequency[pinIndex], pinNo[pinIndex]);
    }

    // Set duty cycle (0-100 to 0-1023)
    uint32_t duty = (pwmDutyCycle[pinIndex] * 1023) / 100;
    ledcWrite(ledcConfigs[pinIndex].channel, duty);
}

void GPIOManagerApp::startPWM(uint8_t pinIndex, uint8_t dutyCycle) {
    if (pinIndex >= PIN_COUNT) return;

    // Reset to default
    pinM[pinIndex] = PIN_MODE_PWM;
    pwmDutyCycle[pinIndex] = min(dutyCycle, (uint8_t)100);
    pwmFrequency[pinIndex] = PWM_DEFAULT_FREQ;

    // First attach the pin to its assigned channel
    ledcAttachPin(pinNo[pinIndex], ledcConfigs[pinIndex].channel);

    // Then configure timer and set duty cycle
    updatePWM(pinIndex);
}

void GPIOManagerApp::stopPWM(uint8_t pinIndex) {
    if (pinIndex >= PIN_COUNT) return;

    ledcDetachPin(pinNo[pinIndex]);
    digitalWrite(pinNo[pinIndex], LOW);

    pinData[pinIndex] = LOW;
    pwmFrequency[pinIndex] = 0;
    pwmDutyCycle[pinIndex] = 0;
    pinM[pinIndex] = INPUT;
    pinMode(pinNo[pinIndex], INPUT);
}

void GPIOManagerApp::readPinData() {
    uint32_t gpioValue = (REG_READ(GPIO_IN_REG));
    uint32_t gpio1Value = (REG_READ(GPIO_IN1_REG));
    // lilka::serial_log("Pin data : %s %s", getStrBits(gpioValue).c_str(), getStrBits(gpio1Value).c_str());

    for (int i = 0; i < PIN_COUNT; i++) {
        if (pinM[i] == INPUT) {
            // Only read input pins from GPIO registers
            if (pinNo[i] < 32) {
                pinData[i] = GET_BIT(gpioValue, pinNo[i]);
            } else {
                pinData[i] = GET_BIT(gpio1Value, pinNo[i] - 32);
            }
        }
        // PWM pins are handled by hardware LEDC
    }
    // for (int i = 0; i < PIN_COUNT; i++) {
    //     if (pinData[i] != digitalRead(pinNo[i])) lilka::serial_err("Pin validation failed");
    // }
}

void GPIOManagerApp::run() {
    while (1) {
        while (!menu.isFinished()) {
            int16_t lastPos = menu.getCursor();
            menu.clearItems();
            readPinData();

            for (int i = 0; i < PIN_COUNT; i++) {
                String modeStr;
                String valueStr;

                switch (pinM[i]) {
                    case PIN_INPUT:
                        modeStr = " <- IN";
                        valueStr = pinData[i] == HIGH ? "HIGH" : "LOW";
                        break;
                    case PIN_OUTPUT:
                        modeStr = " -> OUT";
                        valueStr = pinData[i] == HIGH ? "HIGH" : "LOW";
                        break;
                    case PIN_MODE_PWM:
                        modeStr = " ~ PWM";
                        if (pwmFrequency[i] >= 1000) {
                            valueStr = "[" + String(pwmFrequency[i] / 1000) + "kHz] " + String(pwmDutyCycle[i]) + "%";
                        } else {
                            valueStr = "[" + String(pwmFrequency[i]) + "Hz] " + String(pwmDutyCycle[i]) + "%";
                        }
                        break;
                }

                menu.addItem(String(pinNo[i]) + modeStr, pinM[i] == INPUT ? &input_img : &output_img, 0, valueStr);
            }

            menu.setCursor(lastPos);
            // Do menu redraw
            menu.update();
            menu.draw(canvas);
            queueDraw();
        }
        lilka::serial_log("Menu finished");
        int16_t curPos = menu.getCursor();
        if (curPos == PIN_COUNT) break;
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

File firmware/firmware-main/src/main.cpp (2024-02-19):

#include <esp_wifi.h>
#include <esp_task_wdt.h>
#include <FFat.h>
#include <SPIFFS.h>
#include <SD.h>
#include <SD_MMC.h>

#include <Arduino_GFX_Library.h>

#include "nes/hw_config.h"

extern "C" {
#include <nofrendo.h>
}

#include <lilka.h>
#include <lilka/icons/file.h>
#include <lilka/icons/folder.h>
#include <lilka/icons/nes.h>

extern void demo_lines();
extern void demo_disc();
extern void demo_epilepsy();
extern void demo_ball();
extern void demo_letris();
extern void demo_user_spi();
extern void demo_scan_i2c();
extern int lua_run(String path);

void setup() {
    lilka::begin();
}

void demos_menu() {
    void (*demo_funcs[])() = {
        demo_lines, demo_disc, demo_ball, demo_epilepsy, demo_letris, demo_user_spi, demo_scan_i2c, 0,
    };

    String demos[] = {
        "Лінії", "Шайба", "М'ячик", "Епілепсія", "Летріс", "Тест SPI", "I2C-сканер", "<< Назад",
    };
    int count = sizeof(demos) / sizeof(demos[0]);
    int cursor = 0;
    while (1) {
        cursor = lilka::ui_menu("Оберіть демо:", demos, count, cursor);
        if (!demo_funcs[cursor]) {
            return;
        }
        demo_funcs[cursor]();
    }
}

void select_file(String path) {
    if (path.endsWith(".rom") || path.endsWith(".nes")) {
        char *argv[1];
        char fullFilename[256];
        strcpy(fullFilename, path.c_str());
        argv[0] = fullFilename;

        TaskHandle_t idle_0 = xTaskGetIdleTaskHandleForCPU(0);
        esp_task_wdt_delete(idle_0);

        Serial.print("NoFrendo start! Filename: ");
        Serial.println(argv[0]);
        nofrendo_main(1, argv);
        Serial.println("NoFrendo end!\n");
    } else if (path.endsWith(".bin")) {
        int error;
        lilka::LoaderHandle *handle = lilka::loader.createHandle(path);
        error = handle->start();
        if (error) {
            lilka::ui_alert("Помилка", String("Етап: 1\nКод: ") + error);
            return;
        }
        lilka::display.fillScreen(lilka::display.color565(0, 0, 0));
        lilka::display.setTextColor(lilka::display.color565(255, 255, 255), lilka::display.color565(0, 0, 0));
        lilka::display.setFont(u8g2_font_10x20_t_cyrillic);
        lilka::display.setTextBound(16, 0, LILKA_DISPLAY_WIDTH - 16, LILKA_DISPLAY_HEIGHT);
        while ((error = handle->process()) != 0) {
            float progress = (float)handle->getBytesWritten() / handle->getBytesTotal();
            lilka::display.setCursor(16, LILKA_DISPLAY_HEIGHT / 2 - 10);
            lilka::display.printf("Завантаження (%d%%)\n", (int)(progress * 100));
            lilka::display.println(path);
            String buf = String(handle->getBytesWritten()) + " / " + handle->getBytesTotal();
            int16_t x, y;
            uint16_t w, h;
            lilka::display.getTextBounds(buf, lilka::display.getCursorX(), lilka::display.getCursorY(), &x, &y, &w, &h);
            lilka::display.fillRect(x, y, w, h, lilka::display.color565(0, 0, 0));
            lilka::display.println(buf);
            lilka::display.fillRect(16, LILKA_DISPLAY_HEIGHT / 2 + 40, LILKA_DISPLAY_WIDTH - 32, 5, lilka::display.color565(64, 64, 64));
            lilka::display.fillRect(16, LILKA_DISPLAY_HEIGHT / 2 + 40, (LILKA_DISPLAY_WIDTH - 32) * progress, 5, lilka::display.color565(255, 128, 0));
        }
        if (error) {
            lilka::ui_alert("Помилка", String("Етап: 2\nКод: ") + error);
            return;
        }
        error = handle->finishAndReboot();
        if (error) {
            lilka::ui_alert("Помилка", String("Етап: 3\nКод: ") + error);
            return;
        }
    } else if (path.endsWith(".lua")) {
        int retCode = lua_run(path);
        lilka::ui_alert("Lua", String("Код завершення: ") + retCode);
    } else {
        // Get file size
        FILE *file = fopen(path.c_str(), "r");
        if (!file) {
            lilka::ui_alert("Помилка", "Не вдалося відкрити файл");
            return;
        }
        fseek(file, 0, SEEK_END);
        long size = ftell(file);
        fclose(file);
        lilka::ui_alert(path, String("Розмір:\n") + size + " байт");
    }
}

void sd_browser_menu(String path) {
    if (!lilka::sdcard.available()) {
        lilka::ui_alert("Помилка", "SD-карта не знайдена");
        return;
    }

    lilka::Entry entries[32];
    int numEntries = lilka::sdcard.listDir(path, entries);

    if (numEntries == -1) {
        lilka::ui_alert("Помилка", "Не вдалося прочитати директорію");
        return;
    }

    String filenames[32];
    const menu_icon_t *icons[32];
    for (int i = 0; i < numEntries; i++) {
        filenames[i] = entries[i].name;
        icons[i] = entries[i].type == lilka::EntryType::ENT_DIRECTORY ? &folder : (entries[i].name.endsWith(".rom") || entries[i].name.endsWith(".nes")) ? &nes : &file;
    }
    filenames[numEntries++] = "<< Назад";
    icons[numEntries - 1] = 0;

    int cursor = 0;
    while (1) {
        cursor = lilka::ui_menu(String("SD: ") + path, filenames, numEntries, cursor, icons);
        if (cursor == numEntries - 1) {
            return;
        }
        if (entries[cursor].type == lilka::EntryType::ENT_DIRECTORY) {
            sd_browser_menu(path + entries[cursor].name + "/");
        } else {
            select_file(lilka::sdcard.abspath(path + entries[cursor].name));
        }
    }
}

void spiffs_browser_menu() {
    if (!lilka::filesystem.available()) {
        lilka::ui_alert("Помилка", "SPIFFS не підтримується");
        return;
    }

    String filenames[32];
    int numEntries = lilka::filesystem.readdir(filenames);

    if (numEntries == -1) {
        lilka::ui_alert("Помилка", "Не вдалося прочитати корінь SPIFFS");
        return;
    }

    const menu_icon_t *icons[32];
    for (int i = 0; i < numEntries; i++) {
        icons[i] = (filenames[i].endsWith(".rom") || filenames[i].endsWith(".nes")) ? &nes : &file;
    }
    filenames[numEntries++] = "<< Назад";
    icons[numEntries - 1] = 0;

    int cursor = 0;
    while (1) {
        cursor = lilka::ui_menu(String("SPIFFS"), filenames, numEntries, cursor, icons);
        if (cursor == numEntries - 1) {
            return;
        }
        select_file(lilka::filesystem.abspath(filenames[cursor]));
    }
}
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

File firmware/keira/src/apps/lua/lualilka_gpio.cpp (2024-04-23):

#include "lualilka_gpio.h"

static int lualilka_gpio_setMode(lua_State* L) {
    int pin = luaL_checkinteger(L, 1);
    int mode = luaL_checkinteger(L, 2);
    pinMode(pin, mode);
    return 0;
}

static int lualilka_gpio_write(lua_State* L) {
    int pin = luaL_checkinteger(L, 1);
    int value = luaL_checkinteger(L, 2);
    digitalWrite(pin, value);
    return 0;
}

static int lualilka_gpio_read(lua_State* L) {
    int pin = luaL_checkinteger(L, 1);
    int value = digitalRead(pin);
    lua_pushinteger(L, value);
    return 1;
}

static int lualilka_gpio_analogRead(lua_State* L) {
    int pin = luaL_checkinteger(L, 1);
    int value = analogRead(pin);
    lua_pushinteger(L, value);
    return 1;
}

static const struct luaL_Reg lualilka_gpio[] = {
    {"set_mode", lualilka_gpio_setMode},
    {"write", lualilka_gpio_write},
    {"read", lualilka_gpio_read},
    {"analog_read", lualilka_gpio_analogRead},
    {NULL, NULL},
};

int lualilka_gpio_register(lua_State* L) {
    luaL_newlib(L, lualilka_gpio);
    // Add LOW and HIGH constants
    lua_pushinteger(L, LOW);
    lua_setfield(L, -2, "LOW");
    lua_pushinteger(L, HIGH);
    lua_setfield(L, -2, "HIGH");
    // Add INPUT, OUTPUT, and INPUT_PULLUP constants
    lua_pushinteger(L, INPUT);
    lua_setfield(L, -2, "INPUT");
    lua_pushinteger(L, OUTPUT);
    lua_setfield(L, -2, "OUTPUT");
    lua_pushinteger(L, INPUT_PULLUP);
    lua_setfield(L, -2, "INPUT_PULLUP");
    lua_pushinteger(L, INPUT_PULLDOWN);
    lua_setfield(L, -2, "INPUT_PULLDOWN");
    lua_setglobal(L, "gpio");
    return 0;
}

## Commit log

2024-02-03 lilka: initial stuff
    [12mm Push Button with Cap.STEP, ALPHA-RD901F-40.step, Display 1.69 ST7789V2.stp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]
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2024-02-03 v2 routing just like that?!
    [main.kicad_pcb]
2024-02-05 kicad: use external DC-DC
    [main.kicad_sch]
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2024-02-07 lib: add LilkaBus which fixes moononournation/Arduino_GFX#433
2024-02-07 lib: add menu icons, fix alert rendering, make SD functions more tolerant to extra slashes
    [main.cpp]
2024-02-08 kicad-v2: proper pin alignment & colors
    [main.kicad_sch]
2024-02-08 kicad-v2: new layout with jumpers
    [main.kicad_pcb, main.kicad_sch]
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2024-02-08 kicad-v2: routed PCB prototype
    [main.kicad_pcb]
2024-02-08 kicad-v2: routed PCB prototype (add unrouted version)
    [main_unrouted.kicad_pcb]
2024-02-08 kicad-v2: add MAX98357A slot
    [main.kicad_pcb, main.kicad_sch, main_unrouted.kicad_pcb]
2024-02-08 tools: fix auto-generated file header comment
    [main.cpp]
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2024-02-09 demo: fix cursor default value
    [main.cpp]
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2024-02-09 kicad-v2: add silkscreens to LCD & PCM5102A
    [main.kicad_pcb]
2024-02-09 kicad-v2: improve PCB button & uSD routing (via count = 18: manual routing for buttons & SD card)
    [main.kicad_pcb, main.kicad_sch, main_unrouted.kicad_pcb]
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2024-02-09 kicad-v2: fix WROOM label
    [main.kicad_pcb]
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2024-02-09 lib: add menu scrolling demo: fix I2C scanner
2024-02-11 doom: add ozkl's doom port
    [doom.csv]
2024-02-11 doom: PoC of DOOM on Lilka v2
    [doom.csv]
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2024-02-14 doom: fix memory allocation for visplayes lib: add setGlobalHandler for controller
    [main.cpp]
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2024-02-15 kicad-v2: 8 button PoC
    [main.kicad_pcb, main.kicad_sch, tp4056_pcb_asm.stp]
2024-02-15 kicad-v2: rotated ESP32-S3 in schematic
    [main.kicad_pcb, main.kicad_sch]
2024-02-15 kicad-v2: add ext header
    [main.kicad_pcb, main.kicad_sch]
2024-02-15 kicad-v2: move pin header to center
    [main.kicad_pcb]
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2024-02-15 kicad-v2: copper fill "glasses"
    [main.kicad_pcb]
2024-02-15 kicad-v2: less rat nests
    [main.kicad_pcb, main.kicad_sch]
2024-02-15 kicad-v2: GNDBUS fix
    [main.kicad_pcb, main.kicad_sch]
2024-02-15 kicad-v2: fix USB (finally)
    [main.kicad_pcb]
2024-02-15 kicad-v2: fix USB (again)
    [main.kicad_pcb]
2024-02-15 kicad-v2: move power section down
    [main.kicad_pcb]
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2024-02-16 lilka-v2: fix power switch
    [main.kicad_pcb, main.kicad_sch]
2024-02-16 kicad-v2: battery ADC & routing (8 vias)
    [main.kicad_pcb, main.kicad_sch]
2024-02-16 kicad-v2: tweak lilka label corners
    [main.kicad_pcb, main.kicad_sch]
2024-02-16 kicad-v2: add reset button, add 3d models
    [USB-C board JRC-B023.step, main.kicad_pcb, main.kicad_sch]
2024-02-16 lilka-v2: remove old gerber files
    [main-Board.gbr, main-Bot.gbr, main-BotMask.gbr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]
2024-02-16 lib: v2 battery ADC, buzzer & C/D buttons demo: v1/v2 envs doom: v1/v2 envs global: do not align comments (clang-format)
2024-02-17 kicad-v2: pads for buttons
    [main.kicad_pcb]
2024-02-17 kicad-v2: fix issues with silkscreen overlaps, make select/start buttons symmetrical, switch C & D signals
    [main.kicad_pcb, main.kicad_sch]
2024-02-17 boards: add lilka_v2 board lib: fix C/D pin numbers
2024-02-18 demo: set LILKA_BREADBOARD since 80 MHz SPI is too much for breadboards...
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2024-02-18 kicad-v2: remove 2 top pads from TFT display, move uSD card higher
    [main.kicad_pcb, main.kicad_sch]
2024-02-18 kicad-v2: best layout & routing so far
    [main.kicad_pcb]
2024-02-19 global: cleanup overall monorepo stuff
    [12mm Push Button with Cap.STEP, ALPHA-RD901F-40.step, Display 1.69 ST7789V2.stp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]
2024-02-19 kicad-v2: add prefixes to firmwares
    [doom.csv]
2024-02-19 global: more cleanup - sdk dir etc
    [doom.csv]
2024-02-19 kicad-v2: update copper fill
    [main.kicad_pcb]
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2024-02-19 lib: fix library.json firmware: add firmware template
    [main.cpp]
2024-02-19 main: add image loading & drawing to Lua, update Lua demo, fix console logs
    [lua_runner.cpp]
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2024-02-20 main: cleanup demos & Lua stuff
    [main.kicad_pcb]
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2024-02-21 doc: add docs for Loader, SPI & UI doc: add template for manual docs doc: add CONFIG_IDF_TARGET_ESP32S3 to doxygen main: fix memory leak with loader not being freed
    [main.cpp]
2024-02-21 docs: add BOM docs: make RTD theme wider kicad-v2: fix BOM generation lib: bump to 1.0.6
    [bom.ods, bom_clean.ods, main.kicad_sch]
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2024-02-23 kicad-v2: case PoC WIP
    [main-User_Case.dxf, main.kicad_pcb]
2024-02-24 lib: fix dependency on Arduino_GFX lib: bump version
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2024-02-26 doc: update BOM\ndoc: fix example of state counter
2024-02-26 doc: fix BOM
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2024-02-27 kicad-v2: LCSC part numbers
    [main.kicad_sch]
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2024-02-28 doc: update BOM kicad-v2: set C2/C3 to 1uF
    [main.kicad_pcb, main.kicad_sch]
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2024-02-29 lib: fix image drawing bug main: add more icons
    [main.cpp]
2024-02-29 main: fix Lua Live mode main: WIP runner game lib: add support for 32-bit BMP images
    [main.cpp]
2024-03-02 lib: add menu item colors lib: fix ui scrolling lib: sort filenames when listing dir
    [main.cpp]
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2024-03-03 lua: fix error reporting lua: fix math.rotate direction lua: make serial logs less noisy main: fix sd card not being ready sometimes (in Live Lua & Lua REPL)
    [main.cpp]
2024-03-03 lib: increase SD card SPI clock speed to 10 MHz (was 1 MHz) lib: fix incorrect pressed states in controller handlers
2024-03-03 lib: increase SD card SPI clock speed to 20 MHz (was 10 MHz) lib: fix incorrect pressed states in controller handlers (again)
2024-03-04 lib: fix controller state typecasts main: add menu colors & rest of icons main: show partition info
    [main.cpp]
2024-03-06 doom: auto-copy doom.bin after build for convenience lib: move fmath under lilka namespace lib: rename loader to multiloader lib: allow custom splash screens doc: fix docs
    [main.cpp]
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2024-03-08 lib: add method to draw canvas to another canvas main: fix Letris main: fix buffering in demos main: add back WiFi scanner app main: fix ServiceManager not starting services
    [launcher.cpp]
2024-03-09 main: fix few regressions with WiFi scanner & NES buttons
2024-03-09 doom: fix scaling for rotated display, update cover
    [main.cpp]
2024-03-09 global: fix code style\ngithub: add code_style workflow
    [main.cpp]
2024-03-09 hashbrown: fix code style
    [lualilka_gpio.cpp]
2024-03-10 lib: fix battery reading, add battery absence detection keira: add real battery status icon
2024-03-10 doom: fix FPS display
    [main.cpp]
2024-03-11 keira: add task creation guards lib: make buzzer melody task cleanup thread-safe
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2024-03-12 lib: allow pre-filling of input dialog lib: update extension header pin definitions keira: fix network service keira: add WiFi config app keira: cleanup root menus, rename system utils to settings ke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
    [launcher.cpp]
2024-03-15 doc: fix BOM kicad: add normally closed JP2 that joins GNDBUS & GND kicad: fix swapped labels on resistors kicad: rename TLV1117-33 to TLV1117LV33
    [main.kicad_pcb, main.kicad_sch]
2024-03-17 kicad: link copper fills to power lines kicad: remove copper islands kicad: add pin number markers kicad: move references outside of components
    [main.kicad_pcb]
2024-03-17 keira: fix v1 regressions lib: fix v1 regressions lib: fix FreeRTOS includes not working for C3
    [v1_partitions.csv]
2024-03-17 keira: fix code style
    [launcher.cpp]
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2024-03-20 Add FTP Server app, make app class list cleaner (#12)
    keira: add FTP Server app
    keira: cleanup APP macros
    keira: cppcheck for ESP32FtpServer
    keira: improve FTP Server welcome screen
    keira: fix out-of-bounds access in launcher
    keira: fix FTP server banner (220-)
    keira: make password a static var
    keira: move mJS & FTP server into lib folder
    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
    [launcher.cpp]
2024-03-20 Store firmware path when running firmwares from SD card (#10)
    lib: store firmware path when starting multiboot
    lib: cleanup logs
    lib: do not clear firmware path from OTA partition end
    keira: show multiboot progress dialog sooner
    keira: fix SD card item selection
    keira: fix Lua demos
    doom: read firmware path from OTA
    doc: update docs on running Doom
    doc: update render -> queue_draw
    [launcher.cpp, main.cpp]
2024-03-20 lib: bump version to 1.4.0 firmware: fix sample & template firmwares
    [main.cpp]
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2024-03-22 hardware: add optional USBLC6 (closes #33) (#39)
    [main.kicad_pcb, main.kicad_sch]
2024-03-23 Hardware updates (#45)
    hardware: add lines to pin circles
    hardware: update to KiCad 8.0
    hardware: add GND/Power netclasses
    hardware: fix GND+GNDBUS jumper & LCD label positioning
    hardware: move things around
    hardware: make GND+GNDBUS jumper thicker (closes #24)
    hardware: fix collision of MAX98357 with button (closes #19)
    hardware: move display & uSD module up 0.1"
    hardware: reduce button circle grid size (closes #22)
    hardware: allow flexible buzzer sizes (closes #44)
    hardware: unroute board
    hardware: cleanup schematic
    hardware: drop buzzer resistor (closes #25)
    hardware: reduce board height
    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
    [main.kicad_pcb, main.kicad_sch]
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2024-03-25 Reduce board height to 50mm, improve routing, drop PCM5102 (#49)
    hardware: reduce PCB height to 50
    hardware: re-route board
    [main.kicad_pcb, main.kicad_sch]
2024-03-25 hardware: fix thermal reliefs, remove battery pins from TP4056
    [main.kicad_pcb, main.kicad_sch]
2024-03-25 lib: add Battery::readRawValue lib: add missing ping.h
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2024-03-27 keira: cube demo, RAM icon fix (#70)
    [launcher.cpp]
2024-03-28 Doom sound (#73)
    doom: add I2S sound driver
    doom: do not set pins for I2S (it breaks select button)
    doom: add buzzer sound driver
    doom: add sound device menu on startup
    sdk: fix multiboot not resetting firmware path
    sdk: fix default Canvas size
    sdk: cleanup code alignment
    [main.cpp]
2024-03-29 doom: fix I2S sound ring buffer out-of-bounds, improve sound queueing & volume
    [main.cpp]
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2024-03-30 hardware: add 3D models for buzzer & power switch
    [main.kicad_pcb]
2024-03-30 Backlight control, board improvements (#89)
    sdk: add backlight control pin
    sdk: fix build for V1
    keira: turn off display before entering light/deep sleep from settings
    hardware: route BL signal, decrease copper fill hatch size, move QR code, add keepouts, add net to pin 4 of regulator
    [main.kicad_pcb, main.kicad_sch]
2024-03-31 hardware: rename /BL to /SLEEP, route /SLEEP to I2S module SD input
    [main.kicad_pcb, main.kicad_sch]
2024-03-31 hardware: improve silkscreen labels
    [main.kicad_pcb]
2024-03-31 sdk: add Board class (#90)
    sdk: add Board class
    sdk: refactor ext into Board
    sdk: move power saving into Board class
    sdk: increase SD card speed to 25 MHz
    doom: fix sound causing game lags
    [launcher.cpp]
2024-04-01 hardware: add optional 3.5mm audio jack
    [main.kicad_pcb, main.kicad_sch]
2024-04-02 Weather app (#91)
    keira: add ArduinoJson
    keira: add weather app with RLE-encoded icons
    keira: add SpiRamAllocator for ArduinoJson
    keira: add Defer class
    keira: remove unneeded private fields from App (x, y, w, h)
    sdk: fix image2code var name
    sdk: add Image::newFromRLE
    global: add ignores for .nes, .wad
    [launcher.cpp]
2024-04-02 doc: add kicanvas link, remove outdated unrouted board file
    [main_unrouted.kicad_pcb]
2024-04-02 hardware: add back MCU ground pads, fix fonts & fills
    [main.kicad_pcb, main.kicad_sch]
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2024-04-03 Add marquee to long menu items, prevent menu title overflow (#88)
    sdk: add back-and-forth scrolling to menu title & long menu items (closes #85)
    sdk: link getTextBounds issue (moononournation/Arduino_GFX#460)
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2024-04-04 GPIO Manager (#92)
    keira: add GPIO manager, use REG_READ to get GPIO data
    keira: add REG_READ vs digitalRead Speed comparison
    keira: add icons
    sdk: fix menu layout, prevent menu select item background overlaping with scrollbar
    ---------
    [gpiomanager.cpp, gpiomanager.h, launcher.cpp]
2024-04-09 Single FileSystem class (#84)
    sdk: add FileUtils that replaces FileSystem
    sdk: check on repeated initialization of filesystem, fix potential bug in FileUtils::getEntryCount
    sdk: add FileUtils::getHumanFriendlySize implementation
    sdk: update Lua to match new FileUtils API
    sdk: fix root double slashes in FileUtils::getLocalPath
    sdk: add FileUtils::createSDPartTable and FileUtils::formatSD implementation
    sdk: use mutex to prevent funny stuff while partitioning/formatting card
    sdk: update docs, tweak FileUtils method/argument naming
    keira: reboot system on SD card partitioning/formatting
    keira: fix alerts to fit into ui
    keira: fix incorrect Lua dir path calculation
    Co-a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
    [launcher.cpp, main.cpp]
2024-04-09 sdk: move buzzer startup sound to buzzer module (#96)
    sdk: disable I2S ping message
    sdk: apply screen rotation early
    sdk: add Display::drawTextAligned
    sdk: add monospaced fonts
    sdk: reduce sprintf buffer size in serial
    sdk: cleanup controller code
    doom: init audio pins on startup
    keira: allow apps to select which core to run on
    global: fix clang-format search in case the binary is called clang-format-18
2024-04-13 LilTracker (#95)
    keira: add liltracker
    keira: allow apps to set their core affinity
    keira: replace mutexes with binary semaphores
    keira: fix memory corruption due to usage of WiFi methods after deallocation by liltracker
    keira: add mutex to servicemanager, start debugging network disabling
    sdk: eliminate duplication in Display and Canvas classes by moving shared code into a mixin class (GFX)
    sdk: add GFX::drawTextAligned and GFX::getTextBoundsAligned
    sdk: reduce serial_log/serial_err string buffer size
    sdk: some I2S asshattery.
    sdk: fix initial display width/height due to rotation being applied too late
    sdk: move buzzer hello tune to Buzzer class
    sdk: remove I2S ping sound
    sdk: d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
    [launcher.cpp]
2024-04-13 hardware: secret change :)
    [main.kicad_pcb]
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2024-04-14 global: add _img suffixes to icons & images to avoid naming collisions
    [gpiomanager.cpp, launcher.cpp]
2024-04-15 keira: liltracker: fix sine waveform phase shift, increase sample rate to 44100, increase mixer buf size to 512, increase DMA buf count to 4
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2024-04-15 hardware: update PCB art
    [main.kicad_pcb]
2024-04-16 ModPlayer: allow to listen music in MOD format (Amiga trackers) on Lilka (#104)
    keira: add MOD player for PCM5102/MAX98357A module
    keira: add music icon
    keira: modplayer: add buffer visualizer
    keira: modplayer: separate UI & audio into separate tasks
    keira: modplayer: fix audio tearing by buffering audio file and eliminating SPI bus contention
    keira: modplayer: add some legendary music
    sdk: add Display::color565hsv
    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
    [launcher.cpp]
2024-04-16 LilTracker synth refactoring (#105)
    keira: liltracker: add Synth
    keira: liltracker: add sink interface
    keira: liltracker: replace mixer with synth & sequencer
    keira: liltracker: add WAV render feature
    [launcher.cpp]
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2024-04-20 WiFi tweaks (including enable/disable WiFi feature) (#111)
    keira: allow to enable/disable WiFi
    keira: fix clock service stealing all CPU time when network is not available
    keira: use keira nvs namespace for network stuff
    keira: update battery icons
    keira: add telnet nvs commands
    keira: use keira namespace for weather & ftp config
    sdk: add colors to log levels
    sdk: do not deinit WiFi on startup since it's unnecessary
    [launcher.cpp]
2024-04-22 Add H5 & H6, move power switch up 0.05" (#109)
    hardware: add H5 & H6, move power switch up 0.05"
    hardware: update labels
    [main.kicad_pcb, main.kicad_sch]
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2024-04-23 doc: add docs for sdcard, wifi & transforms (closes #107) (#112)
    keira: rename imageTransform to transforms, construct transform with transforms.new()
    keira: fix FTP app crashing when WiFi is down
    keira: lua: add gpio.INPUT_PULLDOWN
    keira: fix Lua sample scripts
    [lualilka_gpio.cpp]
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2024-04-30 fix GPIO manager title menu (#114)
    [launcher.cpp]
2024-04-30 Fix case, center display, add 3rd pad to display (#113)
    hardware: update case layout, center display
    hardware: add 3rd pad to display, center display, improve fills
    hardware: update schematic PDFs
    hardware: move back trident lower
    hardware: add rounded tracks, cleanup duplicate/hidden tracks, move uSD card away from display connector
    hardware: update case
    hardware: move vias & traces further away from MCU, move MAX98357 +/- pins away from down button
    [main-User_Case.dxf, main.kicad_pcb, main_rounded.kicad_pcb]
2024-06-18 Add controller buttons combo (#116)
    * Add controller buttons combo
    * fix clang-format and cppcheck warnings
    * fix cppcheck errors
    [launcher.cpp]
2024-06-18 add new app BLE Gamepad (#115)
    * add new app BLE Gamepad
    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
    [launcher.cpp]
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2024-07-01 hardware: add v2.3 gerbers
    [main-Board.gbr, main-Bot.gbr, main-BotMask.gbr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]
2024-07-03 hardware: update v2.3 gerbers
    [main-Bot.gbr, main-BotMask.gbr, main-BotSilk.gbr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]
2024-07-25 doc: add image of successful firmware upload (thanks BohdanVR) doc: fix typos hardware: add speaker vents in case file
    [main-User_Case.dxf]
2024-07-26 hardware: add case with two bottom versions, with 18650 and without (#117)
    [Bottom_lilka_v1_18650.stl, Bottom_lilka_v1_none.stl, Top_lilka_v1.stl]
2024-07-29 hardware: change case speaker cutout pattern to dots, reduce extension header cutout size
    [main-User_Case.dxf]
2024-11-15 Update general.rst; Fix RAM size in the docs
    ESP32-S3-WROOM-1-N16R8 have 16 MB Flash and 8 MB RAM
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2024-12-17 Fixes Конфіг підключення Читання рядка
    [gps_readn.lua]
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2024-12-24 LUA API: Serial available grammar fix
    [gps_readn.lua, readwrite.lua]
2024-12-24 fix: fix cppcheck, fix namespacing
    [launcher.cpp]
2024-12-25 Global sound settings and sound menu added (conflict resolved)
    [launcher.cpp]
2024-12-25 Wrong windspeed units
    Якщо відкрити URL в браузері - то у відповіді видно, що одиниці - km/h. І з прогнозом з інших джерел співпадає.
    https://api.open-meteo.com/v1/forecast?latitude=49.8397&longitude=24.0297&current=temperature_2m,wind_speed_10m,weather_code
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2024-12-27 Fix icons for nonapp items
    [launcher.cpp]
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2024-12-28 fix: remove vscode file
    [main.cpp]
2024-12-28 Revert "fix: remove vscode file"
    This reverts commit 4b4653402c1811a16b7fc16aba2d2b15a21c9629.
    [main.cpp]
2024-12-29 set correct pin values for USE_EXT_SPI_FOR_SD macro
2025-01-02 Revert "set correct pin values for USE_EXT_SPI_FOR_SD macro"
2025-01-02 Move Lilka_v1_bom.md to correct directory
    Перемістив v1 bom в коректну директорію. Перейменував для уникнення плутанини в майбутньому.
2025-01-02 Clean up: remove extra bom
    Видалив згенерований Kicad bom файл. Декілька bom файлів складно підтримувати в актуальному стані.
    [bom.ods]
2025-01-02 Component value correction
    Прибрав зайву незрозумілу інформацію. Виправив кількість компонентів. Виправив значення конденсаторів. Посортував відповідно до наборів.
    [bom_clean.ods]
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2025-01-02 Add correct BOM
2025-01-02 Fix incorrect number of buttons
    [bom_clean.ods]
2025-01-02 Fix incorrect description
    Помилка копіпасту. В тому наборі відсутні 10мкф конденсатори
2025-01-02 Fix incorrect store link for TLV1117LV33DCYR
    [bom_clean.ods]
2025-01-03 Move fmanager to separate directory. Use callbacks. Small fix to menu to allow clear finished flag from callback. Selection mode. Status bar. Multiple files move/copy/delete
    [launcher.cpp]
2025-01-03 change "Нова папка" on "New Folder" cause keyboard wrongly works with wide characters
2025-01-05 Fix builds for keira, doom & sdk and add GHA checks (#192)
    * keira: fix incorrect LodePNG include
    ci: run firmware job on PRs & commits to main
    * ci: add sdk build workflow
    sdk: fix BLE callbacks
    * ci: fix sdk job name
    sdk: fix code style
    * sdk: pin NimBLE to 1.x
    * sdk: fix lib build
    * sdk: fix lib build
2025-01-13 Update C2, C3 value from 1uF to 10uF on main{,_rounded}.kicad_pcb
    Docs were updated on Jan 2 to these values. Assuming it was correct.
    Link: 7412343db23f ("Fix component values and count")
    [main.kicad_pcb, main_rounded.kicad_pcb]
2025-01-14 Update C2, C3 to 10uF in schematics
    [main.kicad_sch]
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2025-02-06 Use different colors of buttons in 3D viewer
    [12mm Push Button with Black Cap.STEP, 12mm Push Button with Blue Cap.STEP, 12mm Push Button with Red Cap.STEP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]
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2025-02-19 fix: fix info about wrong LDO and about wrong values of capacitors
2025-02-19 fix: remove case from repo, for future move it into docs and sepparate resource like makerworld
    [Bottom_lilka_v1_18650.stl, Bottom_lilka_v1_none.stl, Top_lilka_v1.stl]
2025-05-15 fix: optimise pwm update
    [gpiomanager.cpp, gpiomanager.h]
2025-05-19 Resolve cpp-check and clang-format violations
    [lilcatalog.cpp]
2025-05-19 Fix code review commend
    [lilcatalog.cpp]
2025-05-20 Fix log and description
    [lilcatalog.cpp]
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2025-06-15 remove: remove hardware folder from main repo
    [12mm Push Button with Black Cap.STEP, 12mm Push Button with Blue Cap.STEP, 12mm Push Button with Cap.STEP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]
2025-06-15 fix: fix links to folders with current actual commits on submodules repos
